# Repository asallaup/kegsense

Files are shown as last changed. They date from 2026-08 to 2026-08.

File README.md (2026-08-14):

# Sallaup KegSense

Keg weight/level monitoring for a keezer, by **Sallaup Electronics**.

Each keg sits on a load cell. A per-keg board reads the weight and sends
it over a wired connection to a central unit, which streams each keg's
brew name + weight out to a small OLED mounted right at that keg's own
tap (its own tiny MCU drives the display, right where you're pouring
from) and mirrors the same view to a web dashboard you can check
remotely — so you know how much beer is left without opening the lid.

## System overview

```
 Keg 1  --RJ11-->  |                |
 Keg 2  --RJ11-->  |     KegHub     |  --RJ45-->  KegStation
 Keg 3  --RJ11-->  |   (passive     |             (Raspberry Pi,
 Keg 4  --RJ11-->  |    wiring      |              web dashboard)
 Keg 5  --RJ11-->  |    panel)      |                   |
                    |                |                   v
                                              KegDisplay chain (OLED +
                                              Trinket M0 per tap, daisy-
                                              chained tap to tap)
```

Each keg's board is a **KegSensor** module (HX711 + 4 half-bridge strain
gauge sensors + RJ11 out). No Wi-Fi or radio anywhere inside or on the
keezer itself — everything in there is wired; KegStation, which sits
outside the keezer, is the only part with Wi-Fi (for the dashboard).

## Status

- 🚧 **KegSensor** (per-keg module) — **draft design**, still likely to
  change. Schematic + PCB routed and DRC-clean, 3D-printable case
  designed and validated, fab-ready Gerbers generated — but none of it
  has been physically built, and it hasn't been ordered/printed yet.
  Treat as a working draft, not a locked design, until it's been through
  a real build.
- 🚧 **KegHub** (in-keezer passive wiring panel) — wiring design
  (RJ11/RJ45 pin conventions, parts list) documented; physical build not
  started.
- 🚧 **KegStation** (central unit) — architecture decisions documented
  (platform, Wi-Fi provisioning, update mechanism, KegSensor-interfacing
  daemon language); no hardware or software built yet.
- 🚧 **Keg platform** (load cell mounting) — one part done: a derived,
  validated OpenSCAD load cell holder. Top/bottom mounting plates around
  it not designed yet.

## Repo layout

- [`hardware/kegsensor/`](hardware/kegsensor/) — KegSensor: per-keg
  sensor wiring (RJ11 pin conventions, parts list), KiCad schematic/PCB
  project, 3D-printable case (OpenSCAD), fab-ready Gerbers, and the load
  cell platform holder. See its own README(s) for details, known
  assumptions to verify against real hardware, and how to regenerate
  everything.
- [`hardware/keghub/`](hardware/keghub/) — KegHub: the in-keezer passive
  wiring panel design (RJ45 pin conventions, parts list, bench-test
  checklist).
- [`hardware/kegstation/`](hardware/kegstation/) — KegStation (central
  unit) planning doc: decisions made so far and what's still open.
- [`hardware/kegdisplay/`](hardware/kegdisplay/) — KegDisplay (per-keg
  tap indicator) planning doc: a small OLED + its own Trinket M0 MCU per
  tap, daisy-chained back to KegStation, each tap showing its own keg's
  brew name + weight directly.

## Before ordering/building anything

Both `hardware/kegsensor/README.md` and `hardware/kegsensor/wiring.md`
flag specific assumptions (HX711 module pin order, sensor diagonal
wiring) that need confirming against the actual parts once they're in
hand — cheap to fix now, annoying after boards are fabricated.

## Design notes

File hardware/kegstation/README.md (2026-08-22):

# KegStation — Sallaup Electronics

Part of the **Sallaup KegSense** keg-monitoring system, made by
**Sallaup Electronics**.

**KegStation** is the central unit: reads all 5 KegSensor modules over
the wired in-keezer hub connection, drives each tap's WS2812 fill-bar
LEDs directly (see [`../kegdisplay/`](../kegdisplay/) — no per-tap
MCU, KegStation lights however many LEDs correspond to that keg's
remaining %), and hosts a web dashboard mirroring the same information
remotely. Brew-name display is a separate concern, handled (if built)
by the experimental [`../kegtag/`](../kegtag/) add-on and its own hub,
not by KegStation streaming text down the LED chain.

This is a planning doc — no hardware or software has been built yet.
Captures decisions made so far so they aren't lost before implementation
starts (see `hardware/kegsensor/wiring.md` and `hardware/keghub/README.md`
for the equivalent docs that preceded the KegSensor module).

## Decisions so far

- **Platform: Raspberry Pi Zero 2 W, settled — not Pi 4, Pi 5, or a
  larger board.** Originally Pi 4, picked over Zero 2 W solely because
  the (now-dropped, see Touchscreen/display below) Touch Display 2
  needed a DSI connector the Zero series doesn't have — once the display
  requirement changed to a button-driven I2C OLED, that blocker went
  away and Zero 2 W became the smallest/cheapest board that still meets
  every other requirement. Still ruled out vs. Pi 5 for the same reasons
  as before: power budget (Pi 5 draws roughly double idle power and
  wants a 27W supply, inflating the shared-PSU sizing above for headroom
  this project's workload doesn't need) and GPIO library maturity
  (`pigpio`, the battle-tested choice for the HX711's precise bit-banged
  timing, does not support Pi 5's RP1 GPIO chip at all). Zero 2 W's
  SoC (RP3A0) uses the same classic GPIO peripheral family as Pi 3/4,
  not Pi 5's RP1, so `pigpio` and the whole KegSensor-interfacing scheme
  below carry over unchanged. Has built-in Wi-Fi (2.4GHz only, unlike Pi
  4's dual-band — irrelevant here, Comitup's captive portal works fine
  over 2.4GHz) + Bluetooth 4.2/BLE (also unused by KegStation itself),
  so still no wireless add-on hardware needed. Fixed at 512MB RAM (no
  variants) — expected to be plenty given the now-lighter workload (no
  browser/desktop GUI, just the C daemon, the button/OLED interface, and
  a modest web dashboard), though with less margin than the Pi 4 RAM
  options would have had.
- **Connectivity**: reads the 5× KegSensor modules over the wired hub
  connection (shared SCK + 5× DT + power, see
  `hardware/kegsensor/wiring.md` and `hardware/keghub/README.md`) —
  direct to the Pi's GPIO header, 3.3V logic throughout, no level
  shifters needed. No Wi-Fi/radio inside the keezer itself (unchanged
  from the original hub design constraint) — KegStation sits outside the
  keezer, so its own Wi-Fi is unrelated to that constraint.
  - **Bench/debug connector, settled: a 6th, dedicated DT channel — not
    shared with any of the 5 production kegs.** A second RJ14 (6P4C)
    jack, same connector type as KegSensor's own J7, mounted directly on
    KegStation, for plugging in and testing a spare KegSensor without
    touching KegHub or any deployed keg. Shares the common SCK/3.3V/GND
    rails (safe — those are shared across all kegs anyway) but gets its
    **own dedicated DT GPIO pin**, deliberately not reusing one of the 5
    production DT lines: sharing a DT line would mean two HX711 modules
    could end up driving the same GPIO simultaneously if a real keg is
    plugged into KegHub at the same time as a test sensor here — a real
    electrical bus-contention risk, not just a software mixup. One extra
    GPIO pin is cheap on Zero 2 W's 40-pin header (no touchscreen, and
    discrete buttons instead of a component-heavy nav switch, both free
    up pins), so paying that cost to remove a real correctness risk is
    worth it. The daemon reads this 6th channel too, but keeps it out of
    the normal 5-keg dashboard/fill-bar logic — surfaced only through a
    separate bench-test view, not mixed into live readings.
- **Wi-Fi provisioning**: [Comitup](https://davesteele.github.io/comitup/)
  — Pi broadcasts a captive-portal setup network (SSID `KegStation-Setup`)
  on first boot / when no known network is available, works from any
  phone's browser via the OS-level captive-portal mechanism (no app
  needed, no Web Bluetooth iOS limitation). Chosen over BLE provisioning,
  which has no mature ready-made tool on Linux/Raspberry Pi.
  - **Branding**: Comitup's setup pages (`comitup_web/templates/` —
    `index.html`/`connect.html`/`confirm.html` + `css`/`js`/`images`) are
    plain by default (no existing logo to fight against), but the
    template path is hardcoded in `comitupweb.py`
    (`/usr/share/comitup/templates`, confirmed by reading the source —
    no config/env override exists). Branding means overwriting those
    installed files with our own after installing the `comitup` package,
    as part of KegStation's own setup script — and re-applying that after
    any future `comitup` package upgrade, since there's no supported way
    to point it at a separate custom template directory.
- **Software updates**: git-based. KegStation's code lives in a git repo
  on the Pi; updating is `git pull` + restart the service, rollback is
  checking out a previous tag. Deliberately not a fleet OTA framework
  (Mender, balena) — this is one device, not a fleet.
  - **Trigger**: manual button in the web dashboard (an admin
    action that runs the pull + restart on demand) — not automatic on a
    schedule, so an update never lands unannounced (e.g. mid-party), and
    not SSH-only, so it doesn't require terminal access for routine use.
- **KegSensor-interfacing layer: C.** The HX711 protocol needs precise
  clock-pulse timing to bit-bang correctly (shared SCK + 5× DT, per
  `hardware/kegsensor/wiring.md`) — C gives predictable low-level GPIO control
  that's harder to guarantee in a higher-level language. This is scoped
  specifically to the hardware-interfacing piece, not necessarily the
  rest of KegStation's software (dashboard, etc. — still open, below).
  - **Interface to the rest of the system**: a small daemon, written in
    C, that reads all 5 kegs on a fixed interval and writes current
    readings to a local JSON/text file. Whatever ends up driving the
    KegDisplay LED chain and web dashboard just reads that file —
    simplest possible hand-off, easy to debug by hand (`cat` the file),
    no IPC to build or maintain. Chosen over a Unix socket/local IPC
    (more real-time, more moving parts) and over having the C program
    also drive the LED chain/dashboard directly (would remove the
    option to pick a different, easier language for that higher-level
    part later).
  - **GPIO library: `pigpio`.** The traditional, most battle-tested
    choice for the HX711's precise bit-banged clock timing — viable now
    that Pi 4 is settled (below), unlike on Pi 5 where it doesn't
    support the RP1 GPIO chip at all.
  - **Disconnected-cable detection: a per-keg DT timeout watchdog,
    settled.** The RJ14 wiring has no spare conductor for a dedicated
    presence-detect signal (all 4 — GND/VCC/SCK/DT — are already used),
    so detection is inferred from HX711 protocol behavior instead: each
    keg's DT line should pulse low on every new conversion (~100ms or
    ~12.5ms depending on the HX711's rate setting). If a keg's DT line
    produces no valid ready-pulse within 2-3× that interval, the daemon
    marks that keg as **not responding** rather than reporting a stale
    or garbage weight. The DT input needs an internal or external
    pull-up so "disconnected" reads as a consistent, predictable HIGH
    instead of noisy floating, making the timeout check reliable
    instead of racy. Surfaced as a distinct per-keg status in the
    readings file (not folded into the weight/percentage fields) — see
    Display + input below for how it's shown on-unit, and note
    KegDisplay's per-tap fill bar shouldn't just show 0% for this case
    either, since that reads as "keg is empty" rather than "sensor
    isn't talking" (still open, see KegDisplay's own README).
- **Tare/weight calibration: must work fully standalone at the unit
  itself — no web browser and no external device (phone/laptop/SSH)
  required.** This is a hard requirement, not a convenience preference,
  so the on-unit button + OLED interface (below) is the primary
  calibration interface. A `kegcal` CLI program still exists underneath
  as the actual implementation (and an SSH-accessible fallback for
  development/debugging) — the button/OLED UI shells out to the same
  commands rather than duplicating calibration logic, same relationship
  originally planned between `kegcal` and a future dashboard, just with
  the button/OLED interface as the primary caller instead of the web
  dashboard.
  - `kegcal tare <keg>` — reads that keg's *current* raw ADC value (from
    the daemon's readings file) and stores it as the tare reference.
  - `kegcal setfull <keg> <grams>` — same, but stores it as the "full"
    reference point at a known weight in grams. That known weight can be
    either the actual full keg's spec weight (so the reference doubles as
    the "how much is left" baseline) or a separate known calibration
    mass — the tool works the same either way, this only affects what
    number you type in.
  - **On-unit UI note**: the button/nav-switch interface offers Set Full
    as a **preset selection** (e.g. 5/10/15/20kg), not free numeric
    entry — implementing the "actual full keg's spec weight" option
    above via list-selection rather than typing a number, consistent
    with every other step in the flow being a scroll-and-select action
    (see Display + input above). The presets must be the *real* spec
    weight (liquid + keg tare) of whatever keg sizes are actually in
    use, not round numbers — an inaccurate preset introduces a
    systematic error across every future reading for that keg, since
    it directly anchors the calibration math. `kegcal setfull` itself
    is unaffected — it still just takes a gram value; only the on-unit
    UI constrains which values are offered.
  - **On-unit calibration wizard, designed**: tare and setfull are one
    continuous guided flow, not two separate manual actions, with a
    confirmation prompt gating each raw-ADC read so a mistimed press
    can't bake in a bad calibration point:
    1. Select **Tare** from the keg's menu (nav switch)
    2. Prompt: "Place empty keg on scale, then confirm" — user places
       it, presses select
    3. System reads the current raw ADC → internally calls
       `kegcal tare <keg>`, stores it as the 0% reference
    4. Prompt: select a known full weight (the preset list above)
    5. Prompt: "Place [selected weight] on scale, then confirm" — user
       places the full keg (or a calibration mass matching that
       weight), presses select
    6. System reads the current raw ADC → internally calls
       `kegcal setfull <keg> <grams>` with the chosen preset value
    7. Both calibration points now stored — the daemon can compute
       that keg's tare↔full linear scale from here on
    - **A Back/cancel option at every confirmation prompt** — lets the
      user back out if the keg isn't actually placed right or the
      wrong preset got selected, rather than being forced through to a
      bad read.
  - Calibration values live in a separate config file (e.g.
    `calibration.json`), which the daemon just re-reads on its normal
    cycle — no signaling/IPC needed for `kegcal` to take effect.
  - The daemon's readings file includes both the raw ADC count and the
    calibrated weight (once calibration exists) per keg, since `kegcal`
    needs to read the live raw value to know what to record.
  - **Not yet built** — see below.
- **Per-tap indicator is just an LED fill level now, no per-tap
  detail/MCU at all.** Each tap's WS2812 bar (see
  [`../kegdisplay/README.md`](../kegdisplay/README.md)) is lit directly
  by KegStation over the shared chain — no brew name, no numeric
  weight, no OLED, no per-tap microcontroller. This superseded both the
  earlier button + resistor-ladder + KegStation-touchscreen scheme and
  the later ATtiny1614+OLED-per-tap scheme (see git history and
  KegDisplay's own revision note) — no button/detail hardware to read
  at any tap.
  - **Wiring run this still creates**: KegStation sits outside the
    keezer (see System overview in the root README), but taps are
    mounted at the keezer itself, so a physical run out to each tap is
    still needed regardless of what's at the far end — a wired
    connection either way (consistent with the no-WiFi-in-the-keezer
    rule, which is about radios, not wired signals).
  - **KegStation's job for this chain**: light however many LEDs
    correspond to each keg's remaining % as a bottom-up fill bar, in
    tap order down the KegDisplay daisy chain (see the chain-position
    addressing scheme in KegDisplay's own README) — not yet
    implemented, see Still Open.
- **Power: one shared 5V supply, star-wired — not drawn through the
  Pi's own GPIO pin/trace.** A single 5V PSU, sized for worst-case total
  draw (Pi + KegSensor bus + KegDisplay LEDs), feeds two separate direct
  wire runs: one straight to the Pi (its own 5V input), one straight to
  the KegDisplay chain's power input — neither run passes through the
  other. The actual hard requirement was never "two physical supplies,"
  it was "LED current must never pass through the Pi's own GPIO 5V
  pin/trace" (see Why below) — one adequately-sized PSU with star wiring
  satisfies that just as well as two separate PSUs would, with less
  hardware.
  - **Why the Pi can't just pass LED current through**: WS2812 LEDs draw
    up to ~60mA each at full white (20mA × 3 channels). ~18-26 LEDs/tap
    × 5 taps ≈ 130 LEDs total → up to ~7.8A (~39W) worst case,
    realistically a few amps even at moderate brightness — more than the
    Pi's GPIO 5V pin/trace is rated to pass through, regardless of what
    supplies it. Standard WS2812 practice regardless of platform: the
    LED chain's power connects directly to its supply, not routed
    through the controller board.
  - **Tradeoff accepted by sharing one PSU**: an LED-side short/
    overcurrent event could brown out the whole shared supply, taking
    the Pi (touchscreen/calibration/reset) down with it — two
    independent PSUs would isolate that risk, one shared PSU does not.
    Accepted here in favor of one fewer component.
  - **PSU model: Mean Well GST60A05-P1J (5V, 6A, 30W), settled — paired
    with a mandatory software brightness/current cap.** Theoretical
    worst case (130 LEDs × 60mA full-white + Pi's ~1.5A) is ~9.3A, well
    past this unit's 6A rating — Mean Well's built-in overload
    protection fails safe (hiccup-mode shutdown) rather than
    dangerously, but a trip still browns out the Pi along with the
    LEDs (see Tradeoff above), so the LED-driving code (see Still Open)
    **must** cap total simultaneous current with margin under 6A —
    e.g. single-channel color instead of white, and/or an explicit
    brightness ceiling — not just assume typical usage stays low.
    Picked over the 10A Mean Well LRS-50-5 alternative (which needs no
    software cap) for its smaller size (125×50×31.5mm captive-cable
    wall-wart vs. 128×97×38mm screw-terminal box) and simpler
    plug-and-play wiring (captive DC cable + standard IEC C14 cord,
    vs. terminating both AC and DC leads by hand).
  - **Physical implementation: a plain fixed 5V DC power brick
    (the GST60A05 above), not a USB-C PD charger.** A generic
    USB-C PD wall charger's default/fallback output (before any
    negotiation) is typically just 5V at a modest current (often 3A) —
    getting more current specifically *at* 5V, rather than the charger
    bumping voltage up instead, needs either a PD-trigger chip
    negotiating for it or a charger that happens to default that way,
    neither guaranteed. A plain fixed-5V brick sidesteps that entirely:
    no negotiation, current rating is just whatever the brick is rated
    for. Its 5V/GND wires go into a small **non-negotiating USB-C
    breakout board** (just exposes VBUS/GND pads with basic CC
    pull-down resistors, no PD chip) mounted as the single external
    power-entry connector on the KegStation enclosure — the Pi's own
    onboard USB-C port stays unused/hidden inside the case. From the
    breakout's pads, two star-wired runs go out: one to the **Pi's GPIO
    5V pin** (bypassing its onboard USB-C port), one straight to **J1's
    5V/GND** for the LED chain — same star topology as before, just with
    a concrete connector at the wall-facing end instead of bare PSU
    leads.
  - **Considered and rejected: an internal 220V AC→5V DC module** (e.g.
    Mean Well RS-25-5), with just a mains cord entering the enclosure
    instead of an external DC brick. Rejected because it brings mains
    voltage inside a custom DIY enclosure — a different safety class
    than a certified external wall-wart, needing its own fusing,
    creepage/clearance, and an isolated compartment to get right, none
    of which is worth taking on for a one-off hobby build vs. buying an
    already UL/CE-certified external supply.
  - **Also considered and declined: a panel-mount IEC C14 inlet on the
    enclosure with the PSU module mounted inside it** (safer than the
    fully-DIY version above, since both the inlet — typically bundled
    with its own fuse holder/switch — and the PSU module itself would
    still be pre-certified parts). Declined anyway to keep it simple:
    the external brick stays external, KegStation's only power connector
    is the low-voltage USB-C breakout.
  - See `power_wiring_diagram.png` (`generate_power_wiring_diagram.py`)
    for the star-topology layout: the Pi and the KegDisplay chain each
    run their own wire straight back to the shared PSU. The PSU's 5V/GND
    and the Pi's DATA line stay separate conductors electrically but
    physically converge at J1 (KegDisplay's existing 3-pin JST-PH
    chain-in connector) into one cable for the run out to tap 1 —
    bundling into one physical cable is fine, it's only the electrical
    source of each conductor that has to stay separate.
- **One external-to-the-Pi component needed: a logic-level shifter IC
  on the KegDisplay DATA line.** KegHub/KegSensor need none (3.3V logic
  throughout, see Connectivity above) — but KegDisplay's WS2812 strip is
  a 5V logic part, expecting a DATA-high signal above roughly 0.7×VDD ≈
  3.5V, and the Pi's GPIO only outputs 3.3V. That's marginal enough
  (a well-known flaky case for Pi+WS2812 projects, especially at the
  *first* LED — every LED after that regenerates the signal at its own
  full 5V output) that a small one-chip level shifter (e.g. 74AHCT125 or
  74HCT14) belongs between the Pi's DATA GPIO pin and J1's DIN. One
  small IC, only needed at that single connection point, powered off the
  same shared 5V rail. **Not yet added to the BOM/wiring** — see the
  updated `power_wiring_diagram.png`.
- **PIR motion sensor for occupancy-based LED power saving: HC-SR501,
  settled.** The KegDisplay chain doesn't need to stay lit when nobody's
  in the room — running all 5 taps' LEDs continuously is the dominant
  chunk of the power budget the GST60A05 (above) is already sized close
  to the edge of. The HC-SR501 (~$1-2, 3-pin VCC/GND/OUT) wired to one
  Pi GPIO pin detects room entry; its digital output is already
  3.3V-logic level, so — unlike the WS2812 DATA line — **no level
  shifter needed** for this one. Another small external-to-the-Pi
  component, but a simple, well-supported one.
  - **Behavior**: motion resets an inactivity timer in the LED-driving
    code; while the timer's running, the chain shows the normal
    fill-bar; on timeout with no further motion, the chain **dims to a
    low brightness** (settled — not a full blank), cutting most but not
    all of the LED power draw while keeping a faint always-visible
    fill-level readable at a glance, then returns to normal brightness
    on the next motion event.
  - **Mounting location: on the KegStation enclosure itself, settled.**
    No remote sensor needed — KegStation already sits in the same room
    as the keezer (see System overview in the root README), so a PIR
    mounted on its own case covers room-entry detection without a
    separate wired/wireless sensor unit.
  - **Inactivity timeout: user-configurable, settled** — not a
    hardcoded constant. Lives in the same config file the daemon
    already re-reads on its normal cycle (alongside `calibration.json`,
    see Tare/weight calibration above), so it's adjustable without a
    code change or restart-losing edit — a sensible default ships, but
    the actual duration is a setting, not a fixed value baked into the
    LED-driving code.
  - **Dimmed brightness level: 15% of normal, settled** — low end of
    the tradeoff (favors power savings over glance-readability from
    across the room), still configurable like the timeout above rather
    than hardcoded, 15% is just the shipped default.
  - **Not yet decided**: the default timeout duration.
- **Two distinct reset mechanisms: soft reset via power cycling (no
  dedicated button), factory reset via a dedicated physical button.**
  - **Soft reset = power off/on.** Just reboots the Pi/services, no data
    touched (WiFi creds, calibration all survive) — no dedicated button
    needed, a power switch (or just unplugging) already does this.
  - **Factory reset = a recessed pinhole button** (needs a pin/paperclip
    to press, like a router's reset — not something bumped by accident),
    wired to a GPIO the daemon watches. Held ~5-10s: clears WiFi
    credentials (falls back to Comitup's setup portal) and wipes
    `calibration.json`. Deliberately a physical button, not a
    software menu item — has to work even if the display UI or
    software is hung/misconfigured, which is exactly the case a factory
    reset needs to recover from.
- **Display + input: a 4.0" color IPS TFT (ILI9488, 480×320, "No Touch"
  variant) plus physical navigation buttons, not a touchscreen.**
  Superseded an intermediate plan (2.42" monochrome I2C OLED, see git
  history) — chosen over that OLED specifically for future headroom:
  a 480×320 color panel leaves real room to grow the on-unit UI later
  (WiFi signal bars, brew name, per-keg level graphs, multiple fields
  at once) without another hardware swap, which the OLED's 128×64
  monochrome canvas couldn't accommodate gracefully. Both options were
  chosen over the official Raspberry Pi Touch Display 2 (5", SC1975,
  ~$40/€53) to cut cost — that touchscreen was the single largest line
  item in KegStation's BOM, and dropping it also unblocked the Platform
  change to Zero 2 W above (the Touch Display 2's DSI requirement was
  the only thing ruling Zero 2 W out). Buttons still satisfy the
  standalone-calibration hard requirement below just as well as a
  touchscreen — the touchscreen was originally picked for being the
  *simplest* single-component option ("no separate buttons/encoder to
  wire up"), not because buttons don't work.
  - **"No Touch" variant, deliberately** — a touch variant exists on the
    same listing, but adding touch back would partly undo the reason
    the Touch Display 2 was dropped, and the design already commits to
    buttons for input.
  - **Interface: SPI** (~8 pins without touch: VCC, GND, CS, RESET, DC,
    SDI/MOSI, SCK, LED backlight) — more GPIO than the OLED option's 2
    pins (SDA/SCL) would have used, but Zero 2 W's 40-pin header still
    has plenty of room alongside the navigation buttons, PIR sensor, and
    factory-reset button.
  - **UI approach: a lightweight embedded graphics library** (e.g.
    LVGL-style), not a browser/desktop stack — keeps the richer color UI
    well within Zero 2 W's 512MB RAM, same conclusion as the OLED plan
    reached, just confirmed explicitly for the bigger screen too.
  - **Driver note**: at least one buyer of this exact listing received
    an ILI9484-branded chip instead of the advertised ILI9488 ("tho
    functionally perfect") — worth being ready to try adjacent
    ILI948x drivers in software if the advertised one doesn't
    immediately work, same generic-module caveat as the OLED's
    SSD1306-vs-SSD1309 mismatch.
  - **Input: a 5-way tactile navigation switch (up/down/left/right +
    center select), settled — not discrete buttons, not a rotary
    encoder.** 5 GPIO pins, each a simple digital read (no quadrature
    decoding). Chosen over a rotary encoder specifically because the
    on-unit UI is planned to grow into a genuinely 2D layout later
    (multiple screens/tabs navigated left/right, e.g. WiFi signal,
    brew info — see Display note above) — a rotary encoder only gives
    one rotational axis, which fits a purely linear list-menu well but
    not a 2D one. Traded away the encoder's main advantage (fast,
    precise numeric entry) deliberately, since the one place that
    mattered — Set Full's weight value — moved to preset selection
    instead (see Tare/weight calibration below), removing the need for
    free numeric entry entirely. Not yet wired — GPIO pin assignment
    not yet decided (see Still Open).
  - Still satisfies "no per-tap detail/MCU" below — this is KegStation's
    own on-unit display, unrelated to the per-tap LED fill bars.
  - **Sensor-connection status: red/green per-keg indicator, settled.**
    Reflects the DT timeout watchdog above directly — green means that
    keg's HX711 is responding normally, red means it's not (cable
    unplugged, unpowered module, or a dead sensor — the daemon can't
    distinguish which, just that the keg isn't reporting). Shown
    per-keg on the main screen alongside each keg's fill level, so a
    disconnected sensor is obvious at a glance rather than silently
    reading as an empty keg.

## Still open

- **All of the above C daemon / `kegcal` work is design-only, not yet
  implemented.** Deliberately holding off writing the code until a
  physical Raspberry Pi + HX711 setup exists to test against, rather than
  writing GPIO-bit-banging code that can only be verified once real
  hardware shows up — the risk of subtle timing/wiring bugs surviving
  unnoticed in untestable code isn't worth it here (same reasoning as
  everything else in this project: validate against something real
  before calling it done, not just "it compiles").

- Software language/stack for everything *other* than the KegSensor
  interfacing daemon (Python is the natural fit for the Pi's web
  library support, but not yet committed to) — the daemon just needs to
  read a file, so it can be written in anything.
- Whether to build a small interface PCB (breaking out the hub's RJ45
  connection and the KegDisplay chain's UART-ish GPIO pins to the Pi's
  header) or wire it directly on a protoboard/HAT — these are native Pi
  GPIO peripherals, no special adapter needed, unlike the original
  RS-485 design's USB-RS485 requirement.
- **KegStation's own KegDisplay-chain code**: the piece that reads the
  daemon's readings file and lights each tap's LED fill bar to match
  its keg's remaining % — not yet written (see
  [`../kegdisplay/README.md`](../kegdisplay/README.md) for the chain
  protocol's own still-open details). **Must include a current/
  brightness cap** (color choice + max brightness ceiling) keeping
  total worst-case draw safely under the GST60A05's 6A — see Power
  above for why this is a hard requirement, not a nice-to-have. **Must
  also include the PIR-driven occupancy timer** (see PIR motion sensor
  above) that dims the chain when the room's been empty past the
  timeout.
- **Calibration UI's own screen flow — now designed**, see the on-unit
  calibration wizard under Tare/weight calibration above. Not yet
  implemented in code, and GPIO pin assignment for the 5-way nav
  switch isn't decided either.
- Web dashboard framework, exact GPIO pin mapping for the shared-SCK +
  5×DT KegSensor scheme (now 6×DT including the dedicated bench/debug
  channel above), and the on-disk format/path for the readings file the
  C daemon writes.
- Physical enclosure for KegStation itself (separate from the KegSensor
  case already built) — depends on the display/button decision above,
  and now also needs a pinhole cutout reaching the factory-reset button.
- **Factory-reset daemon logic and GPIO pin choice** — not yet written;
  needs to debounce/time the ~5-10s hold, then clear WiFi creds +
  `calibration.json` and restart the relevant services.
- **LED supply sizing and injection point** — exact PSU wattage (depends
  on final LED count once a strip is picked, and whatever brightness/
  color policy the fill-bar code ends up using), and where in the
  KegHub/KegDisplay wiring the injected 5V actually connects.

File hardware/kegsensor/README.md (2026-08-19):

# KegSensor — Sallaup Electronics

Part of the **Sallaup KegSense** keg-monitoring system, made by
**Sallaup Electronics**.

**KegSensor** is the per-keg carrier board: hosts the HX711 breakout
module, terminates the 4 half-bridge sensor leads (bussed/paired per
`wiring.md`), and exits to the in-keezer hub over RJ11. One board
per keg.

KiCad 9 project. Both schematic and PCB (footprints placed, fully routed,
2-layer) are done and validated (see Validation below).

## Fabrication

**Send `KegSensor_RevA_gerbers.zip` to the PCB manufacturer.** That's the
complete, standard deliverable — a fab house doesn't need the `.kicad_pcb`
file itself (though most modern ones, e.g. JLCPCB/PCBWay, also accept it
directly if you'd rather skip the export step). It contains, generated via
`kicad-cli pcb export gerbers`/`export drill`:

| File | Contents |
|---|---|
| `*-F_Cu.gtl` / `*-B_Cu.gbl` | Copper layers (top/bottom) |
| `*-F_Mask.gts` / `*-B_Mask.gbs` | Soldermask |
| `*-F_Silkscreen.gto` / `*-B_Silkscreen.gbo` | Silkscreen (incl. the KegSensor/Rev A branding) |
| `*-F_Paste.gtp` / `*-B_Paste.gbp` | Solder paste stencil (only matters if you're getting a stencil cut too) |
| `*-Edge_Cuts.gm1` | Board outline |
| `*-job.gbrjob` | Gerber job file (metadata some fabs use to auto-detect stackup) |
| `*-PTH.drl` / `*-NPTH.drl` | Drill files — plated (component holes) and non-plated (J7's 2 mounting bosses) separately |

The individual files are also in `fab/` (not zipped) if a fab's upload
tool wants them one at a time rather than as an archive, along with
`*-drl_map.pdf` drill maps (human-readable cross-reference of hole
sizes/positions — not needed by the fab, just useful if you want to
sanity-check the drill file yourself).

**Order quantity**: 5 (one per keg) — check the fab's pricing breaks
first, since many charge nearly the same for 5 as for 10.

**Before ordering**: resolve the two items under Known assumptions below
(J6 pin order, SIG_POS/SIG_NEG diagonal pairing) if you haven't already —
both require rerouting, which is easy to do before fabrication and
annoying after.

Regenerate the fab package after any board changes:
```
kicad-cli pcb export gerbers --layers "F.Cu,B.Cu,F.Paste,B.Paste,F.SilkS,B.SilkS,F.Mask,B.Mask,Edge.Cuts" -o fab/ keg_sensor_module.kicad_pcb
kicad-cli pcb export drill --format excellon --excellon-separate-th --excellon-units mm --generate-map --map-format pdf -o fab/ keg_sensor_module.kicad_pcb
```

## Files

- `keg_sensor_module.kicad_pro` — project file, open this in KiCad
- `keg_sensor_module.kicad_sch` — schematic (see `keg_sensor_module.pdf` for
  a quick look without opening KiCad)
- `keg_sensor_module.kicad_pcb` — routed board, 155×90mm outline, 4× M3
  clearance mounting holes at the corners (6,6)/(150,6)/(6,84)/(150,84)
  board-local (see `keg_sensor_module_top.png` / `_bottom.png` for a quick
  look, or `keg_sensor_module_3d.png` for an isometric render with real
  component shapes)
- `case.scad`, `case_base.stl`, `case_lid.stl` — 3D-printable enclosure,
  see Case below
- `generate_schematic.py` / `generate_pcb.py` — the scripts that generated
  the two files above. If a pin-order assumption turns out wrong once you
  have the real hardware in hand (see Known assumptions below), fix it in
  the script and rerun rather than hand-editing the `.kicad_sch`/`.kicad_pcb`
  text. Requires `pip install sexpdata` and a local KiCad 9 install (the
  scripts read symbol/footprint definitions straight out of
  `/Applications/KiCad/KiCad.app/Contents/SharedSupport/`).
  **If you have this project open in KiCad while regenerating, close and
  reopen the PCB editor afterward** — the scripts overwrite the file on
  disk directly, which KiCad won't pick up in an already-open editor.

## Connectors

| Ref | Part | Pins |
|-----|---|---|
| J1 | Screw terminal, sensor "FL" corner | 1=E+ (Red) 2=E- (Black) 3=Signal (White) |
| J2 | Screw terminal, sensor "FR" corner | 1=E+ (Red) 2=E- (Black) 3=Signal (White) |
| J3 | Screw terminal, sensor "BR" corner | 1=E+ (Red) 2=E- (Black) 3=Signal (White) |
| J4 | Screw terminal, sensor "BL" corner | 1=E+ (Red) 2=E- (Black) 3=Signal (White) |
| J5 | Female header, HX711 load-cell side | 1=E+ 2=E- 3=A+ 4=A- |
| J6 | Female header, HX711 digital/power side | 1=GND 2=DT 3=SCK 4=VCC |
| J7 | RJ11 jack to hub (RJ14 6P4C) | 1=GND 2=VCC 3=SCK 4=DT |

Nets: `EXC_POS`/`EXC_NEG` bus J1–J4 pin1/pin2 into J5; `SIG_POS` ties
J1+J3's signal leads (diagonal) into J5.A+, `SIG_NEG` ties J2+J4's into
J5.A-; J6↔J7 pass GND/DT/SCK/VCC straight through to the hub cable.

## Known assumptions to confirm against real hardware

- **J6 pin order (GND,DT,SCK,VCC)** is a common layout for these HX711
  breakouts but varies by manufacturer — check your module's silkscreen
  before soldering the header, fix in `generate_schematic.py` if different.
- **Diagonal pairing (J1+J3→SIG_POS, J2+J4→SIG_NEG)** depends on which
  corner each sensor physically sits at and its mounting orientation —
  follow the kit's included wiring diagram; if the reading comes out
  inverted or dead-flat, swap the SIG_POS/SIG_NEG pairing.
- **J7 uses KiCad's stock RJ14 (Connfly DS1133-S4) footprint** — a genuine
  6P4C connector (6-position body, 4 contacts), which is mechanically what
  "RJ11" means in practice for a 4-wire line cord (RJ9, used in an earlier
  draft of this board, is a different 4P4C body meant for phone handset
  cords, not line cords — swapped out after review). Still worth checking
  the exact part you buy against this footprint's dimensions before
  ordering the board, since real-world RJ11 jacks vary in body/pin
  spacing between manufacturers.

## Pending design change (decided, not yet applied to the KiCad files)

- **J1-J4 switching from `TerminalBlock_bornier-3_P5.08mm` to
  `TerminalBlock_Phoenix_PT-1,5-3-3.5-H_1x03_P3.50mm_Horizontal`** —
  3.5mm pitch instead of 5.08mm, to shrink the board. Checked two 3.5mm
  candidates before picking, since pitch alone doesn't guarantee a
  smaller footprint: WAGO 2601-1103 (3.5mm pitch, but 13×15.5mm
  courtyard — *taller* than the current part, would make the board
  worse in the already-tight Y direction) vs. **Phoenix
  PT-1,5-3-3.5-H** (3.5mm pitch, 11.5×8.6mm courtyard — narrower than
  the current 15.6×8mm, same horizontal thin-profile mounting style).
  Phoenix is the one to use.
  - **Not yet applied** — `generate_schematic.py` (footprint string +
    `PIN_DX` pin spacing, currently tuned for 5.08mm) and
    `generate_pcb.py` (J1-J4 placement/routing, extensively DRC-iterated
    around the current footprint's exact pad positions — see Routing
    below) both need rework, not just a footprint-string swap.
  - **Deliberately deferred to Phase 6** of `IMPLEMENTATION_PLAN.md` —
    the first prototype is being hand-wired on perfboard, not the
    custom PCB, so this change isn't blocking anything yet. Apply it
    once Phase 5 passes and the real PCB actually gets ordered.

## Physical layout

Sensor terminals (J1–J4) sit in a horizontal row close to the board's top
edge (y≈10, 30mm pitch), ordered FL/BR/FR/BL left-to-right (not source
order) so the diagonal pairs (SIG_POS = J1+J3, SIG_NEG = J2+J4) sit next to
each other. Unrotated (angle=0, the library's default orientation) — an
earlier version rotated each part -90° to make the bus routing trivial
(every part's pins landing on their own single x instead of sharing a y
with every other part's pins), but that was a routing convenience, not a
requirement; unrotated works too, it just needs more deliberate lane/layer
routing (see below). J5 (HX711 load-cell side) sits below the row, on the
same side — these are the noise-sensitive analog connections, kept short
and away from the digital/power section. J6 (HX711 digital side) sits with
J5; J7 (RJ11 to hub) is rotated 180° and placed flush with the board's
*bottom* edge (y=90) — moved here from the right edge. Any edge-mounted
connector belongs at the board edge as a matter of course, independent of
the case (this board had a real bug once from *not* following that rule —
J7 originally sat mid-board with no edge access at all; see git history).

Each of J1-J4 has "R B W" silkscreened directly above its 3 pins, one
letter per pin, matching the sensor lead colors in the table above (Red
E+, Black E-, White Signal) — so wiring a sensor by color doesn't need
the README open next to the board. Fixed pin order (1=R, 2=B, 3=W) on
every connector regardless of which physical corner it's wired to.
Positioned in the gap between the board's top edge and each connector's
own body, clear of both the edge and each connector's reference
designator (checked via DRC's silk_overlap rule after placing it, not
just eyeballed).

J5 and J6 (the HX711 header pins) are labeled too — E+/E-/A+/A- and
GND/DT/SCK/VCC respectively, one per pin, matching the Connectors table
above. Both are `PinSocket_1x04_P2.54mm_Vertical`: a single column with
all 4 pins stacked in Y at one X (2.54mm pitch), unlike J1-J4's
horizontal row, so these labels go beside each pin rather than
above/below — there's no room between adjacent pins at that pitch for a
label. J5's sit on the left, J6's on the right (per explicit request —
opposite sides). J6's labels needed extra clearance from the footprint's
own outline (GND/SCK/VCC are 3 characters, wide enough at their first
position to clip it — DRC caught it, not eyeballing).

Routing uses both copper layers, extensively. With J1-J4 unrotated, every
one of their 12 pins (pin1/2/3 × 4 parts) sits at the exact same y=10 —
unlike the rotated layout, where each pin *number* got a fixed y shared by
all 4 parts (turning "pin N, every part" into one trivial straight bus),
here every net needs its own dedicated lane below the row plus vertical
drops from each of its own pins down to that lane, and since the 4 nets'
pin x-positions are interleaved across the same 20-110 span, a drop for a
"deeper" net's lane inevitably passes through a "shallower" net's lane at
some point along that span. EXC_POS and EXC_NEG (each needing the full row
width) are kept on separate copper layers entirely so crossing each other
in plan view isn't a short; SIG_POS/SIG_NEG only span half the row each,
but still have to get past *both* of those, so their drops explicitly hop
layers (via) at each crossing rather than relying on a single layer
choice. J7's move to the bottom edge similarly turned its own approach
into a small routing puzzle: GND and SCK's target pads are only 1.02mm
apart, so straight verticals into either one grazed the *other's*
neighbor pad (VCC) for their whole length — fixed with an offset
approach-and-jog into each pad's own y, and DT/SCK/GND's lanes had to be
depth-ordered (matching the order of their target x's) so a deeper lane's
horizontal run doesn't cross a shallower one's drop. Each net's initial
jog off of J6 goes east (toward J7), not west first — per explicit
request — which flips *which* net needs the shallowest lane: since every
lane then extends the rest of the way east to J7 regardless of where its
own stub sits, the depth/stub-position pairing that avoids crossings
turned out to be the mirror image of the west-jog version (shallowest
lane ↔ stub furthest from J6, not closest).

GND and SCK are each a single unbroken line on one layer (B.Cu and F.Cu
respectively), no vias — J6's pads are through-hole, so a track can just
start on whichever layer it needs directly at the pad; both had a
vestigial F.Cu stub in an earlier version that wasn't actually needed.
VCC_3V3 and DT can't drop theirs, though, and this isn't a missed
simplification — checked exhaustively, not just patched around the first
conflict DRC caught: VCC's own source row at J6 sits inside DT's drop's
depth range, and DT's row sits inside VCC's, so whichever one is "in the
way" at that crossing needs to be on the other layer right there. Two
vias is the minimum for this connector, not four.

See the comments in `generate_pcb.py` for the exact reasoning behind each
routing decision — several were only found by DRC catching a real short
or clearance violation, not worked out by eye in advance.

**Note on KiCad footprint rotation**: got this wrong once already — KiCad's
`(at x y angle)` rotation is the opposite sign of the standard math
convention (confirmed empirically by checking DRC's reported pad
coordinates against a hand-rotated prediction, the same way the schematic's
Y-axis quirk was caught earlier). J7 uses `angle=180` to point its cable
face toward +Y (the bottom edge); don't assume a given angle achieves a
given direction without checking actual reported pad/courtyard positions
first — that's what caught this, not reasoning from the formula alone.

## Next steps

1. Confirm the two assumptions above against your actual HX711 modules and
   kit wiring diagram; adjust and rerun `generate_schematic.py` (and
   `generate_pcb.py`, since its net assignments mirror the schematic's) if
   either turns out different.
2. Once you've bought the actual RJ11 jack, double-check its footprint
   against RJ14 (Connfly DS1133-S4) — if the pad spacing/count differs,
   swap it in `generate_pcb.py` and re-route just that connector's traces.
3. Add a ground pour on the analog section if you want extra noise
   margin (not done here — the board routes clean without one, but it's a
   cheap improvement for a load-cell signal).
4. Order 5 (one per keg).

## Case

`case.scad` is a parametric OpenSCAD design: an open-top base plus a
separate flat lid, screwed together at 4 corner posts (M3 self-tapping,
2.5mm pilot holes) — see `case_base_preview.png` / `case_base_preview_2.png`
/ `case_lid_preview.png` for renders.

- Sized around the board's actual footprint (155×90×1.6mm) with a 3mm gap
  to the inner walls and 2mm walls, so it should print fine on a standard
  FDM printer with no supports needed (lid is flat, base has no overhangs
  beyond straight vertical walls).
- The board sits on 4 short standoff posts (5mm, at the PCB's own mounting
  holes) held down by M3 screws from above; the lid attaches separately at
  the box's 4 corners, also M3.
- Component clearance above the board is a flat 15mm assumption (covers
  the tallest part here, the RJ14 jack, with margin) — I don't have exact
  height dimensions for any of these parts from datasheets, so treat this
  as a reasonable guess, not a verified fit. If a first print is too
  cramped, bump `component_clear` in `case.scad` and reprint just the base.
- **Front wall (y=0) has an open cutout** spanning the J1–J4 sensor
  terminal row, for the 4 sensor cables to exit (board-local y=0 is the
  board's own top edge, which sits against the case's front wall).
- **Back wall (y=outer_h) has a cutout matching J7's position** — moved
  here from a right-wall cutout when J7 moved from the board's right edge
  to its bottom edge (board-local y=90, which sits against the case's
  back wall — see Physical layout above). Earlier drafts had J7 positioned
  mid-board with a cutout nowhere near it — caught by directly computing
  J7's courtyard position against the case's wall coordinates rather than
  assuming the cutout was in the right place; fixed by moving J7 to the
  board edge (any case built around a mid-board position would need an
  internal tunnel to reach the connector, which isn't good practice
  regardless of the case).
- **Base is branded, engraved (not raised)**, both lines on the right
  wall (x=outer_w — the one wall without a connector cutout, now that
  J1-J4's cutout (front) and J7's (back) both claim one): "KegSensor"
  (bold, size 5) above "Sallaup Electronics" (italic, size 2.6, smaller as
  a subtitle). Recessed 0.6mm into the 2mm wall (1.4mm remains, plenty
  strong), centered horizontally and stacked vertically in the safe
  z-band shared with the connector cutouts. See
  `case_engrave_right_preview.png` — rendered as a true 2D orthographic
  projection from the wall's own outside-viewer perspective, not a 3D
  angle shot, because that's what actually caught a real bug the first
  time this branding was added (below). Text is generated with OpenSCAD's
  `text()` primitive directly from the strings in `case.scad`, not
  hand-drawn, so there's no typo risk — but getting an engraved letter
  *oriented* correctly on a vertical wall needs real verification, not
  assuming: the original front-wall attempt read upside-down at first; a
  fix reasoned from a 3D perspective render (a 180° rotation) corrected
  the vertical flip but introduced a horizontal mirror instead, only
  caught by switching to a true top-down 2D projection. `wall_text_right()`
  — a new module, following the same front/back pattern but re-derived
  from scratch for a wall on the other axis, not assumed by analogy —
  is what's in use now that branding moved to the right wall (freed up
  once J7's cutout claimed the back wall). Derived by tracking exactly
  what each OpenSCAD transform does to a known point rather than guessing,
  then verified the same way as before (a true 2D cross-section at the
  engrave depth, from the actual outside-viewer's perspective) — correct
  on the first attempt this time, though it was checked regardless rather
  than assumed correct from the derivation alone. `wall_text_front()` and
  `wall_text_back()` are both unused now but kept in case a wall needs
  text again later.

Regenerate with `./generate_case.sh` after editing `case.scad` (needs
OpenSCAD: `brew install --cask openscad`; this cask fails macOS Gatekeeper,
so also run `xattr -dr com.apple.quarantine "/Applications/OpenSCAD-2021.01.app"`
once after installing). Print at 0.2mm layers, 3+ perimeters, 20%+ infill;
PETG or ABS recommended over PLA since this lives inside a keezer at
fridge/freezer temperature and PLA gets brittle cold.

## Validation performed

- `kicad-cli sch erc` → 0 errors, 0 warnings
- `kicad-cli sch export netlist` → all 8 nets manually checked against the
  intended design (see table above)
- `kicad-cli sch export pdf` → visually reviewed, no overlapping labels or
  stray connections
- `kicad-cli pcb drc` on the fully routed board → 0 errors, 0 unconnected
  pads (only one pre-existing accepted warning remains: the
  local-footprint-override notice for J7's custom RJ14 footprint — see
  its own comment). Iterated repeatedly: the first full layout pass found
  17 real clearance/short issues from too-tight spacing; switching J7 from
  the RJ9 to the RJ14 footprint reset the J6↔J7 routing and took several
  more DRC-guided rounds to clear, since RJ14's pads are much more tightly
  packed. Moving J1-J4 to a horizontal row (see Physical layout) went
  through the same cycle: a straight diagonal tap point cut through an
  unrelated pad's copper twice before landing on the current routing, each
  time caught by DRC, not by eye. That pass also surfaced a separate
  latent bug: `generate_pcb.py`'s footprint copies kept the *library's*
  pad/graphic UUIDs verbatim, so multiple instances of the same footprint
  (J1/J3/J2/J4, all `TerminalBlock_bornier-3`) shared identical pad UUIDs
  - DRC started mislabeling which physical pad a violation was actually
  against once there were 4 copies on the board. Fixed by re-rolling every
  nested UUID per instance, not just the footprint's own top-level one.
- Un-rotating J1-J4 back to angle=0 and moving J7 to the bottom edge (a
  later request) meant redesigning essentially all of this board's
  routing again, and went through several more DRC-caught rounds: a
  diagonal from J1-J4's row to J5 cut through the SIG_POS lane;
  SIG_NEG's approach crossed straight through the J6↔J7 corridor's own
  drops; and J7's GND/SCK approaches (straight verticals into their own
  target x) each grazed the *other's* neighboring pad, since GND/SCK and
  VCC/DT sit only ~1mm apart in the tight RJ14 pad cluster. Each was a
  real `tracks_crossing`/`shorting_items`/`clearance` error, not a style
  preference — fixed with offset approach paths, layer hops, and
  depth-ordered lanes; see `generate_pcb.py`'s comments for the specifics.
- `kicad-cli pcb render` → top and bottom copper renders visually reviewed
  for sane, non-overlapping routing
- Case: OpenSCAD's CGAL export reports both `case_base.stl` and
  `case_lid.stl` as `Simple: yes` (valid, manifold, watertight solids —
  the check that predicts whether a slicer will handle a model cleanly).
  OpenSCAD's own GUI preview render didn't work headlessly in this
  environment (Gatekeeper/OpenGL context issue), so I rendered the actual
  exported STLs with a separate tool (matplotlib) from multiple angles
  and reviewed them for the checks that matter here: box walls intact
  where expected, both cutouts present at plausible positions, and the
  two post types (corner lid-posts vs. PCB standoffs) landing at distinct,
  non-colliding locations.
- J7-reachability fix: computed J7's courtyard bounding box in case-outer
  coordinates directly (not eyeballed) and checked it against the right
  wall cutout's coordinates before re-rendering, then re-rendered the
  updated STL and visually confirmed an actual opening lines up with the
  connector from two angles.
- Wall engraving: `case_base.stl` still reports `Simple: yes` after the
  text cutouts. Orientation specifically verified with true 2D orthographic
  projections of each wall (not 3D perspective renders, which is what
  produced a wrong first read) from that wall's actual outside-viewer
  angle — caught and fixed a vertical-flip bug and a horizontal-mirror
  bug this way before calling it done (see Case section above for the
  detail).

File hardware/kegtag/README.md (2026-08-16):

# KegTag — Sallaup Electronics (experimental)

Part of the **Sallaup KegSense** keg-monitoring system, made by
**Sallaup Electronics**.

**KegTag** is an experimental per-tap add-on: a wireless,
battery-powered e-ink tag showing that keg's brew name plus an
on-demand level snapshot. Sits alongside
[`../kegdisplay/`](../kegdisplay/)'s WS2812 bar, not a replacement for
it — the bar keeps the live, continuously-updating fill level (wired,
no battery budget to protect); KegTag only needs to refresh on
infrequent, hands-on events (keg swap, a manual level check).

**Experimental status**: not a committed part of the system. Depends on
an off-the-shelf ESL (electronic shelf label) tag actually meeting the
>1 year battery target in real-world testing — unverified so far, see
Still Open. May end up unbuilt if that doesn't pan out.

This is a planning doc — no hardware or software has been built yet.

## Decisions so far

- **Off-the-shelf ESL tag, not a custom board.** Wireless,
  battery-powered. **Target: >1 year battery life** — this is the
  actual requirement. An earlier idea (button-triggered wake, tag in
  deep sleep otherwise) was one way to hit that target by controlling
  the tag's own firmware, not a goal in itself — if a tag's stock
  firmware already keeps power draw low enough on its own, no custom
  firmware is needed.
- **Primary pick: Gicisky tags** — real direct BLE, talked to over a
  reverse-engineered open protocol
  ([`hass-gicisky`](https://github.com/eigger/hass-gicisky)), stock
  firmware (not reflashed). Bought new, direct
  ([GICIsky Official Store on AliExpress](https://www.aliexpress.com/item/1005002399342939.html),
  2.9" variant, ~162 kr at time of writing) — solves OpenEPaperLink's
  sourcing problem. Tradeoff: no control over the tag's own
  wake/refresh behavior since firmware isn't touched, so the >1 year
  battery claim (per AliExpress/reseller listings) is unverified
  marketing copy — needs real-world testing on one tag before
  committing (see Still Open).
- **Fallback: OpenEPaperLink**, if Gicisky's real battery life doesn't
  hold up. Reflashed tag firmware, full control over sleep/wake
  behavior (deep sleep, wake only on a button press or scheduled
  check-in) at the cost of a harder-to-source tag and more firmware
  work. Sourcing is currently rough: the one easy new-tag source found
  (Tindie seller "Electronics by Nic") has all listings retired, seller
  on a break until Dec 31 2027 — down to secondhand Solum/Hanshow tags
  (eBay, hit-or-miss on compatibility) or the OpenEPaperLink Discord's
  trading channel.
- **Wildcard, not decided: reverse-engineer a closed BT+app tag
  instead** — e.g. the TOP-TECH "2.1"/2.9" NFC+BT" AliExpress listing
  (glass front, IP65, proprietary Android app). One reviewer mentioned
  an unofficial "web app for chrome" alternative to the vendor app,
  suggesting someone's already partially reverse-engineered it, but
  that's unconfirmed — no linked project found. Doing this properly
  means capturing the vendor app's BLE traffic via Android's Bluetooth
  HCI snoop log + Wireshark while pushing an update, then decoding the
  GATT write format from a few varied captures. Real, buildable work
  (this is literally how `hass-gicisky` and most of the OpenEPaperLink
  reverse-engineering got done) but uncertain time investment, and only
  worth it over Gicisky if this tag's IP65/glass build or pricing ends
  up mattering — otherwise it's redoing work Gicisky's community
  already did.
- **Hub**: whichever tag path is chosen, a hub device sits on
  KegStation's network — for Gicisky, a lightweight ESP32 running a
  Home Assistant Bluetooth proxy; for OpenEPaperLink, a full AP (ESP32 +
  matching radio, e.g. ESP32-C6's onboard 802.15.4 or ESP32 + CC1101 for
  sub-GHz tags). Not part of KegDisplay's WS2812 chain either way.

## Still open

- **Gicisky real-world battery test — blocks choosing a path.** Order
  one tag (smallest/cheapest genuine e-paper variant — not the "TFT"
  color option, which is LCD, not e-ink), run it under normal update
  cadence (a few pushes/day), measure actual battery drain over 1-2
  weeks. Gicisky stays the pick if that holds up toward >1 year; falls
  back to OpenEPaperLink (or the reverse-engineering wildcard) if not.
- **ESL tag model/size** — not chosen. Gicisky sizes: 2.1", 2.9", 3.7",
  4.2", 7.5", 10.2" (per `hass-gicisky`). No published case dimensions
  in mm from any Gicisky reseller found so far — estimated ~75-85mm ×
  35-45mm × 8-12mm for the 2.9" variant based on standard 2.9" e-paper
  panel size, not confirmed. OpenEPaperLink's smallest well-documented
  option is the 1.3" Peghook (97.75mm × 28.6mm × 5.9mm, per SoluM's own
  datasheet) but it's a physical peg-hook clip, not a flat mountable
  tag — mismatched to a collar-mount use case without rework.
- **Tag mounting location** — likely needs its own mount point separate
  from KegDisplay's WS2812 bar enclosure (~50mm width budget), given
  ESL tags generally run wider than that. Not decided.
- **Hub hardware** — not built. For Gicisky: an ESP32 running a Home
  Assistant Bluetooth proxy. For OpenEPaperLink: DIY ESP32 + CC1101 vs.
  a bought ready-made AP (e.g. Mini-AP). Not decided.
- **KegStation's own side**: running the chosen hub and pushing
  brew-name/level data to it (see
  [`../kegstation/README.md`](../kegstation/README.md)) — not written.

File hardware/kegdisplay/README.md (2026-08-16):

# KegDisplay — Sallaup Electronics

Part of the **Sallaup KegSense** keg-monitoring system, made by
**Sallaup Electronics**.

**KegDisplay** is the per-keg status indicator: a vertical WS2812 LED
bar in its own enclosure, mounted on the collar's side at each tap,
showing that keg's remaining % as a fill-level bar (more LEDs lit from
the bottom = more left — same read as a fuel gauge). No per-tap MCU —
**KegStation** (the central Raspberry Pi — see
[`../kegstation/`](../kegstation/)) drives the whole chain directly.
An off-the-shelf WS2812 strip is glued or screwed to the front of a
small custom PCB inside the enclosure, which gives it a rigid mount and
carries both chain connectors (see the revision note below for how this
settled). Brew-name display is a separate, experimental add-on — see
[`../kegtag/`](../kegtag/).

This is a planning doc — no hardware or software has been built yet.
Captures decisions made so far so they aren't lost before implementation
starts (see [`../kegsensor/wiring.md`](../kegsensor/wiring.md) and
[`../keghub/README.md`](../keghub/README.md) for the equivalent docs
that preceded the KegSensor module).

**Revision note**: this design has gone through several full rewrites,
kept in git history rather than deleted outright:
1. Originally an Arduino Nano + MAX485 board per tap, daisy-chained over
   RS-485 with a custom chain-position auto-addressing scheme.
2. Then a bare OLED module per tap wired star-topology through a
   TCA9548A I2C multiplexer at KegStation, dropping the Nano entirely.
3. Then, realizing an OLED at every tap was itself more display than the
   job needed, the per-tap hardware shrank further to just a status LED
   + a pushbutton, with the actual detailed information (brew name,
   weight) moved to a screen at KegStation instead.
4. **This version**: brings the OLED back, but on a much smaller MCU
   with its own onboard I2C - each tap's OLED shows its own brew name +
   weight directly, all the time, no button/KegStation-touchscreen
   detail view needed. The Nano-sized objection that killed revision 1
   doesn't apply this time; the shared-I2C-address conflict that killed
   the mux approach in revision 2 doesn't apply either (each tap's OLED
   is on its *own* MCU's I2C bus, not a bus shared across taps). The MCU
   choice within this revision itself went through several rounds:
   Adafruit Trinket M0 (real hardware I2C, easy USB/Arduino flashing,
   but ~$5-6/unit) -> Seeeduino XIAO SAMD21 (same capability, smaller
   board, similar cost) -> ATtiny10 (tiny and ~$0.30, but no hardware
   I2C/UART and needs a TPI programmer) -> CH32V003 (cheapest of all,
   ~$0.10-0.15, real hardware I2C, but RISC-V + WCH-LinkE is a bigger
   toolchain departure than anything else in this project) ->
   **ATtiny1614 in SOIC-14**, the settled choice: real hardware I2C,
   16KB flash/2KB RAM (enough for real OLED text, unlike ATtiny10's
   1KB), ~$0.60-1.20/unit (far cheaper than Trinket M0/XIAO, only a
   modest premium over CH32V003), programmed over UPDI (simpler than
   ATtiny10's TPI - a USB-serial adapter + one resistor is enough), and
   SOIC-14 is still hand-solderable (unlike QFN packages, which need
   reflow/hot air).
5. **This version**: dropped the OLED+MCU entirely. The real physical
   constraints at the mounting location (~100mm between taps, ~30mm max
   height) kept defeating every attempt to fit the ATtiny1614+OLED+
   connector assembly — landscape reorientation, connector swaps
   (KK-254 vs RJ14 vs audio jack), aggressive layout compaction all hit
   walls, most fundamentally that any locking/panel-mount connector's
   physical plug needs ~12-20mm of depth, which doesn't fit in the
   ~12mm gap left between taps once a board of any reasonable size is
   in place. Back to a WS2812 LED chain (first explored in revision 3),
   but as a 10-LED bar graph per tap instead of a single status LED,
   and with KegStation driving the chain directly — no per-tap
   MCU/logic at all, sidestepping the space problem instead of
   continuing to fight it.
6. **This version**: switched from a horizontal custom-PCB LED bar to a
   **vertical off-the-shelf WS2812B LED strip** mounted on the collar's
   side (~50mm width x ~130mm height available there - a much bigger
   budget than the ~100x30mm the horizontal layout was fighting for).
   Two wins at once: (1) a commercial strip at 140-200 LEDs/m gives
   18-26 LEDs over that length, cut to whatever length is wanted, so
   there's no custom PCB to design/fab at all - just a cut strip with a
   few wires soldered on at each end; (2) a vertical fill-level bar
   reads more intuitively than a horizontal one (same mental model as a
   fuel gauge or thermometer).
7. **This version**: brought a custom PCB back after all — not because
   the vertical layout was wrong, but to solve two things a bare
   commercial strip couldn't: a rigid mounting surface inside the box,
   and a way to get *both* chain connectors onto the box's bottom edge
   (see "connectors on left/right" below — both need to end up at the
   bottom, and a floppy 3-wire strip has no natural way to route a
   return path back down). Individual WS2812B LEDs are placed directly
   on a 2-layer PCB instead: front layer carries the LED chain bottom to
   top; after the top LED, a via drops the single DATA_OUT signal to the
   back layer, which routes it back down to the bottom-right connector.
   VCC/GND don't need this detour — they're shared rails running the
   full board height on the front layer, tapped directly by both
   connectors.
8. **This version**: swapped the 23 individually-placed LED footprints
   for an off-the-shelf WS2812 strip, glued or screwed to the front of
   the custom PCB. The PCB still solves the same two problems revision 7
   introduced it for (rigid mounting surface, both connectors on the
   bottom edge) — that didn't change. What changed: hand-laying out 23
   LED footprints/nets was more work than buying an assembled strip and
   mounting it. The PCB's job shrinks to rigid backer + both connectors
   + a soldered-wire path (the strip's own DIN/DOUT leads soldered to
   pads) instead of continuous copper running through 23 LED footprints.
   Nothing below reflects revision 7's individual-LED approach.

## Decisions so far

- **Per tap: an off-the-shelf WS2812 LED strip, glued or screwed to the
  front of a custom 2-layer PCB**, mounted vertically inside an
  enclosure on the collar's side. No per-tap MCU — KegStation lights
  however many LEDs correspond to the keg's remaining % as a bottom-up
  fill bar. Same chain-position addressing as every earlier revision —
  purely protocol-level, no firmware/logic at the tap.
- **Topology: daisy chain, 3 conductors (+5V, GND, WS2812 data)**,
  same as every earlier revision.
- **Power: 5V**, matching the Pi's logic level, same as every earlier
  revision — but sourced from its own dedicated supply injected into
  the chain, not drawn through the Pi itself (see
  [`../kegstation/README.md`](../kegstation/README.md) for why: LED
  current draw exceeds what the Pi's own PSU/GPIO can safely provide).
- **Mounting location: collar's right side, vertical**, not the tap
  face — ~50mm width x ~130mm height available there. Confirmed against
  the real keezer, not guessed: tap spacing ~10cm apart horizontally
  (real photo, 5 taps through a single wood plank, plus a direct
  measurement), collar board height 13cm (matches the ~130mm figure
  almost exactly), and the board is confirmed finished wood (despite
  looking unfinished in the photo) — the earlier reasoning against
  drilling a blind bore for cable routing (a visible mistake in
  installed, finished wood, with no way to redo it) holds as originally
  reasoned. Board thickness is the only dimension still unmeasured (see
  Still Open).
- **Housed in a rectangular enclosure** — protects the PCB and gives the
  LEDs a diffuser window instead of exposed dots. Box footprint sized to
  the ~50x130mm mounting budget above.
- **Both connectors live on the box's bottom edge, one on the left, one
  on the right, each with a short wire pigtail to the next tap's box** —
  not top/bottom of the box, even though the PCB inside runs vertically.
  Taps sit ~10cm apart *horizontally* along the collar, so the
  daisy-chain cable between one tap's box and the next needs to run
  sideways; bottom-left/bottom-right connector placement matches that
  real cable path instead of forcing an awkward top-to-bottom-then-across
  route.
- **PCB signal routing**: left connector (chain in) feeds pads at the
  strip's bottom (DIN) end via soldered wire leads. The strip itself
  carries data up its own length front-side; its DOUT lead at the top
  end solders to a pad, where a via drops DATA_OUT to the back layer,
  routing it straight back down to the right connector (chain out) —
  same detour concept as revision 7, now via a soldered wire+pad instead
  of continuous LED-to-LED copper. VCC/GND: the strip's own power leads
  solder to pads tied to shared rails on the front layer spanning the
  full board height, tapped directly by both connectors.
- **Mounting method (glue vs. screw) depends on which strip is
  sourced** — a flexible, adhesive-backed strip (the common type) only
  supports gluing; a rigid-PCB or aluminum-channel strip variant would
  support screws if one is sourced instead. Not decided (see Still
  Open).
- **PCB laid out and DRC-clean, board size settled: 34x132mm**, offset
  from the origin (x: 9.5-43.5mm, y: -2-130mm) — resized/shifted in the
  KiCad GUI from the original 50x130mm placeholder and confirmed as the
  right size. `generate_bar_schematic.py` / `generate_bar_pcb.py` in
  this directory build this board, kept in sync with that GUI edit.
  Which specific off-the-shelf strip to buy is still open (see Still
  Open) but must now fit this board size, not the other way around.
  J1/J2 still near the bottom, outward-
  facing (cable exits sideways), nudged off strict edge-flush/shared-Y
  placement in the GUI to clear each other's and MH2's courtyards after
  the resize. R1/C1 between them (unchanged). TP1-3 (strip's bottom
  GND/VCC/DIN leads) and TP4-6 (strip's top GND/VCC/DOUT leads) remain a
  tight 4mm-pitch cluster of hand-solder test points, replacing the 23
  LED footprints. Mounting holes MH1/MH2 both moved to the board's
  horizontal center in the GUI. ERC/DRC clean aside from known-benign
  warnings (`lib_footprint_mismatch` from UUID regeneration;
  `silk_over_copper` from the connectors' own default pin-1 silkscreen;
  `unconnected_items` since, like every earlier revision's generator
  script, this places components and assigns nets but does **not** emit
  copper traces/vias — it validates physical fit and clearance, not
  routing completeness; the DATA_OUT via + back-layer return trace is a
  routing detail for real layout, not modeled here).

## Superseded (revision 7, individual LEDs on PCB) — kept for reference

- **Per tap: 23x WS2812B-2020 (2.0x2.0mm) LEDs at 5mm pitch (200 LEDs/m)
  soldered directly onto the custom 2-layer PCB** — the smaller 2020
  package (vs. revision 5's 3.5x3.5mm Mini) gave comfortable clearance
  at this tight pitch. Superseded by revision 8's off-the-shelf strip
  glued/screwed to the same PCB — hand-laying out 23 individual LED
  footprints/nets was more generator-script work than buying an
  assembled strip; the PCB's role (rigid mount, both connectors on the
  bottom edge) carries forward unchanged.
- **PCB signal routing (individual-LED version)**: left connector fed
  the bottom LED's DIN directly; data climbed LED to LED on the front
  layer to the top LED's DOUT, where a via dropped DATA_OUT to the back
  layer, routed back down to the right connector. Same detour concept
  revision 8 keeps, just via continuous LED-to-LED copper instead of a
  strip's own leads soldered to pads.
- **PCB laid out and DRC-clean for this construction**:
  `generate_bar_schematic.py` / `generate_bar_pcb.py` in this directory
  build *this* (now superseded) board — 23 LEDs at 5mm pitch, board
  50x130mm, J1 bottom-left / J2 bottom-right both facing outward
  (JST-PH 3-pin horizontal, same footprint/angles as revision 5), R1/C1
  between them. ERC/DRC clean aside from known-benign warnings
  (`power_pin_not_driven` on VCC/GND — same accepted quirk as every
  earlier revision's schematic; `lib_footprint_mismatch` from UUID
  regeneration; `silk_over_copper` from the connectors' own default
  pin-1 silkscreen crossing their own pads). **Not yet regenerated for
  revision 8** — these scripts still model the individual-LED
  construction, not the strip-on-backer-PCB one (see Still Open).

## Superseded (revision 6, off-the-shelf strip) — kept for reference

- **Per tap: a commercial WS2812B LED strip (140-200 LEDs/m), cut to
  length.** No custom PCB. Superseded by revision 7's custom PCB, needed
  to give the strip a rigid mounting surface and to route a return path
  to both bottom connectors (see revision note above) — otherwise the
  core idea (vertical fill bar, ~50x130mm collar-side mounting, no
  per-tap MCU) carries forward unchanged.
- **Topology detail specific to a cut strip**: 3 pads at each end, a
  short pigtail soldered on at each end carrying them to a chain
  connector. Moot once LEDs are placed directly on a PCB instead.

## Superseded (revision 5, custom PCB LED bar) — kept for reference

The horizontal custom-PCB version (generate_schematic.py/generate_pcb.py
in this directory) went through extensive layout work — 10 LEDs down to
5, connector swaps, edge-flush J1/J2 for case-wall cutout access — all
now moot since revision 6 uses a cut length of commercial strip instead
of a custom board. Kept as-is in this directory rather than deleted;
treat as historical, not a current target to keep building against.

## Superseded (revision 4, ATtiny1614+OLED) — kept for reference

- **Per tap: one ATtiny1614 (SOIC-14) + one 0.91" SSD1306 I2C OLED.** The
  ATtiny1614 is its own I2C master for its own OLED — no shared bus, no
  address conflict, no mux (that was revision 2's problem, and it simply
  doesn't arise here since each tap's I2C bus is private to that tap).
  No button, no resistor ladder, no KegStation-side ADC — the OLED just
  always shows its own keg's brew name + weight. See the revision note
  above for the full MCU comparison (Trinket M0/XIAO/ATtiny10/CH32V003)
  that led here.
- **Development workflow: Arduino IDE + megaTinyCore, prototype on a
  SOIC-to-DIP adapter, flash over UPDI, keep a UPDI header on the final
  board.** Concretely:
  1. Write firmware as a normal Arduino sketch (megaTinyCore adds
     ATtiny1614 as a board option, `Wire.h` works for I2C).
  2. Prototype on a breadboard by soldering the chip onto a cheap
     SOIC-14-to-DIP adapter board first, rather than committing straight
     to a custom PCB.
  3. Flash via **SerialUPDI** — a plain USB-to-serial adapter plus one
     resistor between its TX/RX lines, wired to the chip's UPDI pin.
     megaTinyCore supports this directly as an Arduino IDE upload
     method, so it's still just "hit Upload."
  4. Once firmware is solid, solder a chip onto the real per-tap PCB,
     which includes its own **3-pin UPDI header (UPDI/VCC/GND)** so it
     can be reflashed in place later (fixing a bug or tweaking the OLED
     layout after it's already mounted at the tap) without desoldering.
  5. **Field reflashing: temporary cable from KegStation's own UART pins
     to J4, one tap at a time** — a Pi's UART (TX/RX) can run SerialUPDI
     directly, so KegStation itself is the programmer, no separate
     laptop/USB adapter needed. Not a permanent connection (UPDI is
     point-to-point; it can't ride the shared chain bus without hitting
     every tap's chip at once) — walk up to the tap, plug in, flash,
     unplug. J4 stays inside the case (no dedicated access port needed
     in the lid/body — see Still Open) since this is infrequent enough
     that opening the case is an acceptable cost.
  6. **Possible future upgrade, not implemented now**: a bootloader that
     receives firmware over the chain itself (via J1, reusing the same
     "consume my chunk, relay the rest" addressing idea as the brew-data
     relay), removing the need to physically visit a tap at all for
     routine updates. J4/UPDI would still be needed for a blank chip's
     very first flash either way. Deliberately deferred — not worth the
     bootloader complexity until the rest of the system is proven out.
- **Chain addressing: still positional, like the WS2812 version, but now
  relayed by firmware instead of being protocol-free.** KegStation
  streams all 5 kegs' data down the chain in tap order; each ATtiny1614
  reads its own chunk off its "chain in" pin (a bit-banged serial RX),
  keeps that chunk for its own OLED, and relays everything after it out
  its "chain out" pin (bit-banged serial TX) to the next tap. No
  per-tap address to configure, same principle as the LED chain, just
  carrying real data (text) instead of raw color bits.
  - **Pin budget**: ATtiny1614 (SOIC-14) has 14 pins total: VDD, GND,
    UPDI (shared with reset, freed up by the UPDI header above), and 11
    GPIO. 2 go to hardware I2C (SDA/SCL, to the OLED), 2 to chain
    in/chain out, leaving several spare — a much more comfortable
    budget than Trinket M0's 5 broken-out GPIO.
- **Topology: daisy chain**, one cable hopping tap to tap, same as the
  WS2812 version and for the same reason — the chain-position addressing
  scheme requires it.
  - **3 conductors used: +5V, GND, chain data** (one direction only —
    KegStation "down" through the chain; no need for a return path,
    since each tap only needs to receive, not report back). 2 jacks per
    tap (IN from upstream, OUT to downstream), **Molex KK-254 (4-pin,
    2.54mm pitch)** — not RJ14 like KegSensor's jack, switched for board
    size (KK-254's courtyard is ~1/3 RJ14's) while keeping a real
    locking latch, unlike JST-PH (used only for the short internal OLED
    cable, where no latch is needed). 4th contact left unused/spare.
  - **Same known IN/OUT-swap fragility as the WS2812 version, re-accepted
    for the same reason**: chain-in and chain-out are different pins on
    the Trinket, not symmetric, so a swapped cable breaks that tap and
    everything downstream of it. Worth keying/labeling the jacks clearly
    at install time.
  - **Chain fragility**: a disconnected or dead tap breaks every tap
    downstream of it, same as any physical daisy chain — already
    discussed and accepted in the WS2812 revision, still true here.
- **Power: 5V** on the shared rail, matching the Pi's own 5V — the OLED
  module runs fine off 5V directly (most SSD1306 breakouts have their
  own onboard 3.3V regulator). ATtiny1614's own VDD range/regulation
  need still needs confirming (see Still Open) - it may need a small
  local 3.3V regulator on the per-tap board, unlike Trinket M0 which
  handled that internally.
- **OLED-to-board cable: 4-pin JST-PH (2mm pitch).** The lid-to-body run
  is under 2cm, short enough that a compact connector fits better than
  a pin header — hand-solderable, unlike the finer 1mm-pitch JST-SH
  alternative.
- **Mounting location: outside the keezer** — the OLED/ATtiny1614
  assembly sits on the tap's own exterior face, same reasoning as every
  earlier revision: no part of the wiring needs to enter the cold zone.
- **Mechanical split: main board inside the case body, OLED mounted on
  the case lid, connected between them by a short wire harness** (not a
  single rigid board carrying both) - decided when starting the case/lid
  design, still in progress (see Still Open). The OLED's 4-pin header
  (VCC/GND/SCL/SDA) on the main board is exactly this cable's connection
  point, not a directly-soldered display.
- **Physical cable routing: hidden along the collar's exterior, under a
  paintable plastic cord cover** — not routed through the collar's
  interior cavity (both ends are already outside, so dipping into the
  cold zone would be pure downside), and not bored through the solid
  wood either (the collar here is already built and finished — a long
  blind bore through installed wood risks a visible drilling mistake
  with no way to redo it, unlike drilling before assembly). Cable runs
  along an inconspicuous exterior seam (e.g. where the collar meets the
  freezer body) and is covered by an off-the-shelf paintable plastic
  cord cover, painted to match — reads as a deliberate trim detail
  instead of an exposed wire.
- **Not yet built or prototyped** — this whole design came out of
  conversation, not a physical test yet. Same "verify against real
  hardware before calling it done" standard as everything else in this
  project.

## Still open

- **Which off-the-shelf strip to source** — not chosen. Board size
  (34x132mm) is now settled, so this is a fit-to-board search, not an
  open-ended one: needs a strip whose usable length fits the ~132mm
  board height, with end-lead spacing compatible with the TP1-3/TP4-6
  hand-solder clusters (revisit their exact positions in
  `generate_bar_pcb.py` once a strip is picked, if its real lead spacing
  differs from the current placeholder). Also determines whether glue or
  screws are possible (see "Mounting method" above — needs a rigid-PCB
  or aluminum-channel strip for screw-mounting; a standard flexible
  adhesive-backed strip only glues).
- **Enclosure: first-draft 3D-printable case modeled, NOT verified
  against real hardware yet.** `case_bar.scad` /
  `generate_case_bar.sh` (this directory) build two parts: `base`
  (solid wall — no window, side walls with left/right cutouts for
  J1/J2's cable exit, two PCB standoff posts at MH1/MH2, four corner
  posts for the lid, two mounting flanges on its top/bottom edges with
  wood-screw clearance holes) and `lid` (a frame with the diffuser
  window cut through it over the strip's span, four screw holes to
  close onto the base's corner posts). **The base, not the lid, is the
  face that mounts to the collar** — the lid carries the window and
  must face outward into the room for the LEDs to actually be visible;
  mounting the lid flush against the collar would hide them against the
  wood. Outer footprint ~43x141mm
  (board 34x132mm + margin + wall), depth ~15mm (component/strip
  clearance + board + standoff). Renders cleanly (`openscad`, both
  parts report `Simple: yes`) — see `case_bar_base_preview.png` /
  `case_bar_lid_preview.png`. Component clearance depths (JST-PH body
  height, strip thickness) are typical values, not measured off real
  parts — same "verify before calling it done" standard as the rest of
  this project; don't print for real without checking against actual
  hardware first. Diffuser window material/fit itself is still
  unaddressed (just an open cutout right now, no diffuser panel
  modeled). Two-point standoff mounting (not four-corner) may need a
  card-edge rail added later if the board flexes over its 132mm length
  in practice.
- **Collar board's thickness** — not measured (height 13cm and finished
  status are now confirmed, see above).
- **Wire gauge for the pigtails** at J1/J2 — not decided.
- **Reverse-polarity protection** — not reconsidered for this revision.
- **KegStation's own side**: the code that computes each keg's % and
  drives the WS2812 chain — not written yet. Brew-name/level display
  (ESL hub, tag protocol) is tracked separately, see
  [`../kegtag/`](../kegtag/).
- `case.scad`, the lid board (`keg_display_lid_module`), the ATtiny1614
  main board's KiCad files, and the revision-5 LED-bar KiCad files
  (`generate_schematic.py`/`generate_pcb.py` in this directory) are all
  obsolete — kept in git history, not deleted.

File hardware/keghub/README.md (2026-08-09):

# KegHub

**Sallaup Electronics** — part of the **Sallaup KegSense** keg-monitoring
system.

**KegHub** is the passive in-keezer wiring panel: it collects the RJ11
runs from each keg's **KegSensor** module (see
[`../kegsensor/wiring.md`](../kegsensor/wiring.md)) and buses them onto a
single RJ45 run out to **KegStation** (the external Raspberry Pi central
unit — see [`../kegstation/`](../kegstation/)). KegStation's own
hardware/software is a separate, later phase.

## System overview

```
 Keg 1  --RJ11-->  |               |
 Keg 2  --RJ11-->  |    KegHub     |
 Keg 3  --RJ11-->  |   (passive    |  --RJ45-->  KegStation
 Keg 4  --RJ11-->  |    panel)     |             (Raspberry Pi)
 Keg 5  --RJ11-->  |               |
```

- No WiFi/radio inside or on the keezer.
- KegHub is fully passive: no MCU, just bussed wiring.
- 3.3V logic system-wide (Raspberry Pi GPIO is not 5V-tolerant).
- RJ45's 8 wires = VCC + GND + SCK(shared) + 5×DT → hard cap of 5 kegs per KegHub/cable.

## Panel

Perfboard/protoboard in a small project box, cold-rated (silicone-insulated)
hookup wire throughout since it lives inside the keezer:

- 5× RJ11 female jacks, labeled KEG1–KEG5
- 1× RJ45 female jack, facing out to KegStation

Internal bussing:

- All 5 jacks' **Green (SCK)** pins tied together → RJ45 pin 1
- All 5 jacks' **Red (VCC)** pins tied together → fed from RJ45 pin 4
- All 5 jacks' **Black (GND)** pins tied together → fed from RJ45 pin 5
- Each jack's **Yellow (DT)** stays independent → its own RJ45 pin

### RJ45 pin mapping (T568B colors shown for reference when terminating)

| RJ45 pin | T568B color | Signal |
|---|---|---|
| 1 | Orange/White  | SCK (shared) |
| 2 | Orange | DT — Keg 1 |
| 3 | Green/White | DT — Keg 2 |
| 4 | Blue | VCC (3.3V) |
| 5 | Blue/White | GND |
| 6 | Green | DT — Keg 3 |
| 7 | Brown/White | DT — Keg 4 |
| 8 | Brown | DT — Keg 5 |

VCC/GND share the Blue twisted pair (keeps power together, reduces noise
coupling into data lines). SCK is paired with DT‑Keg1 on the Orange pair.

Fine for short indoor runs without shielding. If the KegHub-to-KegStation
run ends up long, switch to shielded Cat5e/6 (STP) and/or slow the SCK
bit-bang rate in the eventual KegStation firmware.

## Parts list (KegHub side)

- 5× RJ11 female panel-mount jacks
- 1× RJ45 female panel-mount jack
- 1× Cat5e/6 patch cable, KegHub to KegStation
- Perfboard/protoboard + small project box
- Silicone-insulated (cold-rated) hookup wire

See [`../kegsensor/wiring.md`](../kegsensor/wiring.md) for the per-keg
(KegSensor-side) parts list.

## Bench-test checklist (before final assembly)

Do this before KegHub is sealed into its enclosure or the load cells are
mounted under kegs — much easier to fix a miswired jack now.

1. With KegHub fully wired but nothing plugged into the RJ11 jacks yet,
   multimeter-check RJ45 pin 1 (SCK) for continuity to **all 5** jacks'
   Green pin. All 5 must read continuous; if one doesn't, that jack's SCK
   bus connection is broken.
2. Repeat for VCC: RJ45 pin 4 → all 5 jacks' Red pin.
3. Repeat for GND: RJ45 pin 5 → all 5 jacks' Black pin.
4. For each jack N (1–5), check its Yellow (DT) pin is continuous to *only*
   its assigned RJ45 pin (2/3/6/7/8 per the table above) and to no other
   RJ45 pin, and not to any other jack's Yellow pin. This catches a DT line
   accidentally bussed instead of kept independent.
5. Check for unwanted shorts: no continuity between SCK, VCC, GND, or any
   DT pin pairs other than the intended bus connections above.
6. Plug in one keg module (load cell + HX711 + RJ11 cable) at a time and
   confirm VCC/GND/SCK reach the HX711 and its DT reaches the correct RJ45
   pin, before wiring the rest.

Full end-to-end electrical verification (reading actual weight values)
happens once KegStation (the Raspberry Pi central unit) is built — that's
the next phase.

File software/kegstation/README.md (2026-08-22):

# KegStation software — UI simulator skeleton

Part of **Sallaup KegSense**. This is a PC-simulator build of KegStation's
on-unit UI — the same [LVGL](https://lvgl.io) application code that will
eventually run on the real Raspberry Pi Zero 2 W + 4.0" ILI9488 TFT (see
[`../../hardware/kegstation/README.md`](../../hardware/kegstation/README.md))
runs here in an SDL2 desktop window instead, so the UI can be built and
demoed well before the real hardware arrives. Only the display/input
*driver* differs between simulator and hardware — `src/ui.c` is the actual
production UI code, identical either way.

**Status**: navigation skeleton only. Opens a keg-select screen — a
background photo of the actual Sallaup rig (`assets/sallauprampen.jpg`,
pre-cropped to 480×320 with Python/Pillow so the "Sallaup" sign on the
shed lands near the top rather than getting cut off by LVGL's own
auto-crop, which didn't handle a portrait source well) under a dark
scrim for legibility — that sign **is** the branding now, no separate
text wordmark. Below it, 5 keg icons in a row — each the actual product
photo of a Cornelius keg (`assets/keg_photo.jpg`, cropped from a stock
photo with its white studio background flood-filled to the app's dark
theme color, then pre-resized to its exact on-screen icon size — all
with Python/Pillow, same reasoning as the background photo, since
LVGL's `LV_IMAGE_ALIGN_STRETCH` silently truncated the tall source
instead of scaling the whole thing down) with a translucent vertical `lv_bar`
overlaid directly on the metallic body for fill level (measured off the
photo so it lands on the steel, not the black cap/base — see
`BODY_TOP`/`BODY_BOTTOM` in `ui.c`), plus the settled red/green
sensor-connection dot — that drill into a
per-keg "Tare / Set Full / Back" screen (same background). The fill bar
is colored by
level — green ≥50%, yellow ≥20%, red ≥5%, and **blinking red** below
5% (an infinite-repeat opacity animation on the bar's indicator part).
Fill levels and sensor status are both faked (`keg_fill_level()` /
`keg_sensor_connected()` in `ui.c`, deliberately varied to demo all four
color states at once) — real data comes from the C daemon's readings
file once that exists. In the simulator, levels also drift randomly
every second (`level_update_timer_cb`, simulator-only — real hardware
has no equivalent, levels there only change because someone's actually
pouring beer) so the row visibly updates instead of sitting static;
colors and the critical blink animation start/stop correctly as each
keg's level crosses a threshold. The Tare/Set Full buttons just update a status
label for now — the real guided calibration wizard (place empty keg →
confirm → select preset weight → confirm, see the hardware README's
"On-unit calibration wizard") isn't wired up yet, this only demonstrates
the screen-navigation structure it will sit on top of.

## Build (macOS)

```sh
brew install cmake sdl2 pkg-config
cmake -S . -B build
cmake --build build --target kegstation_sim -j4
```

## Run

```sh
./build/kegstation_sim
```

Opens a 480×320 window (matching the real panel's resolution). Controls:

- **Arrow keys**: move focus between menu items (same up/down/left/right
  scheme the real 5 discrete GPIO buttons will drive — see the hardware
  README's "Display + input" note on why buttons were picked over a
  rotary encoder)
- **Enter**: select the focused item
- **Mouse**: also works (click directly), since the SDL mouse indev is
  registered alongside the keyboard one — convenient for testing but not
  representative of the real hardware's input

## Layout

- `lv_conf.h` — LVGL config, copied from `extern/lvgl/lv_conf_template.h`
  with targeted changes: top `#if 0` flipped to `#if 1` to enable the
  file; `LV_USE_SDL` on for the simulator; `LV_FONT_MONTSERRAT_24` on
  for the per-keg detail screen's "Keg N" title (only size 14 was on by
  default); `LV_USE_TJPGD` on (LVGL's own built-in JPEG decoder, no external
  library needed — matters for the real Zero 2 W target) and
  `LV_USE_FS_STDIO` on (drive letter `A:`) so the background photo can
  be loaded from a file. Left everything else at LVGL's own defaults
  (`LV_COLOR_DEPTH 16` matches the RGB565 pixel format already planned
  for the real SPI driver).
- `assets/sallauprampen.jpg` — the background photo (the actual Sallaup
  rig). Loaded via `LV_USE_FS_STDIO`, path relative to wherever
  `kegstation_sim` is run from (see "Run" above — from
  `software/kegstation/`).
- `extern/lvgl/` — LVGL itself, as a git submodule (run
  `git submodule update --init` if it's empty after cloning this repo).
  Currently pinned to a `master` snapshot (v9.6.0-dev), not a tagged
  release — worth moving to a stable tag later if this grows past a
  skeleton.
- `src/main.c` — the only genuinely simulator-specific file: opens the
  SDL2 window/input devices and hands off to `ui.c`. The real-hardware
  build will have its own `main.c` that sets up the actual SPI/GPIO
  driver instead, calling the same `kegstation_ui_build()`.
- `src/ui.c` / `src/ui.h` — the actual UI: keg-select screen, per-keg
  detail screen, navigation group. This is the file that matters — it's
  meant to run unmodified on real hardware.
- `src/main_hw.c` — the real-hardware counterpart to `main.c`: drives an
  ILI9488 SPI TFT + 5 GPIO buttons via `pigpio` instead of SDL2, calling
  the same `kegstation_ui_build()`. **Not built or tested** — no CMake
  target links it, and it can't be verified until real hardware exists
  (same standard as the rest of this project). Every LVGL call in it was
  checked against the real v9.6 headers here, but the GPIO pin numbers
  and ILI9488 init register values are still placeholders.

## Known rough edges

- Uses `lv_list_*` widgets (detail screen only) and `lv_obj_add_flag`,
  both of which this LVGL snapshot marks deprecated (`lv_list` in favor
  of building lists from flex columns; `lv_obj_add_flag` in favor of
  per-flag setters like `lv_obj_set_clickable`) — still compiles and
  works, just noisy `-Wdeprecated-declarations` warnings. Worth migrating
  if this grows into the real implementation.
- LVGL is pinned to whatever `master` commit was current when the
  submodule was added, not a tagged release.
- The background image path (`A:assets/sallauprampen.jpg`) is relative
  to the process's working directory, not the binary's location — run
  `kegstation_sim` from `software/kegstation/` (as documented above) or
  the image silently fails to load and just the flat dark fallback
  color shows. The real-hardware build (`main_hw.c`) doesn't use this
  at all yet — no equivalent background-image code there.

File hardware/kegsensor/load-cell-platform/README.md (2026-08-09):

# Load cell holder — derived design

`load_cell_holder.scad` is a same-dimension recreation of a third-party
snap-fit load cell holder from Printables:
https://www.printables.com/model/157473-load-cell-holder

It holds one of the KegSensor half-bridge load cells at one end (snap-fit
into the central pocket) while the other two holes bolt the holder down
to a base plate. Four of these, one per corner, is the mounting scheme
for a keg platform — see `../wiring.md` for the sensor wiring side of
that (not built yet; this holder is the first piece of the mechanical
platform, done in isolation per current scope).

## Why OpenSCAD instead of just using the original STL

Consistent with how the rest of this project's parts are built
(`case.scad`, `generate_pcb.py`) — editable source, not an opaque
downloaded file, so dimensions can be adjusted later (e.g. once the
actual platform plates get designed and need to match up with these
holders) without needing to reverse-engineer it again.

## How it was derived

The original's dimensions were **measured directly from the downloaded
STL**, not eyeballed or guessed:
- 2D cross-section slices through the mesh at specific heights (exact
  polygon boundaries, not approximated from a rendered image)
- Point-cloud analysis for hole positions/diameters and material
  thickness at various heights

Key measured values (see comments in `load_cell_holder.scad` for the
full set): overall envelope 76.08 × 46.05 × 8.01mm, two M4-clearance
bolt holes (r=2.05mm) 59.05mm apart, a 26.03×26.03mm central pocket
opening, ~6mm base thickness with a ~2mm raised lip around the pocket,
and a ~5.8mm-wide split-seam slit at the pocket's top edge (the flex
feature that lets the load cell snap in).

This is a **faithful functional recreation** (same envelope, hole
positions/sizes, pocket opening, general thickness) — not a
byte-identical mesh clone. Fine fillet/rounding details are approximated
with simpler geometry.

### Added: cable exit notch (not in the original)

Checked directly, not assumed: the original design has **no cable exit**
— the pocket is fully enclosed on all 4 sides, and the flex-seam slit
does not reach the pocket opening (confirmed via the same 2D
cross-section / top-down projection methods, at multiple heights).
Without it, a cable coming off the load cell would have to share the
same ~26×26mm pocket opening as the load cell body itself.

Added a 6mm-wide notch through the pocket wall on the **-Y side**
(opposite the seam slit, so the two features stay separated). Originally
full part height, then changed to **half height, at the bottom**
(z=0-4mm of the 8mm total) so solid material remains as a roof over the
cable rather than opening the whole side. Controlled by
`cable_notch_half_w` / `cable_notch_y0` / `cable_notch_y1` /
`cable_notch_height` in `load_cell_holder.scad`. See
`load_cell_holder_cable_notch.png` for the top-down verification render
and `load_cell_holder_notch_sideview.png` for a Y-Z cross-section
directly confirming the notch spans z=0-4mm on the -Y side while the
+Y (seam) side stays full height (still `Simple: yes` after each
change).

## Validation performed

- `openscad` reports the generated STL as `Simple: yes` (valid, manifold,
  watertight — same check used throughout this project).
- Bounding box compared directly against the original: 76.08×46.04×8.00mm
  derived vs. 76.076×46.046×8.008mm original — matches to within
  measurement/rounding error.
- Volume compared: 12646mm³ derived vs. 12974mm³ original (~2.5% smaller,
  expected from the approximated fillets, not a structural difference).
- **A first attempt had a real bug**: the ear tabs appeared visually
  disconnected from the central collar in a 3D perspective render. Rather
  than trusting that render, it was checked against the actual 2D
  polygon outline (`openscad ... -o outline.svg`, confirmed a single
  closed contour — i.e. actually one connected shape) and a true
  top-down orthographic projection colored by height (see
  `load_cell_holder_validation.png`) — both confirmed the geometry was
  fine and the "gap" was a rendering artifact in the perspective-view
  script (matplotlib doesn't depth-sort concave 3D shapes well), not a
  real defect. The ear/collar overlap was still widened afterward as a
  robustness margin regardless. `load_cell_holder_validation.png` is the
  final side-by-side (original vs. derived) top-down comparison used to
  confirm the match — same figure, both parts now line up on bolt hole
  positions, pocket opening, raised lip, and seam slit.

## Known limitation

The original file (`load_cell_holder_reference.stl`, used locally for
comparison during derivation) is **not included in this repo** — it's a
third-party download with unspecified license terms, not ours to
redistribute. Get it from the Printables link above if you want to
re-run the comparison yourself; `.gitignore` excludes it by that
filename.

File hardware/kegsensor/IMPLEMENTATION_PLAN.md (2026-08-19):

# KegSensor — Implementation Plan

Part of **Sallaup KegSense**. Weight measurement is the foundational
feature of the whole system — without it, KegDisplay/KegStation/KegTag
have nothing to show. KegSensor is the furthest-along module (PCB
routed, DRC-clean, fab-ready gerbers already exported, see
[`README.md`](README.md)) but **nothing has been built or tested
against real hardware yet**. This plan gets from "designed" to
"validated, measuring a real keg" — one unit first, not all 5 at once,
so the two known hardware assumptions get confirmed before committing
to 5x the cost.

## Phase 1 — Procure for one unit first, on perfboard, not the custom PCB yet

**Prototype on generic perfboard/stripboard first, not the custom
KegSensor PCB.** No fab turnaround, no fab cost, and no risk of paying
to fab a board around an assumption (J6 pin order, SIG_POS/SIG_NEG
pairing — see Phase 2) that turns out wrong. The custom PCB gets
ordered later, in Phase 6, once both the wiring assumptions *and* the
3.5mm-terminal-block layout change are validated.

- 1× generic perfboard/stripboard + hookup wire
- 1× HX711 breakout module
- 4× half-bridge load cells (one keg's worth — FL/FR/BR/BL)
- Screw terminals / headers / RJ14 jack per the Connectors table in
  `README.md` (same parts either way — perfboard or the eventual custom
  PCB, just hand-wired for now instead of routed copper)
- 1× RJ14 cable
- 4× prints of `load-cell-platform/load_cell_holder.scad` (already
  designed) — a base plate to bolt them to is **not** designed yet, see
  Phase 5

## Phase 2 — Resolve the two known assumptions before trusting the board

See "Known assumptions to confirm against real hardware" in
`README.md`:
- Check the actual HX711 module's silkscreen against
  `generate_schematic.py`'s assumed J6 pin order (GND/DT/SCK/VCC) — fix
  and regenerate if different
- Wire per the load-cell kit's own included diagram, note which
  physical corner is which — SIG_POS/SIG_NEG pairing (J1+J3 vs J2+J4)
  depends on this; fix the pairing in `generate_schematic.py` if the
  reading comes out inverted or dead-flat

## Phase 3 — Bench-test the perfboard wiring before mounting anything

- Continuity checks on the hand-wired perfboard (bus connections
  correct, no unwanted shorts) — same spirit as KegHub's own
  bench-test checklist, adapted for a single hand-wired KegSensor
  prototype
- Solder one load cell on, confirm the HX711 output changes sensibly
  under hand pressure — no real weight math yet, just "is this alive"

## Phase 4 — Minimal read-out software (throwaway, not the real daemon)

- A quick script (existing Python HX711 library, or a small bit-bang
  test) on a spare Pi/dev board — just enough to print raw ADC values
  changing under load
- **Not** KegStation's real `pigpio` C daemon (see
  [`../kegstation/README.md`](../kegstation/README.md)) — that's a
  later, separate effort. This is the earliest point "can we measure
  weight at all" gets a real yes/no answer.

## Phase 5 — Full 4-load-cell keg platform + calibration

- Design the base plate the 4 printed holders bolt to (not designed
  yet — only the individual holder is)
- Mount all 4 load cells, wire the complete diagonal pairing, get a
  real combined weight reading
- Validate tare + a known calibration weight → sane, repeatable grams
  reading. This proves the *math* `kegcal` will later formalize (see
  KegStation's README) — the calibration tool itself isn't needed yet,
  just confirmation the sensor+HX711 combination produces trustworthy
  numbers.

## Phase 6 — Only after Phase 5 passes: fab the real PCB, all 5 at once

The perfboard prototype (Phase 1-5) replaces the old "fab 1, validate,
fab 4 more" split — by the time Phase 5 passes, both the wiring
assumptions (Phase 2) and the board layout (3.5mm terminal blocks,
smaller footprint than the original 5.08mm design) are already
validated on perfboard, so there's no more reason to hold back on
ordering all 5 real boards at once.

- Fix `generate_schematic.py` / `generate_pcb.py` for whatever Phase 2
  found, and for the 3.5mm terminal block footprint (see design-change
  note in `README.md`), regenerate gerbers
- DRC/ERC clean check, order all 5 boards
- Assemble, repeat Phase 3's bench checks per board
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

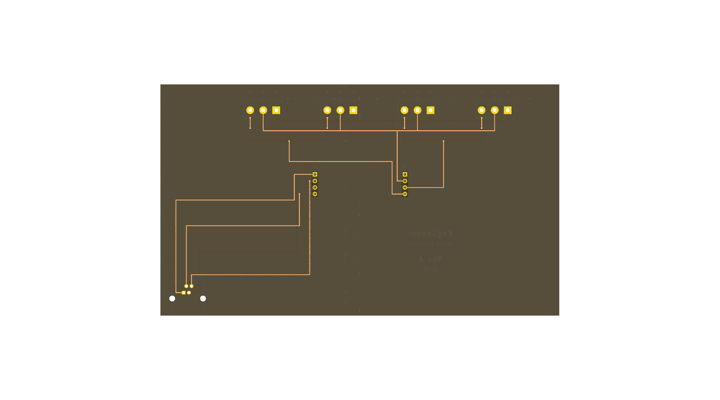
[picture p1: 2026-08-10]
hardware/kegsensor/keg_sensor_module_bottom.png

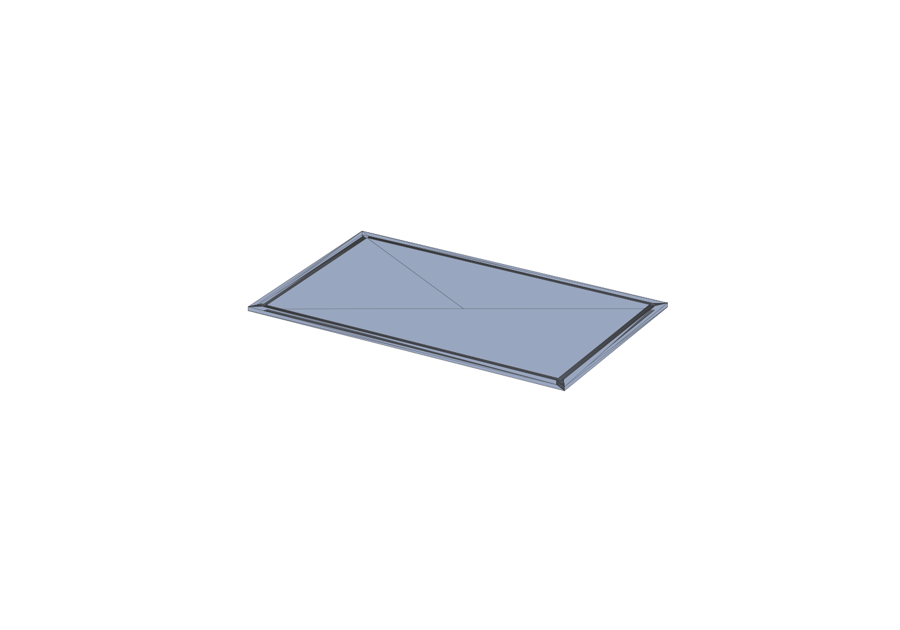
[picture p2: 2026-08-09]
hardware/kegsensor/case_lid_preview.png

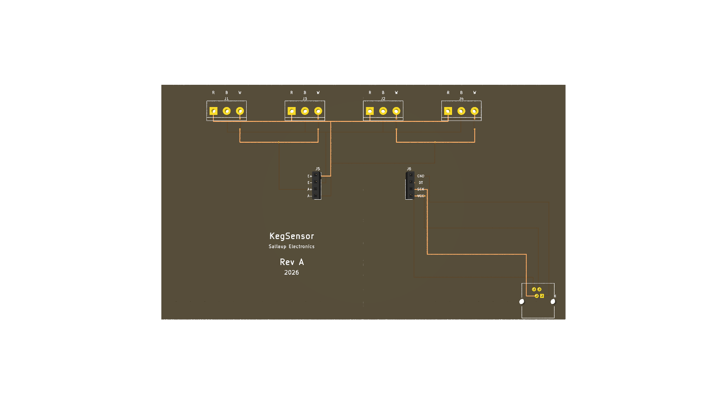
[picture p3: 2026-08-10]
hardware/kegsensor/keg_sensor_module_3d.png

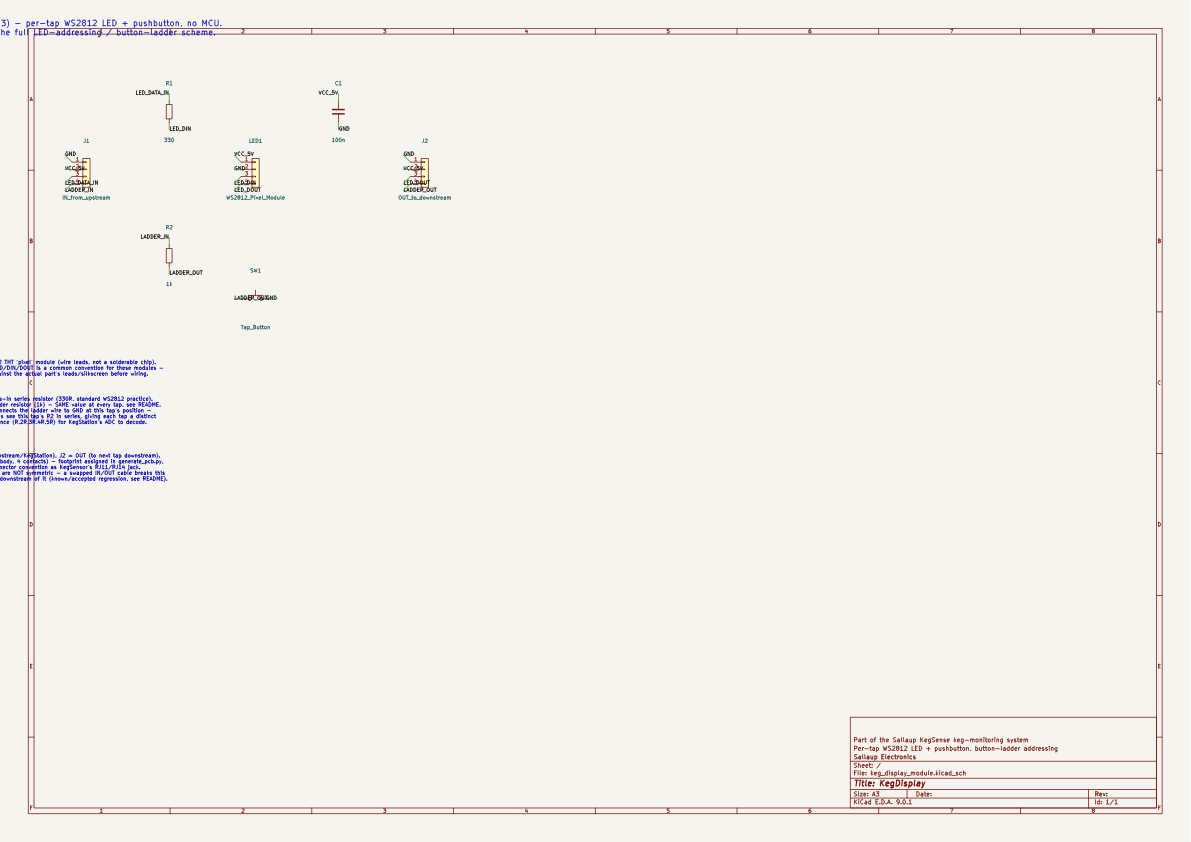
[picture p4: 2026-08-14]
hardware/kegdisplay/keg_display_module_sch.png

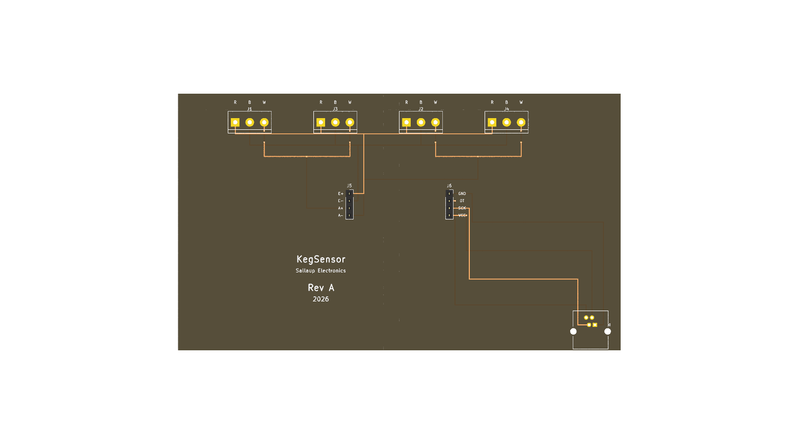
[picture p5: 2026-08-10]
hardware/kegsensor/keg_sensor_module_top.png

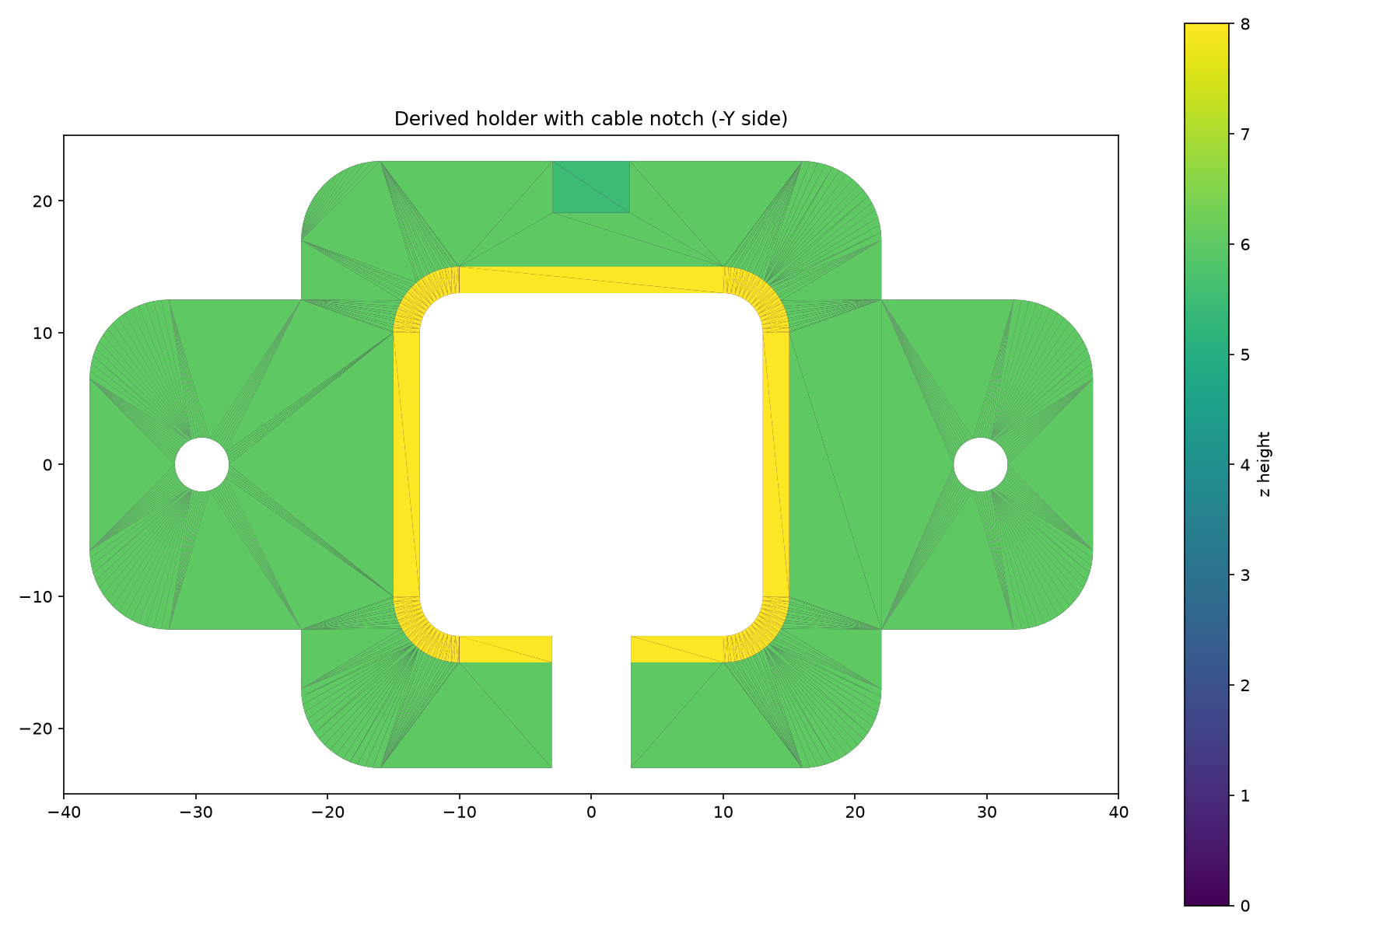
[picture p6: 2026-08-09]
hardware/kegsensor/load-cell-platform/load_cell_holder_cable_notch.png

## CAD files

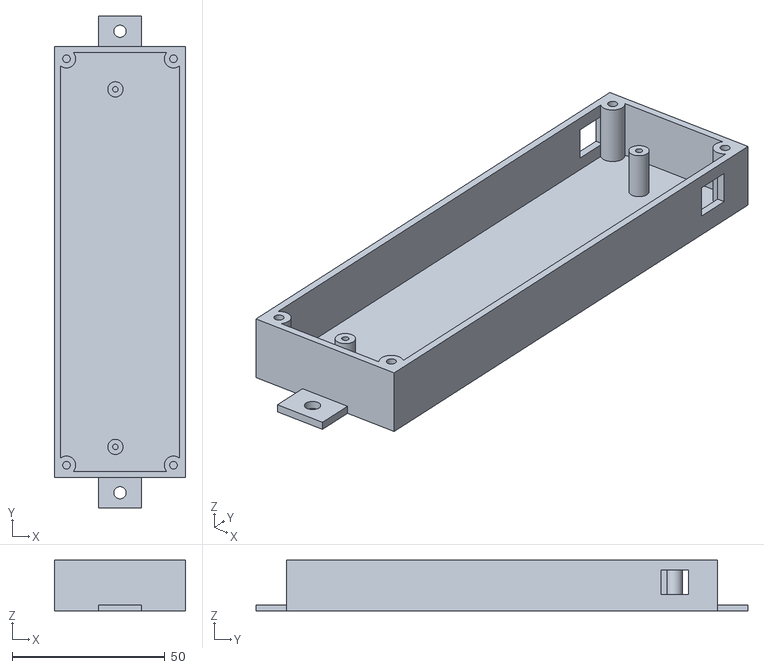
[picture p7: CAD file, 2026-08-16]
hardware/kegdisplay/case_bar_base.stl
43.0 x 161.0 x 16.6

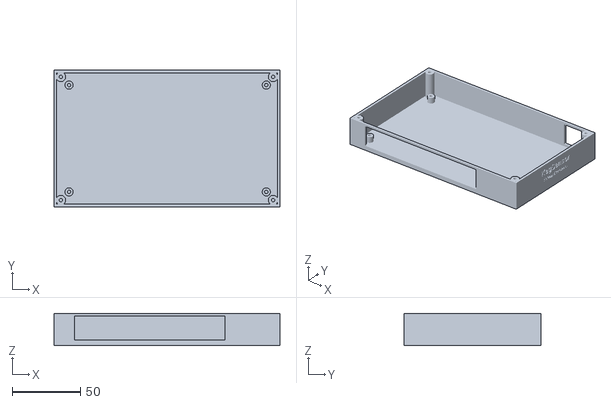
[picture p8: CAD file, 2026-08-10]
hardware/kegsensor/case_base.stl
165.0 x 100.0 x 23.6

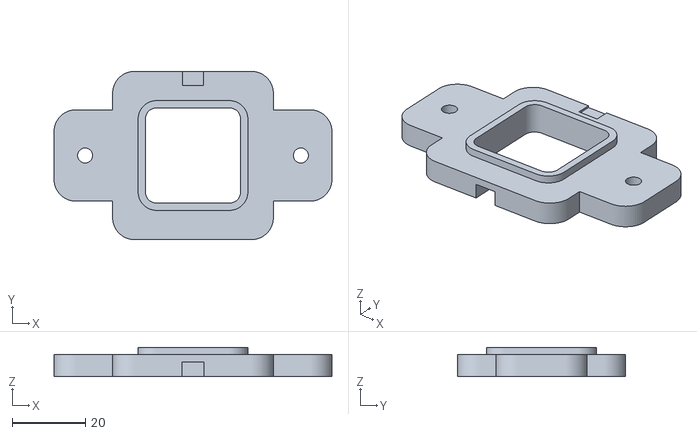
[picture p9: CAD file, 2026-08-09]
hardware/kegsensor/load-cell-platform/load_cell_holder.stl
76.1 x 46.0 x 8.00

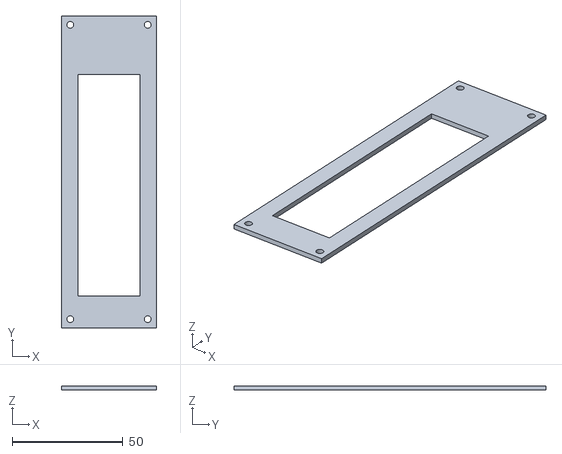
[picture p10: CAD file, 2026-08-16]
hardware/kegdisplay/case_bar_lid.stl
43.0 x 141.0 x 2.00

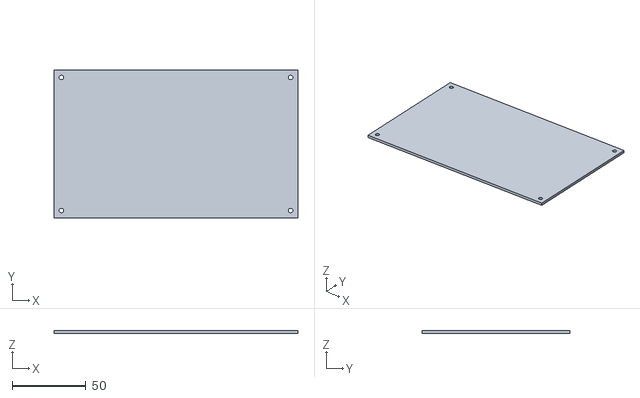
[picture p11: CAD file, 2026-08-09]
hardware/kegsensor/case_lid.stl
165.0 x 100.0 x 2.00

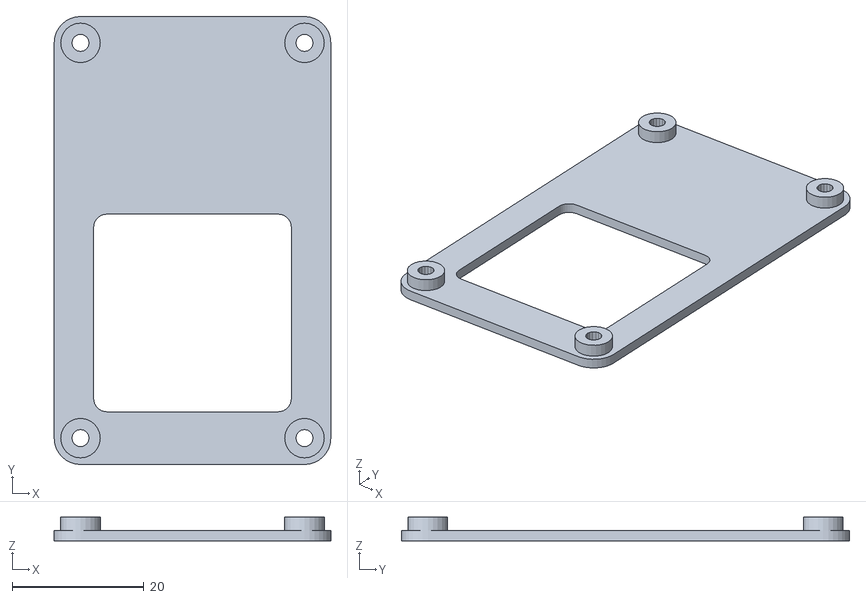
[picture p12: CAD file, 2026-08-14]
hardware/kegdisplay/case_lid.stl
42.0 x 68.0 x 3.60

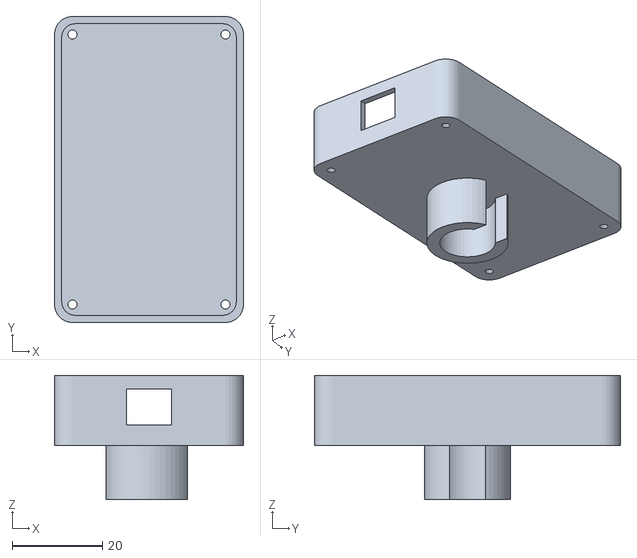
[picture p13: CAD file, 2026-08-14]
hardware/kegdisplay/case_base.stl
42.0 x 68.0 x 27.6

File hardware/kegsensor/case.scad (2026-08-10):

// KegSensor (Sallaup Electronics / Sallaup KegSense) - 3D printable case
// Board: 155 x 90 x 1.6mm, mounting holes (M3 clearance) at (6,6) (150,6)
// (6,84) (150,84) in board-local coords. See keg_sensor_module.kicad_pcb.
//
// Two parts, printed separately: base (this file's default) and lid.
// Render one or the other via the PART variable below, or use
// generate_case.sh which renders both plus an assembled preview.

PART = "base"; // "base" | "lid" | "preview" (assembled, lid made transparent)

// ---- board + layout ---------------------------------------------------
board_w = 155;
board_h = 90;
board_t = 1.6;

mtg_hole_d = 3.4;         // M3 clearance, +0.2mm over the board's 3.2mm hole
mtg_x1 = 6;  mtg_y1 = 6;  // board-local mounting hole centers
mtg_x2 = 150; mtg_y2 = 6;
mtg_x3 = 6;  mtg_y3 = 84;
mtg_x4 = 150; mtg_y4 = 84;

// ---- case shell ---------------------------------------------------------
wall = 2.0;
margin = 3.0;             // gap between board edge and inner wall
floor_t = 2.0;
lid_t = 2.0;

standoff_h = 5.0;         // case floor top -> board bottom
component_clear = 15.0;   // board top -> inside of lid (tallest part: J7 RJ jack)

inner_w = board_w + 2*margin;
inner_h = board_h + 2*margin;
outer_w = inner_w + 2*wall;
outer_h = inner_h + 2*wall;
wall_ht = standoff_h + board_t + component_clear;   // floor top -> rim top

board_x0 = wall + margin;  // board origin, in case-outer coordinates
board_y0 = wall + margin;

// ---- corner lid-mounting posts (at the box's actual corners) ------------
corner_post_d = 7;
corner_post_hole_d = 2.5;  // pilot hole, self-tapping M3
corner_inset = 5;
corner_posts = [
    [corner_inset, corner_inset],
    [outer_w - corner_inset, corner_inset],
    [corner_inset, outer_h - corner_inset],
    [outer_w - corner_inset, outer_h - corner_inset],
];

// ---- PCB standoff posts (at the board's own mounting holes) -------------
standoff_post_d = 6;
standoff_pilot_d = 2.5;
pcb_posts = [
    [board_x0 + mtg_x1, board_y0 + mtg_y1],
    [board_x0 + mtg_x2, board_y0 + mtg_y2],
    [board_x0 + mtg_x3, board_y0 + mtg_y3],
    [board_x0 + mtg_x4, board_y0 + mtg_y4],
];

// ---- connector cutouts ----------------------------------------------------
// J1-J4 sensor wires exit near the board's top edge (board-local x
// 17.28-122.88 - the row's unrotated courtyard span: each part's
// courtyard is 15.6mm wide, 30mm pitch, first at x=20 last at x=110, see
// generate_pcb.py) - cut the case's front wall (y=0, the wall the
// board's own y=0 edge sits against) over that span with margin.
front_cut_x0 = board_x0 + 10;
front_cut_x1 = board_x0 + 120;
front_cut_z0 = floor_t + 2;
front_cut_z1 = floor_t + wall_ht - 2;

// J7 (RJ11 jack, RJ14 footprint) sits flush with the board's bottom edge
// (y=90), rotated so its cable/plug face points +Y - its shell spans
// board-local x=138.27-150.67 (see generate_pcb.py's J7 placement
// comment - read back from actual DRC-reported pad/courtyard
// coordinates, not assumed). Cut the BACK wall (y=outer_h, the wall the
// board's own y=90 edge sits against) over that span with margin.
// Previously flush with the right edge instead, with a right-wall
// cutout - moved when J7 moved to the bottom edge per explicit request.
back_cut_x0 = board_x0 + 131;
back_cut_x1 = board_x0 + 148;
back_cut_z0 = floor_t + 2;
back_cut_z1 = floor_t + wall_ht - 2;

$fn = 48;

module pcb_post(h) {
    difference() {
        cylinder(d = standoff_post_d, h = h);
        translate([0, 0, h - standoff_h + 0.1])
            cylinder(d = standoff_pilot_d, h = standoff_h + 1);
    }
}

module corner_post(h) {
    difference() {
        cylinder(d = corner_post_d, h = h);
        translate([0, 0, h - 8])
            cylinder(d = corner_post_hole_d, h = 8 + 1);
    }
}

module base() {
    difference() {
        union() {
            // floor + walls
            difference() {
                cube([outer_w, outer_h, floor_t + wall_ht]);
                translate([wall, wall, floor_t])
                    cube([inner_w, inner_h, wall_ht + 1]);
            }
            // corner lid posts
            for (p = corner_posts)
                translate([p[0], p[1], 0])
                    corner_post(floor_t + wall_ht);
            // PCB standoff posts (top of post = board bottom = floor_t+standoff_h)
            for (p = pcb_posts)
                translate([p[0], p[1], 0])
                    pcb_post(floor_t + standoff_h);
        }
        // front-wall wire cutout for J1-J4
        translate([front_cut_x0, -1, front_cut_z0])
            cube([front_cut_x1 - front_cut_x0, wall + 2, front_cut_z1 - front_cut_z0]);
        // back-wall cutout for J7 / RJ11 cable
        translate([back_cut_x0, outer_h - wall - 1, back_cut_z0])
            cube([back_cut_x1 - back_cut_x0, wall + 2, back_cut_z1 - back_cut_z0]);
        // engraved branding, both lines on the right wall - the one wall
        // without a connector cutout now that J1-J4 (front) and J7 (back)
        // both claim one. Previously on the back wall, before J7 moved
        // there.
        wall_text_right("KegSensor", 5, text_z + 3.3, false);
        wall_text_right("Sallaup Electronics", 2.6, text_z - 3, true);
    }
}

// Engraved (recessed) branding on the back wall (y=outer_h) - the one
// wall without a connector cutout, now that J1-J4 (front) and J7 (back)
// both claim one. 0.6mm deep into the 2mm wall (1.4mm remains - plenty
// strong), centered vertically in the same safe z-band as the connector
// cutouts (floor_t+2 .. floor_t+wall_ht-2) and horizontally clear of the
// corner posts.
engrave_d = 0.6;
text_z = floor_t + wall_ht / 2;

// Getting front/back right took two iterations of actually rendering and
// checking (a true 2D orthographic projection of just the wall in
// question, not eyeballing a 3D perspective view - that first misled me
// into "fixing" this with a 180deg rotation, which turned out to swap the
// wrong axis). Two different corrections were needed, for two different
// reasons:
//  - front wall: rotate([-90,0,0]) alone renders text upside down (letters
//    vertically flipped) - mirror([0,1,0]) on the text before extrusion
//    fixes it.
//  - back wall: rotate([90,0,0]) alone renders letters right-side up and
//    in the same left-to-right order as world +X - but a viewer actually
//    standing behind the box looking at that face has their own "right"
//    pointing in world -X (they're facing the opposite direction), so
//    text in unflipped +X order reads backwards *to them* even though the
//    raw geometry isn't mirrored. mirror([1,0,0]) corrects for that.
// wall_text_front/back are both unused now (branding moved to the right
// wall below) but kept in case a wall needs text again later - each
// still needs its own from-scratch verification if reused, not just
// reasoning by analogy from another wall (that's exactly what went wrong
// here the first time).
module wall_text_front(msg, size, z = text_z, italic = false) {
    // front wall, exterior face at y=0 - cutter pokes out to y=-0.1 for a
    // clean boolean and goes engrave_d into the wall (+Y).
    style = italic ? "Italic" : "Bold";
    translate([outer_w / 2, -0.1, z])
        rotate([-90, 0, 0])
            linear_extrude(height = engrave_d + 0.1)
                mirror([0, 1, 0])
                    text(msg, size = size, halign = "center", valign = "center",
                         font = str("Liberation Sans:style=", style));
}

module wall_text_back(msg, size, z = text_z, italic = false) {
    // back wall, exterior face at y=outer_h - cutter pokes out to
    // y=outer_h+0.1 and goes engrave_d into the wall (-Y).
    style = italic ? "Italic" : "Bold";
    translate([outer_w / 2, outer_h + 0.1, z])
        rotate([90, 0, 0])
            linear_extrude(height = engrave_d + 0.1)
                mirror([1, 0, 0])
                    text(msg, size = size, halign = "center", valign = "center",
                         font = str("Liberation Sans:style=", style));
}
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

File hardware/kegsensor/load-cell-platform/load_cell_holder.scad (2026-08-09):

// Load cell holder - derived from a third-party Printables design
// (https://www.printables.com/model/157473-load-cell-holder), reverse
// measured from the downloaded STL rather than guessed - see the
// measurement commands in project history / commit message for how each
// number below was extracted (2D cross-section slices + point-cloud
// analysis of the actual mesh, not eyeballed).
//
// This is a FAITHFUL FUNCTIONAL recreation (same envelope, hole
// positions/sizes, pocket opening, general thickness) expressed as
// editable OpenSCAD instead of an opaque STL, matching how the rest of
// this project's parts are built (case.scad, generate_pcb.py). It is
// NOT a byte-identical mesh clone - fine fillet/lip details are
// approximated. Validate print fit against the original STL
// (load-cell-platform/load_cell_holder_reference.stl) before relying on this
// for a real build.
//
// Snap-fit bracket: two outer ears bolt down to a base plate: the load
// cell itself snaps into the central pocket, gripped by the raised lip
// around it and able to flex slightly thanks to the seam slit at the
// pocket's top edge.

// ---- measured dimensions -------------------------------------------
ear_thickness = 6.0;       // ear tab thickness (measured: ~5.9-6.0mm)
lip_height = 2.0;          // raised pocket lip, on top of ear_thickness
                            // (total part height measured as 8.01mm)

collar_half_w = 22.0;      // central collar half-width (x)
collar_half_h = 23.02;     // central collar half-height (y) - measured
collar_corner_r = 6.0;     // approximate corner rounding

ear_half_h = 12.51;        // ear tab half-height (y) - measured
ear_outer_x = 38.04;       // ear tip x-extent (half of 76.08mm total)
ear_corner_r = 6.0;        // approximate ear end rounding

bolt_hole_x = 29.53;       // bolt hole x position - measured
bolt_hole_r = 2.05;        // bolt hole radius - measured (~M4 clearance)

pocket_half = 13.01;       // pocket opening half-width/height (26.03mm
                            // square) - measured
pocket_corner_r = 3.0;     // approximate pocket corner rounding

seam_half_w = 2.92;        // split-seam slit half-width - measured
seam_y0 = 19.1;            // seam starts at this y (measured) ...
seam_y1 = collar_half_h + 1;  // ... through the outer edge

// ---- added feature: cable exit notch (not present in the original) --
// The original design has NO cable exit - confirmed directly (2D
// cross-section + top-down height projection), not assumed: the pocket
// is fully enclosed on all 4 sides, and the flex-seam slit above does
// not reach the pocket opening (there's solid material between them).
// Without this, a cable coming off the load cell would have to share
// the same ~26x26mm pocket opening as the load cell body itself.
// Placed on the -Y side (opposite the seam slit at +Y) so the two
// features stay clearly separated. Half the part's total height, at the
// bottom (z=0 up), not full height - leaves solid material above it as
// a roof over the cable exit.
cable_notch_half_w = 3.0;  // 6mm wide - fits a small multi-conductor cable
cable_notch_y0 = -pocket_half + 1;   // starts just inside the pocket edge
cable_notch_y1 = -collar_half_h - 1; // ... through the outer collar edge
cable_notch_height = (ear_thickness + lip_height) / 2;  // half of 8mm = 4mm

$fn = 64;

module rounded_rect(w, h, r) {
    offset(r = r)
        offset(delta = -r)
            square([w, h], center = true);
}

module outline_2d() {
    // Ear tabs overlap deep into the collar (starting well inside its
    // half-width, not right at the edge) so their rounded corners land
    // entirely within the collar's solid area instead of both shapes'
    // roundings landing at the same seam and leaving a gap there - first
    // version of this had exactly that bug, caught by rendering and
    // comparing against the original rather than trusting it blind.
    ear_inner_x = collar_half_w * 0.4;
    union() {
        rounded_rect(collar_half_w * 2, collar_half_h * 2, collar_corner_r);
        translate([(ear_inner_x + ear_outer_x) / 2, 0])
            rounded_rect(ear_outer_x - ear_inner_x, ear_half_h * 2, ear_corner_r);
        translate([-(ear_inner_x + ear_outer_x) / 2, 0])
            rounded_rect(ear_outer_x - ear_inner_x, ear_half_h * 2, ear_corner_r);
    }
}

module pocket_2d() {
    rounded_rect(pocket_half * 2, pocket_half * 2, pocket_corner_r);
}

module holder() {
    difference() {
        union() {
            // base body (ears + collar), to ear_thickness
            linear_extrude(height = ear_thickness)
                difference() {
                    outline_2d();
                    pocket_2d();
                }
            // raised lip around the pocket, on top of the base body
            translate([0, 0, ear_thickness])
                linear_extrude(height = lip_height)
                    difference() {
                        offset(r = 2) pocket_2d();  // lip wall ~2mm thick
                        pocket_2d();
                    }
        }
        // bolt holes, through everything
        translate([bolt_hole_x, 0, -1])
            cylinder(r = bolt_hole_r, h = ear_thickness + 2);
        translate([-bolt_hole_x, 0, -1])
            cylinder(r = bolt_hole_r, h = ear_thickness + 2);
        // split-seam flex slit, through the lip at the pocket's top edge
        translate([-seam_half_w, seam_y0, ear_thickness - 0.5])
            cube([seam_half_w * 2, seam_y1 - seam_y0, lip_height + 1]);
        // cable exit notch (added - see comment above), half height, at
        // the bottom (z=-1 for a clean cut through the bottom face, up
        // to cable_notch_height above z=0)
        translate([-cable_notch_half_w, cable_notch_y1, -1])
            cube([cable_notch_half_w * 2, cable_notch_y0 - cable_notch_y1,
                  cable_notch_height + 1]);
    }
}

holder();

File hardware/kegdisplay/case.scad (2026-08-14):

// KegDisplay (Sallaup Electronics / Sallaup KegSense) - 3D printable case
// CONCEPT SKETCH, not a board-fitted enclosure yet. keg_display_module.kicad_pcb
// is currently 160x120mm - a generous first-pass ROUTING board, explicitly not
// size-optimized (see hardware/kegdisplay/README.md). This sketches the
// TARGET size/shape a size-optimized respin should aim for instead.
//
// Two explicit constraints driving this version (both from user feedback on
// the first sketch, which was tap-mounted with a small OLED window in a much
// bigger box):
//   1. NOT tap-mounted - no clip/bracket modeled here. Physical mounting is
//      still genuinely undecided (see README "Still open"); this version
//      just leaves the back plain rather than guessing again.
//   2. The OLED should cover most of the front face, not sit as a small
//      window in a big box.
//
// That second constraint is a real trade-off, not just a cosmetic tweak: the
// front footprint is sized to the OLED module (~28x28mm) rather than to the
// Arduino Nano (18x45mm on its headers), which is physically the bigger
// part. To still fit the Nano, it has to stand on edge BEHIND the display
// (its 45mm length running front-to-back, along the case's depth) instead of
// lying flat in the same plane as the OLED - which makes this case a deep,
// squarish "puck" (~34x34mm face, ~55mm deep) rather than a thin slab. A
// thinner case is possible, but only by letting the OLED go back to being a
// smaller fraction of a wider front face - flagging that trade explicitly
// rather than quietly picking one.

PART = "base"; // "base" | "lid" | "preview" (assembled, lid made transparent)

// ---- case shell (target size, not board-driven yet) --------------------
// Front footprint set by the OLED module, not the Nano - see header note.
outer_w = 34;
outer_h = 34;
wall = 1.6;
floor_t = 2.0;              // back plate
lid_t = 1.6;                // front plate (mostly cut away by the OLED window)
wall_ht = 50;                // cavity depth - Nano standing on edge (~45mm) + clearance

inner_w = outer_w - 2*wall;
inner_h = outer_h - 2*wall;

// ---- OLED window (front) ------------------------------------------------
// 0.96" SSD1306 active area is ~21.7x11.2mm, but the module's PCB (what the
// window needs to clear, not just the pixels) runs closer to 27.8x27.3mm on
// common breakouts - window sized just inside that, centered, so only a
// ~2mm bezel remains around it.
oled_w = 30;
oled_h = 30;
oled_x = (outer_w - oled_w) / 2;
oled_y = (outer_h - oled_h) / 2;

// ---- RJ12 daisy-chain cable cutouts ----------------------------------
// On the left/right side walls, near the BACK (away from the display face) -
// upstream in one side, downstream out the other.
rj12_cut_w = 10;   // along the wall's own face (Y)
rj12_cut_h = 8;    // height (Z)
rj12_cut_z = floor_t + wall_ht - 14;

// ---- corner lid-mounting posts ------------------------------------------
corner_post_d = 5;
corner_post_hole_d = 2;    // pilot hole, self-tapping M2
corner_inset = 4;
corner_posts = [
    [corner_inset, corner_inset],
    [outer_w - corner_inset, corner_inset],
    [corner_inset, outer_h - corner_inset],
    [outer_w - corner_inset, outer_h - corner_inset],
];

module rounded_rect(w, h, r) {
    hull() {
        for (dx = [r, w - r])
            for (dy = [r, h - r])
                translate([dx, dy]) circle(r = r, $fn = 32);
    }
}

module cavity() {
    translate([wall, wall, 0])
        linear_extrude(height = wall_ht + 1)
            rounded_rect(inner_w, inner_h, 3);
}

module base() {
    difference() {
        union() {
            linear_extrude(height = floor_t + wall_ht)
                rounded_rect(outer_w, outer_h, 4);
            // corner posts for lid screws
            for (p = corner_posts)
                translate([p[0], p[1], floor_t])
                    cylinder(d = corner_post_d, h = wall_ht, $fn = 24);
        }
        // hollow out the interior, leaving the floor
        translate([0, 0, floor_t]) cavity();
        // pilot holes down through the posts
        for (p = corner_posts)
            translate([p[0], p[1], -1])
                cylinder(d = corner_post_hole_d, h = floor_t + wall_ht + 2, $fn = 16);
        // RJ12 cable cutouts, left/right walls near the back
        translate([-0.5, (outer_h - rj12_cut_w) / 2, rj12_cut_z])
            cube([wall + 1, rj12_cut_w, rj12_cut_h]);
        translate([outer_w - wall - 0.5, (outer_h - rj12_cut_w) / 2, rj12_cut_z])
            cube([wall + 1, rj12_cut_w, rj12_cut_h]);
    }
}

module lid() {
    difference() {
        union() {
            linear_extrude(height = lid_t)
                rounded_rect(outer_w, outer_h, 4);
            // screw bosses matching the base's corner posts
            for (p = corner_posts)
                translate([p[0], p[1], lid_t])
                    cylinder(d = corner_post_d + 1, h = 2, $fn = 24);
        }
        // OLED viewing window
        translate([oled_x, oled_y, -1])
            linear_extrude(height = lid_t + 2)
                rounded_rect(oled_w, oled_h, 2);
        // screw clearance holes through the bosses
        for (p = corner_posts)
            translate([p[0], p[1], -1])
                cylinder(d = corner_post_hole_d + 0.6, h = lid_t + 4, $fn = 16);
    }
}

if (PART == "base") {
    base();
} else if (PART == "lid") {
    lid();
} else {
    // assembled preview - lid shown translucent, offset for visibility
    color("lightgray") base();
    translate([0, 0, floor_t + wall_ht + 0.2])
        color([0.2, 0.6, 0.9, 0.35]) lid();
}

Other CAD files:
hardware/kegdisplay/case_bar.scad

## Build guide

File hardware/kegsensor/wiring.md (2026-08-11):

# KegSensor Wiring

**Sallaup Electronics** — part of the **Sallaup KegSense** keg-monitoring
system.

Covers the sensor layer: per-keg load cell + HX711 (the **KegSensor**
module — carrier board in this same directory), and the RJ11 run out to
**KegHub** (the in-keezer passive wiring panel — see
[`../keghub/`](../keghub/)). KegHub's own wiring and its RJ45 run out to
**KegStation** (the external Raspberry Pi central unit — see
[`../kegstation/`](../kegstation/)) is documented there.

- No WiFi/radio inside or on the keezer.
- 3.3V logic system-wide (Raspberry Pi GPIO is not 5V-tolerant).
- Shared SCK across all 5 HX711 modules; each keg keeps its own DT line.

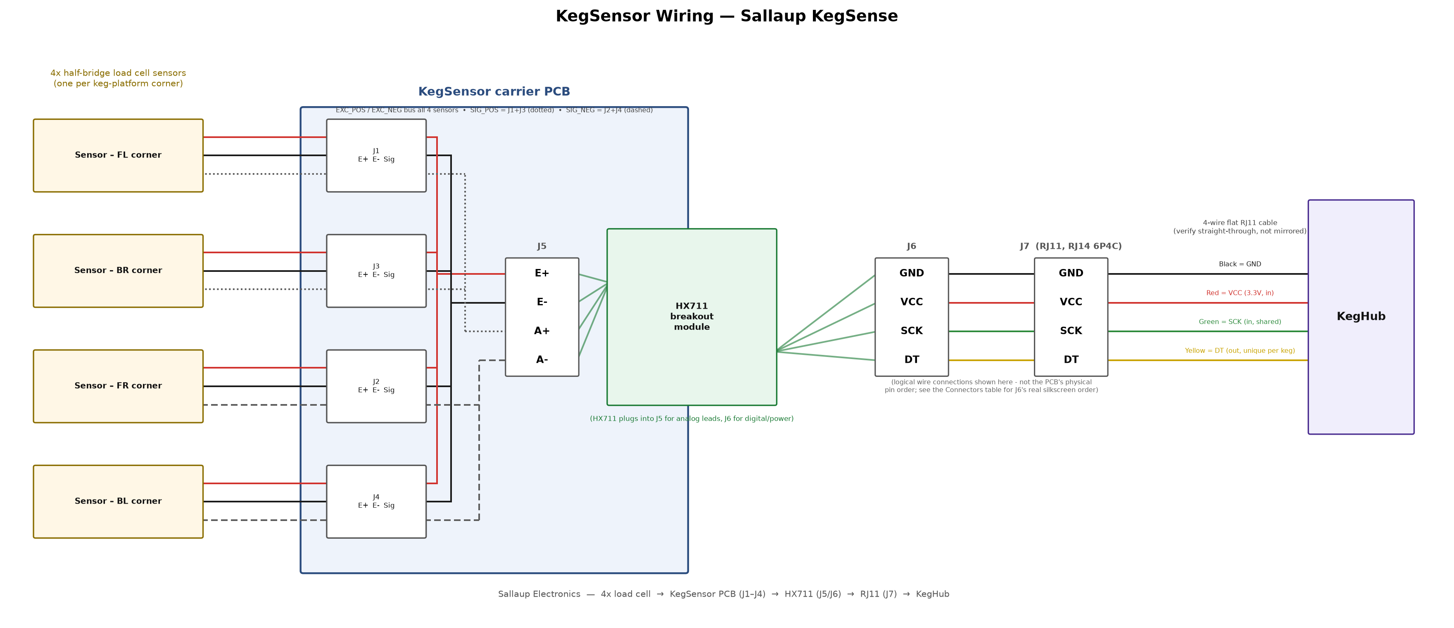
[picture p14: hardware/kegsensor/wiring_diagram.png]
KegSensor wiring: 4 load cell sensors through the KegSensor PCB (J1-J4), HX711 (J5/J6), RJ11 (J7), out to KegHub


Generated by `generate_wiring_diagram.py` (matplotlib) — regenerate after
editing that script with `python3 generate_wiring_diagram.py`. Every
signal path, pin label, and wire color in the diagram matches the tables
below directly, not hand-drawn separately from them — with one
deliberate exception: J6 is drawn as GND/VCC/SCK/DT (matching J7's order,
so the connecting lines run straight instead of crossing), not the PCB's
actual silkscreen order (GND/DT/SCK/VCC — see the Connectors table
below). The diagram shows logical wire connections, not a literal
pin-position map of the real header; check the Connectors table or the
physical board itself before wiring against J6, not this picture.

## Per-keg module

**Sensor: HX711 Module + 4 Pcs 50kg Half-Bridge Strain Gauge set (YEMAA or
equivalent).** Each half-bridge sensor is only half a Wheatstone bridge —
it takes all 4 from one set, mounted at the 4 corners of a small platform
(same construction as the inside of a DIY bathroom scale), to form one
complete bridge for one HX711 channel. One set = one keg's platform; for 5
kegs, buy 5 full sets (5× HX711 + 20× sensors total), not 5 individual
sensors.

Combiner wiring (sensor → HX711), typical for this style of kit:
- Each sensor has 3 leads: Red = E+, Black = E-, White = Signal.
- All 4 Red leads bus together → HX711 E+. All 4 Black leads bus together
  → HX711 E-. This shares excitation voltage across all 4 corners.
- The 4 White (signal) leads split into two pairs → HX711 A+ and A-,
  based on which diagonal corners the sensor is mounted at. This pairing
  is orientation-dependent — follow the wiring diagram included with the
  kit rather than guessing, since getting it backwards reads as a
  negative/inverted or dead-flat signal rather than a clean failure.
- Platform construction: a rigid top plate (keg sits here) and bottom
  plate (rests on the keezer floor), with the 4 sensors sandwiched at the
  corners between them — the same structural idea as a bathroom scale.
  See [`load-cell-platform/`](load-cell-platform/) for the load cell
  holder that mounts at each corner.

HX711 mounts on or right next to this platform (keep the sensor-to-HX711
leads short); only the HX711's own 4-wire digital output goes out over the
RJ11 cable — never the raw sensor leads.

Power the HX711 at **3.3V** (confirm the specific breakout supports it —
most do, per HX711 datasheet's 2.6–5.5V VCC range).

### Carrier PCB

This directory has a KiCad 9 project (schematic + routed 2-layer PCB)
implementing all of the above as a small per-keg carrier board: 4× screw
terminals for the sensors (bussing E+/E- across all 4, splitting the
diagonal-paired signal leads to A+/A-), a female header that the HX711
breakout module plugs into, and an RJ11 jack out to KegHub. See
[`README.md`](README.md) for fabrication details, known assumptions, and
validation performed.

**Cable orientation caution**: a flat 4-wire RJ11 cable only preserves the
color convention end-to-end if it's wired "straight through" — the same
common gotcha as old telephone extension cables, where crimping both plugs
facing the same way on a flat cable actually mirrors the pin order at one
end. Before trusting the color convention, verify with a continuity tester
that Black↔Black, Red↔Red, Green↔Green, Yellow↔Yellow end-to-end on every
keg cable, not just Black↔Yellow-reversed.

From the HX711, run a standard 4-wire flat silver-satin RJ11 cable to
KegHub, using this fixed color convention on every keg:

| Wire color | Signal |
|---|---|
| Black | GND |
| Red | VCC (3.3V, in from KegHub) |
| Green | SCK (shared clock, in from KegHub) |
| Yellow | DT (data out to KegHub — unique per keg) |

Wiring every keg identically to this color convention means a keg module
can be swapped to any KegHub jack without needing to relabel/recheck wiring.

## Parts list (per-keg / KegSensor side)

- 5× "HX711 Module + 4 Pcs 50kg Half-Bridge Strain Gauge" sets (YEMAA or
  equivalent) — 5× HX711 + 20× half-bridge sensors total, one set per keg
  platform (verify 50kg rating covers your heaviest full keg)
- 5× rigid top/bottom plate pairs to build each keg's sensor platform
- 5× RJ11 4-wire flat cables with molded plugs (keg side)
- Silicone-insulated (cold-rated) hookup wire for all in-keezer wiring

See [`../keghub/README.md`](../keghub/README.md) for the KegHub-side parts
list (jacks, panel, RJ45 patch cable) and the bench-test checklist that
covers the full sensor-to-KegHub-to-KegStation path.

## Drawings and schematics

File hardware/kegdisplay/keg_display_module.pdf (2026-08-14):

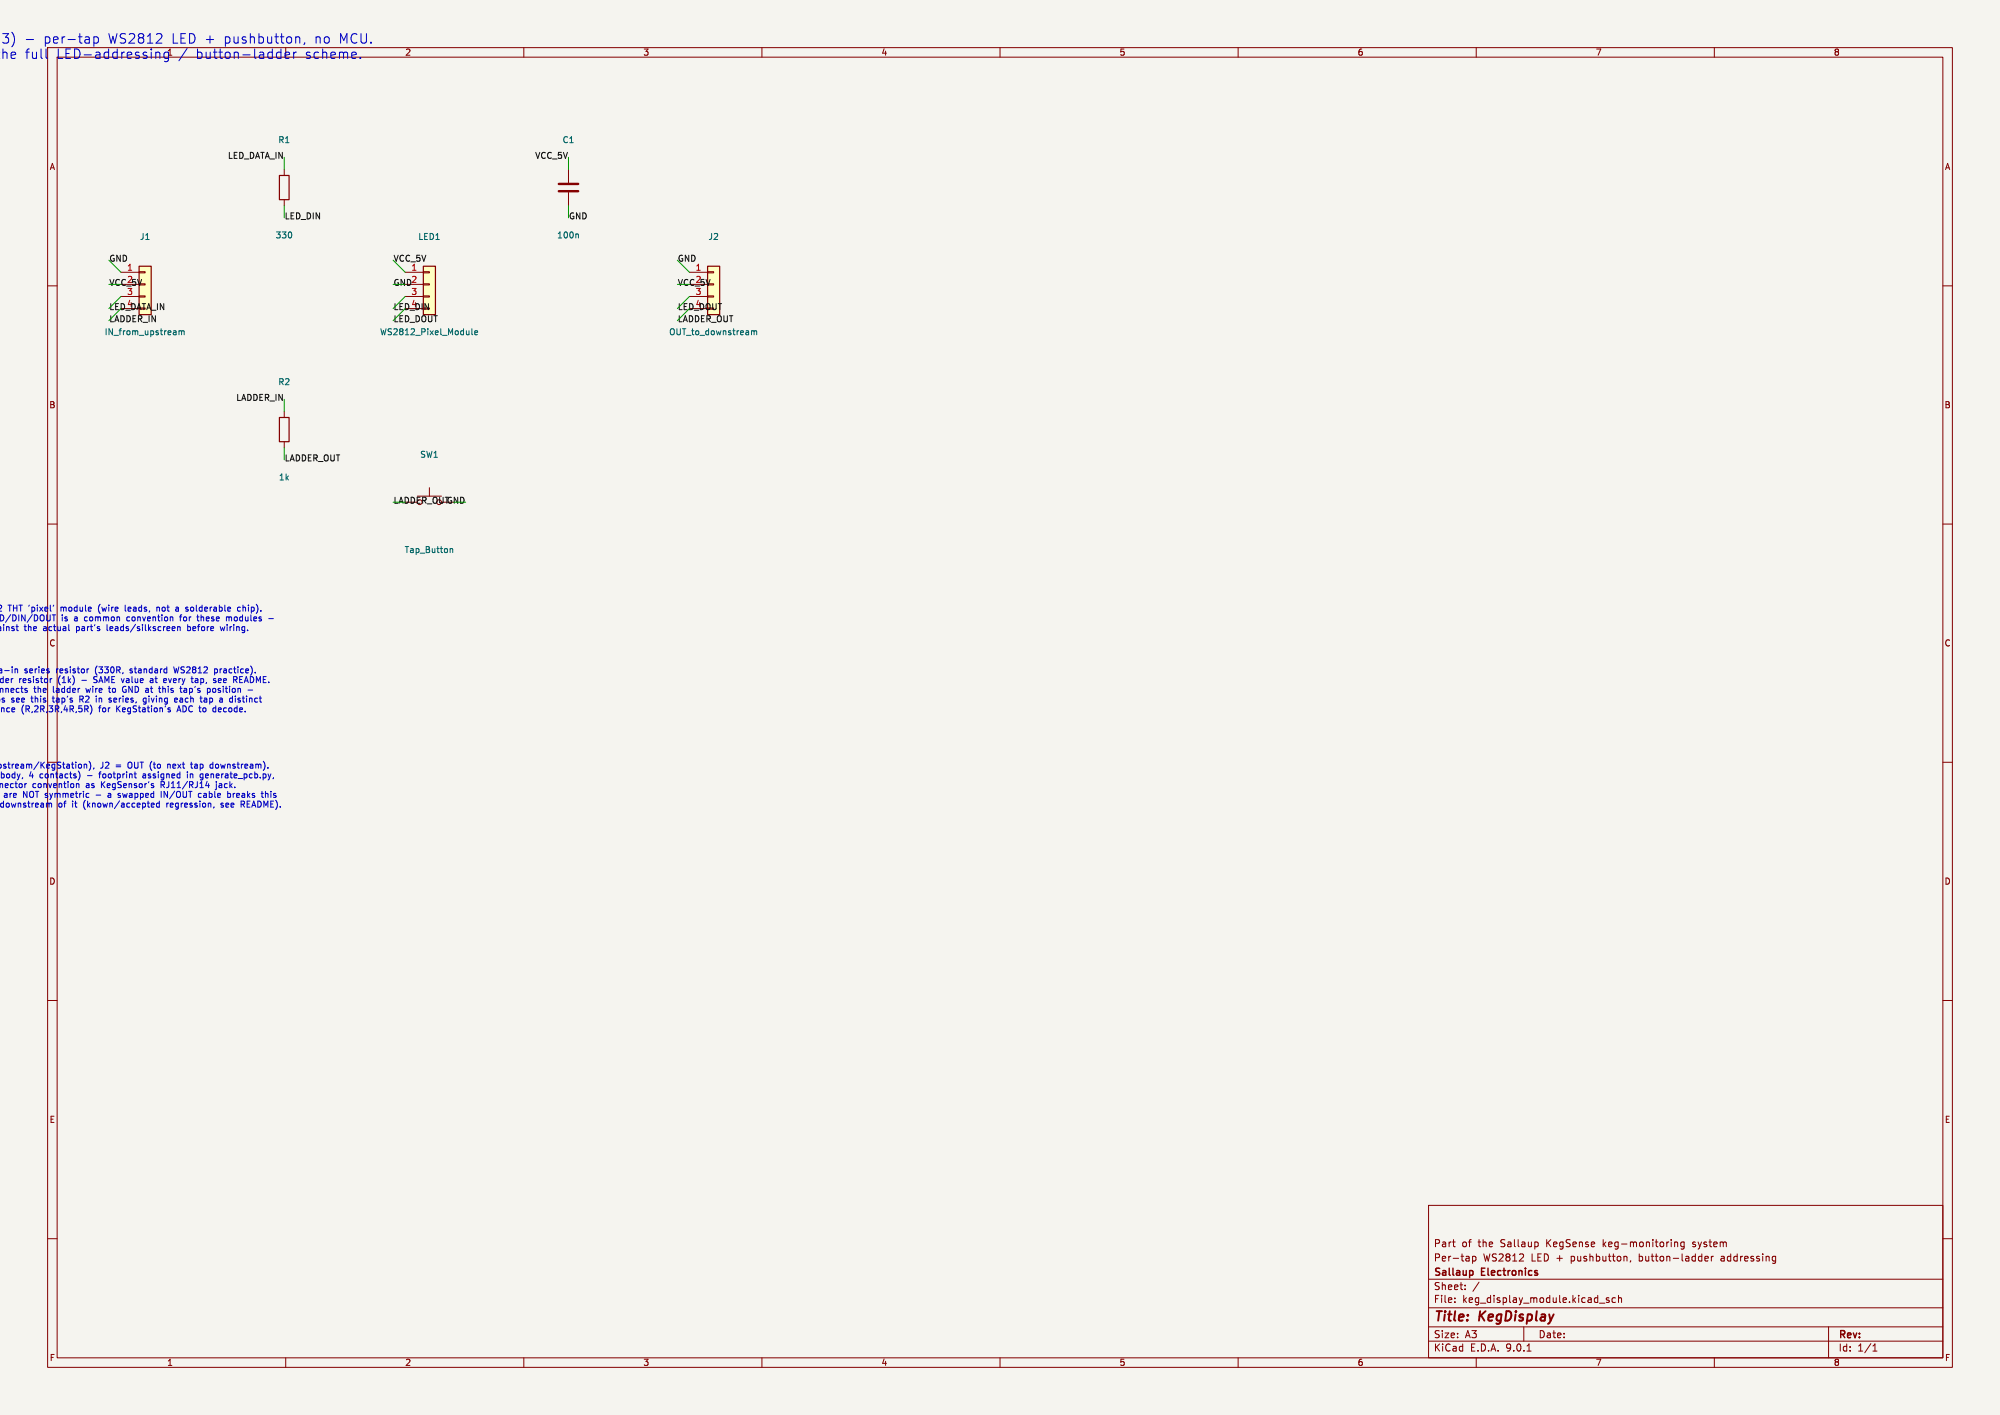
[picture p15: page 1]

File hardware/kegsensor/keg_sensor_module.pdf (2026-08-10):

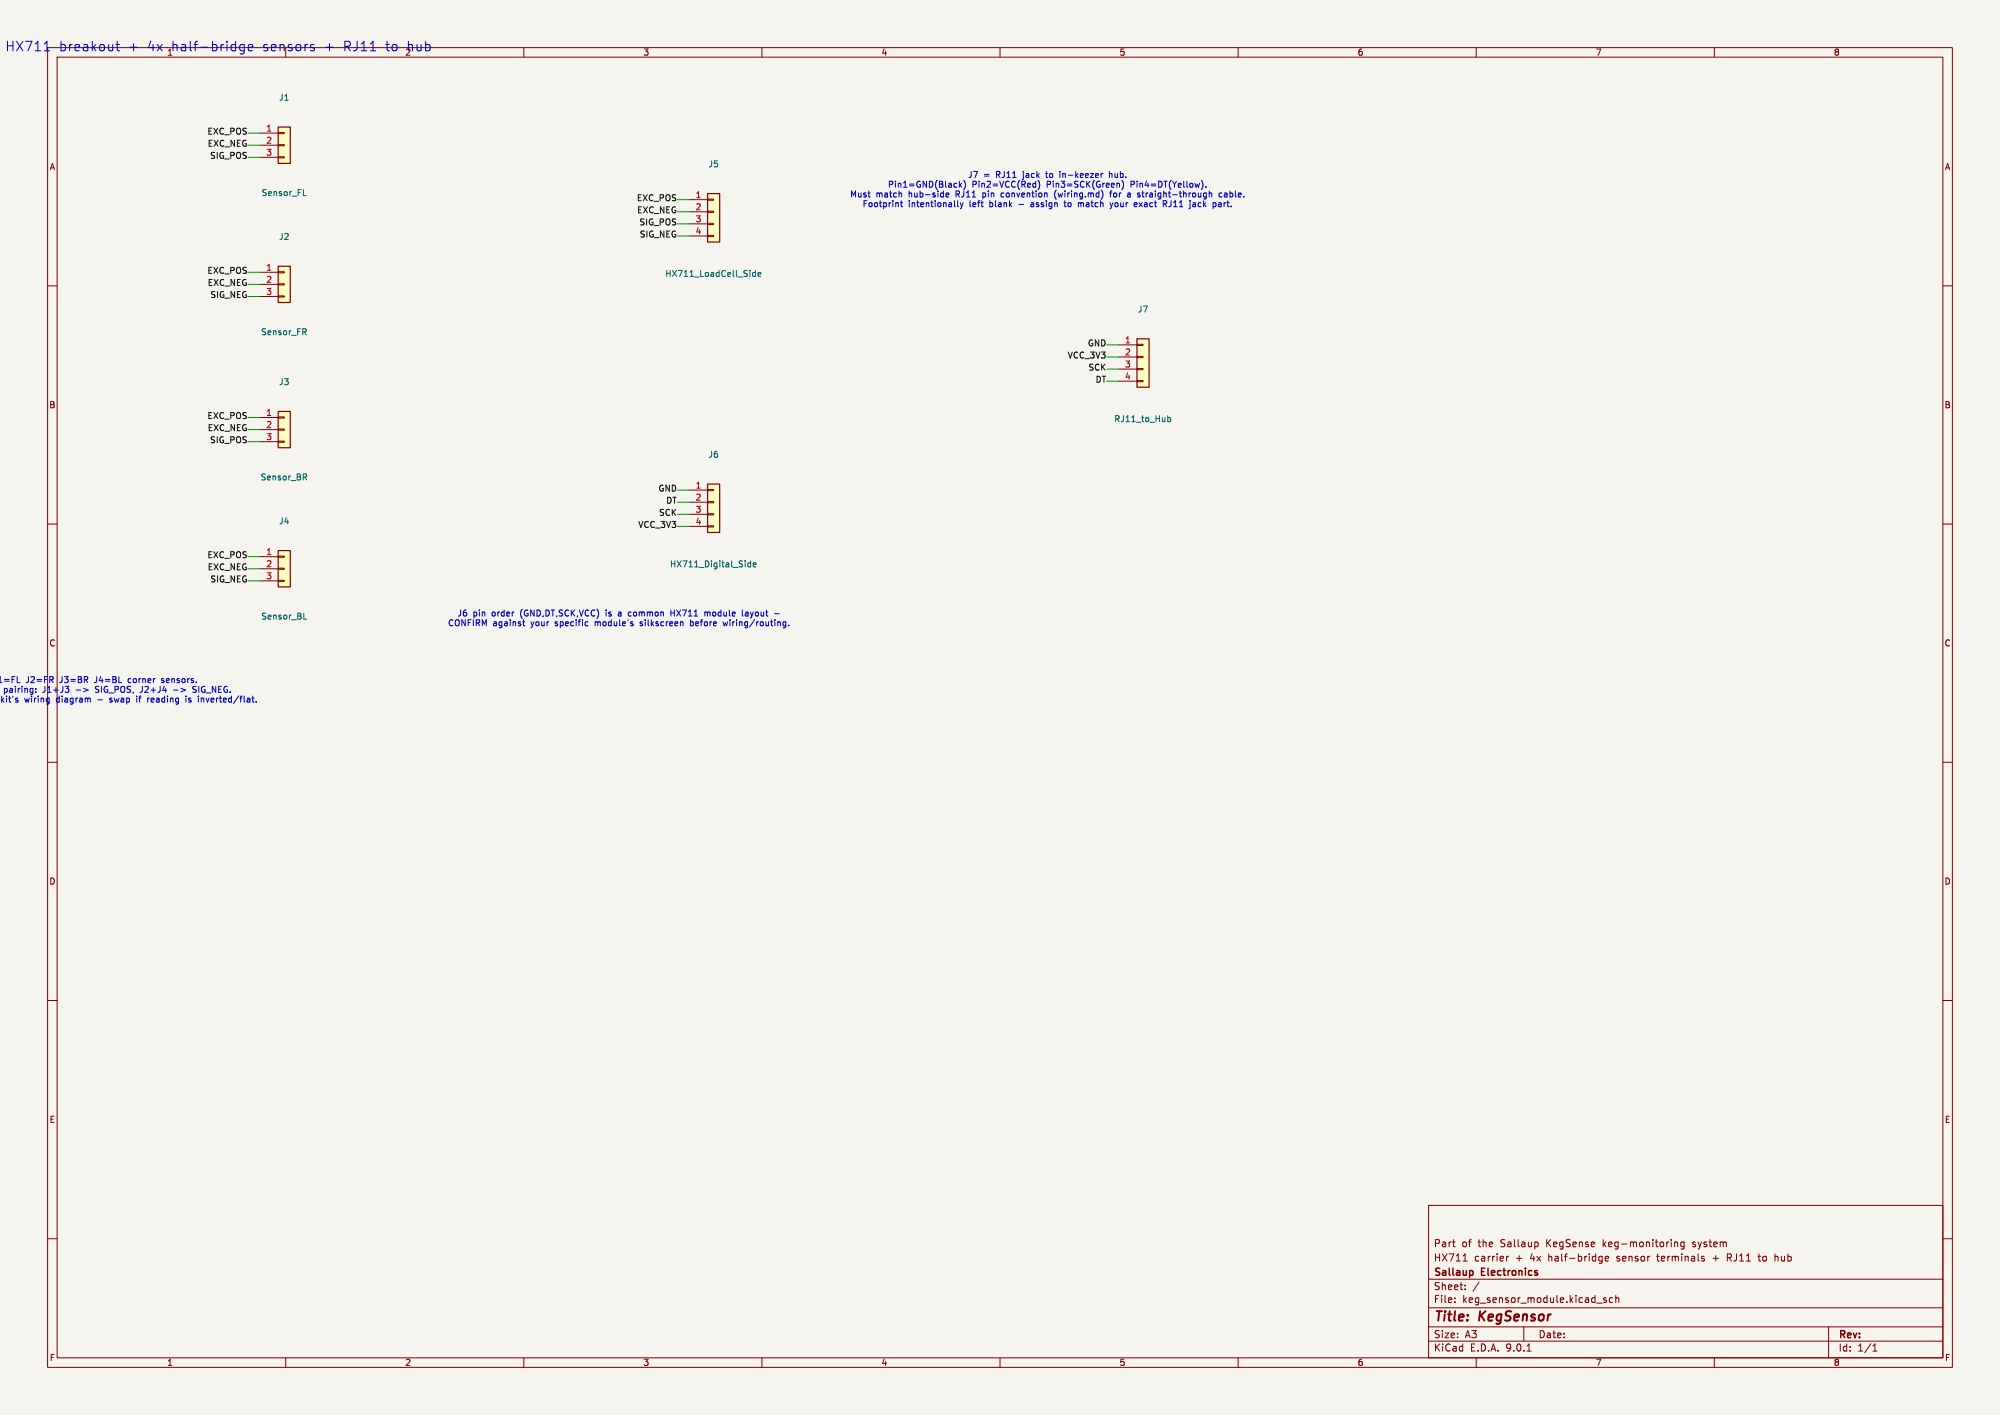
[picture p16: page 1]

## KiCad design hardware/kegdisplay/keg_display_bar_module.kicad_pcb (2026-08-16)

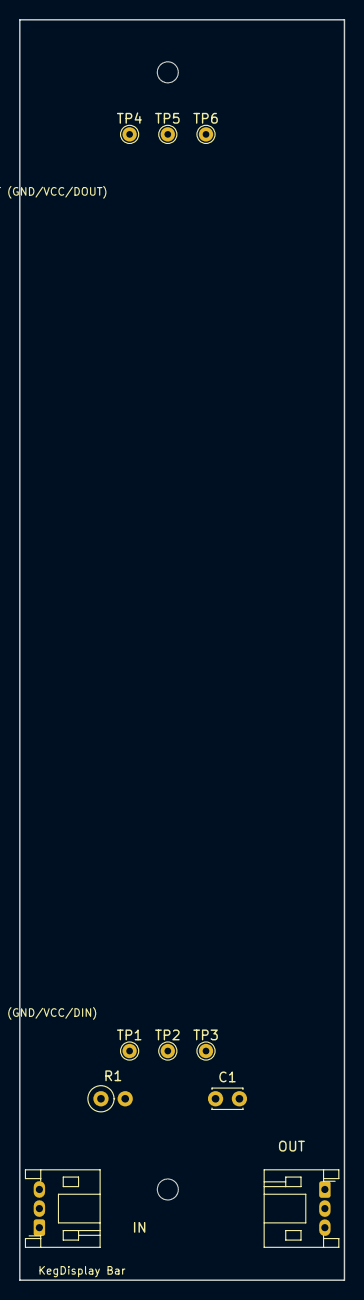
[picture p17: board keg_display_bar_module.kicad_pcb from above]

Board: 2 copper layers, 34.0 x 132.0 mm, 12 parts (0 on the bottom side), 5 nets, no tracks yet.

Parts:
C1: C_Disc_D3.0mm_W2.0mm_P2.50mm
J1, J2: JST_PH_S3B-PH-K_1x03_P2.00mm_Horizontal
MH1, MH2: MountingHole_2.2mm_M2
R1: R_Axial_DIN0207_L6.3mm_D2.5mm_P2.54mm_Vertical
TP1, TP2, TP3, TP4, TP5, TP6: TestPoint_THTPad_D1.5mm_Drill0.7mm

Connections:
DATA_0: J1.3, R1.1
DATA_1: R1.2, TP3.1
DATA_OUT: J2.3, TP6.1
GND: C1.2, J1.1, J2.1, TP1.1, TP4.1
VCC: C1.1, J1.2, J2.2, TP2.1, TP5.1

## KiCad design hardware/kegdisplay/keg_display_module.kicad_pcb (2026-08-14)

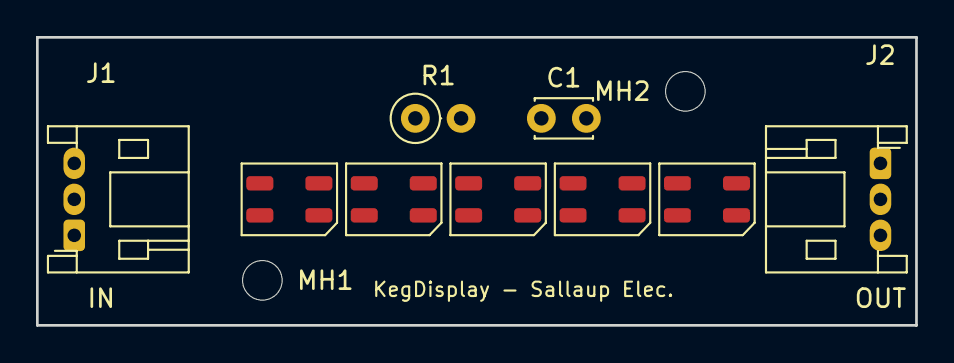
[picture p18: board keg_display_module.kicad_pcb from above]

Board: 2 copper layers, 48.8 x 16.0 mm, 11 parts (0 on the bottom side), 9 nets, no tracks yet.

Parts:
C1: C_Disc_D3.0mm_W2.0mm_P2.50mm
J1, J2: JST_PH_S3B-PH-K_1x03_P2.00mm_Horizontal
LED1, LED2, LED3, LED4, LED5: LED_WS2812B-Mini_PLCC4_3.5x3.5mm
MH1, MH2: MountingHole_2.2mm_M2
R1: R_Axial_DIN0207_L6.3mm_D2.5mm_P2.54mm_Vertical

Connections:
DATA_0: J1.3, R1.1
DATA_1: LED1.4, R1.2
DATA_2: LED1.2, LED2.4
DATA_3: LED2.2, LED3.4
DATA_4: LED3.2, LED4.4
DATA_5: LED4.2, LED5.4
DATA_6: J2.3, LED5.2
GND: C1.2, J1.1, J2.1, LED1.3, LED2.3, LED3.3, LED4.3, LED5.3
VCC: C1.1, J1.2, J2.2, LED1.1, LED2.1, LED3.1, LED4.1, LED5.1

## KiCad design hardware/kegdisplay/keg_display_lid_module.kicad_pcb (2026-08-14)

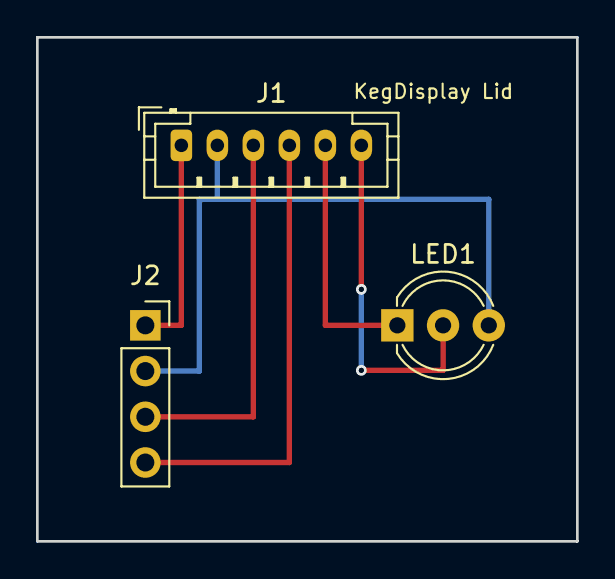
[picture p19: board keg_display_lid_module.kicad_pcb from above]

Board: 2 copper layers, 30.0 x 28.0 mm, 3 parts (0 on the bottom side), 6 nets.

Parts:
J1: JST_PH_B6B-PH-K_1x06_P2.00mm_Vertical
J2: PinSocket_1x04_P2.54mm_Vertical
LED1: LED_D5.0mm-3

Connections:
GND: J1.2, J2.2, LED1.3
GREEN_LED: J1.6, LED1.2
SCL: J1.3, J2.3
SDA: J1.4, J2.4
VCC: J1.1, J2.1
YELLOW_LED: J1.5, LED1.1

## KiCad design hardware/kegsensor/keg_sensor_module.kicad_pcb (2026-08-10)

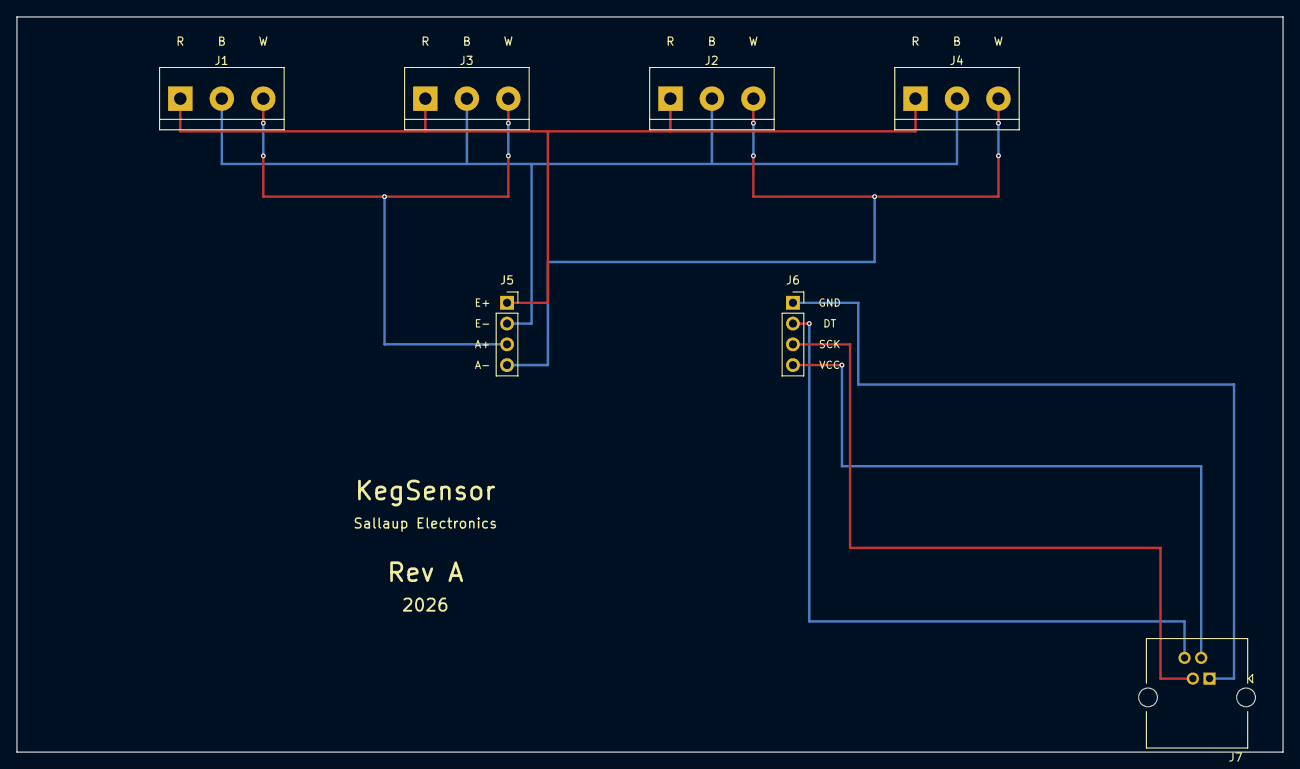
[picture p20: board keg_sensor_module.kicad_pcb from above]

Board: 2 copper layers, 155.0 x 90.0 mm, 7 parts (0 on the bottom side), 8 nets.

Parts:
J1, J2, J3, J4: TerminalBlock_bornier-3_P5.08mm
J5, J6: PinSocket_1x04_P2.54mm_Vertical
J7: RJ14_Connfly_DS1133-S4_Horizontal

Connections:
DT: J6.2, J7.4
EXC_NEG: J1.2, J2.2, J3.2, J4.2, J5.2
EXC_POS: J1.1, J2.1, J3.1, J4.1, J5.1
GND: J6.1, J7.1
SCK: J6.3, J7.3
SIG_NEG: J2.3, J4.3, J5.4
SIG_POS: J1.3, J3.3, J5.3
VCC_3V3: J6.4, J7.2

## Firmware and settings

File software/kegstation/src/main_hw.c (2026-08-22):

/* KegStation real-hardware entry point -- NOT the simulator (see main.c).
 * Runs the exact same UI code (ui.c / kegstation_ui_build()) but drives
 * a real ILI9488 SPI TFT + 5 discrete GPIO buttons via pigpio, instead
 * of an SDL2 window + keyboard.
 *
 * Not yet buildable or tested -- there's no CMake target for this file,
 * and it can't be, until real hardware exists to test against (same
 * "validate before calling it done" standard as the rest of this
 * project -- see hardware/kegstation/README.md). Treat this as a
 * verified-API skeleton, not working code: every LVGL call here was
 * checked against the actual v9.6 headers in extern/lvgl, but the GPIO
 * pin numbers and ILI9488 init register values are still placeholders
 * (see hardware/kegstation/README.md's "Still Open" -- GPIO pin
 * assignment for the nav buttons isn't decided yet either).
 *
 * Build (once on real hardware, not from this CMake project):
 *   gcc main_hw.c ui.c -o kegstation \
 *       -I extern/lvgl/include -I. \
 *       $(find extern/lvgl -name '*.c' ! -path '*/drivers/*' ...) \
 *       -lpigpio -lrt -lpthread -lm
 * (a real build would compile LVGL as a static lib with LV_USE_SDL=0,
 * same lv_conf.h otherwise -- not set up here since there's nothing to
 * link/test against yet)
 */

#include <pigpio.h>
#include <stdint.h>
#include <unistd.h>
#include "lvgl/lvgl.h"
#include "ui.h"

/* ---- Pin assignment: PLACEHOLDER, see kegstation/README.md's
 * "Still Open" -- GPIO pin mapping for the shared-SCK/6xDT KegSensor
 * scheme AND the 5 nav buttons are both still undecided. ---- */
#define PIN_DC     24
#define PIN_RESET  25
#define PIN_BTN_UP     5
#define PIN_BTN_DOWN   6
#define PIN_BTN_LEFT  13
#define PIN_BTN_RIGHT 19
#define PIN_BTN_SELECT 26

#define SPI_CHANNEL 0
#define SPI_BAUD 32000000

#define SCREEN_W 480
#define SCREEN_H 320

static int spi_handle;

/* ---- Same low-level SPI helpers as the earlier standalone TFT demo ---- */

static void write_cmd(uint8_t cmd) {
    gpioWrite(PIN_DC, 0);
    spiWrite(spi_handle, (char *)&cmd, 1);
}

static void write_data(const uint8_t *data, int len) {
    gpioWrite(PIN_DC, 1);
    spiWrite(spi_handle, (char *)data, len);
}

static void write_data8(uint8_t d) { write_data(&d, 1); }

/* Typical published ILI9488 init sequence -- verify against the real
 * module once it's on the bench, same caveat as before re: this module
 * sometimes shipping as ILI9484 instead. */
static void ili9488_init(void) {
    gpioWrite(PIN_RESET, 0);
    usleep(20000);
    gpioWrite(PIN_RESET, 1);
    usleep(150000);

    write_cmd(0x01); /* software reset */
    usleep(150000);

    write_cmd(0x11); /* sleep out */
    usleep(150000);

    write_cmd(0x3A); /* interface pixel format */
    write_data8(0x55); /* 16-bit/pixel, matches LV_COLOR_FORMAT_RGB565 below */

    write_cmd(0x36); /* memory access control (orientation) */
    write_data8(0x48); /* adjust if the image comes out mirrored/rotated */

    write_cmd(0xC2);
    write_data8(0x44);

    write_cmd(0xC5);
    { uint8_t d[4] = {0x00, 0x00, 0x00, 0x00}; write_data(d, 4); }

    write_cmd(0x21); /* display inversion on */
    write_cmd(0x29); /* display ON */
    usleep(50000);
}

static void set_window(int x0, int y0, int x1, int y1) {
    write_cmd(0x2A);
    uint8_t colbuf[4] = { x0 >> 8, x0 & 0xFF, x1 >> 8, x1 & 0xFF };
    write_data(colbuf, 4);

    write_cmd(0x2B);
    uint8_t rowbuf[4] = { y0 >> 8, y0 & 0xFF, y1 >> 8, y1 & 0xFF };
    write_data(rowbuf, 4);

    write_cmd(0x2C); /* memory write */
}

/* ---- LVGL display driver: flush callback pushes LVGL's rendered
 * buffer over SPI instead of into an SDL2 window. ---- */

static void disp_flush_cb(lv_display_t * disp, const lv_area_t * area, uint8_t * px_map) {
    int32_t w = area->x2 - area->x1 + 1;
    int32_t h = area->y2 - area->y1 + 1;

    set_window(area->x1, area->y1, area->x2, area->y2);
    gpioWrite(PIN_DC, 1);
    spiWrite(spi_handle, (char *)px_map, w * h * 2 /* RGB565 = 2 bytes/px */);

    lv_display_flush_ready(disp);
}

/* Draw buffer: a partial buffer (40 rows) rather than a full 480x320
 * frame, to keep RAM use modest on the Zero 2 W's 512MB. */
static uint8_t draw_buf[SCREEN_W * 40 * 2];

/* ---- LVGL input driver: reads the 5 discrete nav buttons instead of
 * SDL keyboard events. Simple digital reads, active-low assumed
 * (button to GND, internal pull-up) -- adjust once real wiring exists. ---- */

static void keypad_read_cb(lv_indev_t * indev, lv_indev_data_t * data) {
    (void)indev;

    if (gpioRead(PIN_BTN_UP) == 0)          { data->key = LV_KEY_UP;    data->state = LV_INDEV_STATE_PRESSED; }
    else if (gpioRead(PIN_BTN_DOWN) == 0)   { data->key = LV_KEY_DOWN;  data->state = LV_INDEV_STATE_PRESSED; }
    else if (gpioRead(PIN_BTN_LEFT) == 0)   { data->key = LV_KEY_LEFT;  data->state = LV_INDEV_STATE_PRESSED; }
    else if (gpioRead(PIN_BTN_RIGHT) == 0)  { data->key = LV_KEY_RIGHT; data->state = LV_INDEV_STATE_PRESSED; }
    else if (gpioRead(PIN_BTN_SELECT) == 0) { data->key = LV_KEY_ENTER; data->state = LV_INDEV_STATE_PRESSED; }
    else                                    { data->state = LV_INDEV_STATE_RELEASED; }
}

/* ---- Tick source: pigpio's own microsecond tick, matching the pattern
 * the SDL driver uses (lv_tick_set_cb(SDL_GetTicks)) -- no manual
 * lv_tick_inc() needed, LVGL calls this whenever it needs the time. ---- */

static uint32_t tick_get_cb(void) {
    return gpioTick() / 1000; /* microseconds -> milliseconds */
}

int main(void) {
    if (gpioInitialise() < 0) return 1;

    gpioSetMode(PIN_DC, PI_OUTPUT);
    gpioSetMode(PIN_RESET, PI_OUTPUT);
    gpioSetMode(PIN_BTN_UP, PI_INPUT);
    gpioSetMode(PIN_BTN_DOWN, PI_INPUT);
    gpioSetMode(PIN_BTN_LEFT, PI_INPUT);
    gpioSetMode(PIN_BTN_RIGHT, PI_INPUT);
    gpioSetMode(PIN_BTN_SELECT, PI_INPUT);
    gpioSetPullUpDown(PIN_BTN_UP, PI_PUD_UP);
    gpioSetPullUpDown(PIN_BTN_DOWN, PI_PUD_UP);
    gpioSetPullUpDown(PIN_BTN_LEFT, PI_PUD_UP);
    gpioSetPullUpDown(PIN_BTN_RIGHT, PI_PUD_UP);
    gpioSetPullUpDown(PIN_BTN_SELECT, PI_PUD_UP);

    spi_handle = spiOpen(SPI_CHANNEL, SPI_BAUD, 0);
    if (spi_handle < 0) return 1;

    ili9488_init();

    lv_init();
    lv_tick_set_cb(tick_get_cb);

    lv_display_t * disp = lv_display_create(SCREEN_W, SCREEN_H);
    lv_display_set_color_format(disp, LV_COLOR_FORMAT_RGB565);
    lv_display_set_buffers(disp, draw_buf, NULL, sizeof(draw_buf),
                            LV_DISPLAY_RENDER_MODE_PARTIAL);
    lv_display_set_flush_cb(disp, disp_flush_cb);

    lv_indev_t * keypad = lv_indev_create();
    lv_indev_set_type(keypad, LV_INDEV_TYPE_KEYPAD);
    lv_indev_set_read_cb(keypad, keypad_read_cb);

    kegstation_ui_build();
    lv_indev_set_group(keypad, kegstation_ui_get_group());

    while (1) {
        uint32_t time_till_next = lv_timer_handler();
        if (time_till_next == LV_NO_TIMER_READY) {
            time_till_next = 50;
        }
        usleep(time_till_next * 1000);
    }

    return 0;
}

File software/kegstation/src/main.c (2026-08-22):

/* KegStation UI simulator -- runs the real on-unit UI code (ui.c) in an
 * SDL2 desktop window instead of on the real Pi Zero 2 W + ILI9488 TFT.
 * Arrow keys navigate, Enter selects -- same up/down/left/right/select
 * scheme as the 5 discrete GPIO buttons on real hardware (see
 * hardware/kegstation/README.md). Only this file and the eventual real
 * SPI/GPIO driver differ between simulator and hardware builds -- ui.c
 * is identical either way. */

#include "lvgl/lvgl.h"
#include "ui.h"
#include <SDL2/SDL.h>

int main(void)
{
    lv_init();

    lv_sdl_window_create(480, 320);
    lv_sdl_mouse_create();
    lv_sdl_mousewheel_create();
    lv_indev_t * keyboard = lv_sdl_keyboard_create();

    kegstation_ui_build();
    lv_indev_set_group(keyboard, kegstation_ui_get_group());

    while (1) {
        uint32_t time_till_next = lv_timer_handler();
        if (time_till_next == LV_NO_TIMER_READY) {
            time_till_next = 50;
        }
        SDL_Delay(time_till_next);
    }

    return 0;
}

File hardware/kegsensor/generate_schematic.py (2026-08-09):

import re, uuid, pathlib

LIB_PATH = "/Applications/KiCad/KiCad.app/Contents/SharedSupport/symbols/Connector_Generic.kicad_sym"
OUT_DIR = pathlib.Path(__file__).resolve().parent
OUT_DIR.mkdir(parents=True, exist_ok=True)
PROJECT_NAME = "keg_sensor_module"
SCH_PATH = OUT_DIR / f"{PROJECT_NAME}.kicad_sch"

def extract_balanced(text, start_idx):
    depth = 0
    for i in range(start_idx, len(text)):
        c = text[i]
        if c == '(':
            depth += 1
        elif c == ')':
            depth -= 1
            if depth == 0:
                return text[start_idx:i+1]
    raise ValueError("unbalanced")

lib_text = open(LIB_PATH).read()

def get_symbol_block(name):
    idx = lib_text.index(f'(symbol "{name}"')
    block = extract_balanced(lib_text, idx)
    # qualify only the top-level symbol name (first occurrence at start of block)
    qualified = block.replace(f'(symbol "{name}"', f'(symbol "Connector_Generic:{name}"', 1)
    return qualified

conn3 = get_symbol_block("Conn_01x03")
conn4 = get_symbol_block("Conn_01x04")

def new_uuid():
    return str(uuid.uuid4())

ROOT_UUID = new_uuid()

# --- Component/net plan --------------------------------------------------
# J1-J4: half-bridge sensor terminals (3 pins: E+, E-, SIG)
# Diagonal corner pairing: J1(FL)+J3(BR) -> SIG_POS ; J2(FR)+J4(BL) -> SIG_NEG
# J5: HX711 header, load-cell side  -> pin1=E+ pin2=E- pin3=A+ pin4=A-
# J6: HX711 header, digital/power side -> pin1=GND pin2=DT pin3=SCK pin4=VCC
#     (verify against the specific module's silkscreen; order varies by vendor)
# J7: RJ11 jack -> pin1=GND(Black) pin2=VCC(Red) pin3=SCK(Green) pin4=DT(Yellow)
#     (must match the in-keezer hub's RJ11 pin convention for a straight cable)

PIN_DX = -5.08  # pin connection point x-offset from symbol origin (angle 0)
STUB = 2.54     # extra wire length from pin to label anchor
GRID = 1.27     # KiCad's default schematic connection grid (50 mil)

def snap(v):
    return round(round(v / GRID) * GRID, 2)

components = []  # each: dict(ref, lib, at, pins: [(num, net, label_side)])

def sensor(ref, x, y, corner):
    return dict(ref=ref, lib="Conn_01x03", at=(x, y), value=f"Sensor_{corner}",
                pins=[("1", "EXC_POS"), ("2", "EXC_NEG"), ("3", "SIG_POS" if corner in ("FL", "BR") else "SIG_NEG")],
                footprint="TerminalBlock:TerminalBlock_bornier-3_P5.08mm")

components.append(sensor("J1", 60, 30, "FL"))
components.append(sensor("J2", 60, 60, "FR"))
components.append(sensor("J3", 60, 90, "BR"))
components.append(sensor("J4", 60, 120, "BL"))

components.append(dict(ref="J5", lib="Conn_01x04", at=(150, 45), value="HX711_LoadCell_Side",
                        pins=[("1", "EXC_POS"), ("2", "EXC_NEG"), ("3", "SIG_POS"), ("4", "SIG_NEG")],
                        footprint="Connector_PinSocket_2.54mm:PinSocket_1x04_P2.54mm_Vertical"))

components.append(dict(ref="J6", lib="Conn_01x04", at=(150, 105), value="HX711_Digital_Side",
                        pins=[("1", "GND"), ("2", "DT"), ("3", "SCK"), ("4", "VCC_3V3")],
                        footprint="Connector_PinSocket_2.54mm:PinSocket_1x04_P2.54mm_Vertical"))

components.append(dict(ref="J7", lib="Conn_01x04", at=(240, 75), value="RJ11_to_Hub",
                        pins=[("1", "GND"), ("2", "VCC_3V3"), ("3", "SCK"), ("4", "DT")],
                        footprint=""))

# --- Build symbol instances + wires + labels ------------------------------

def indent(s, n):
    pad = "\t" * n
    return "\n".join(pad + line if line.strip() else line for line in s.split("\n"))

def prop(name, val, x, y, angle, hide=False, size=1.27):
    hide_s = "\n\t\t\t\t(hide yes)" if hide else ""
    return f'''\t\t(property "{name}" "{val}"
\t\t\t(at {x} {y} {angle})
\t\t\t(effects
\t\t\t\t(font
\t\t\t\t\t(size {size} {size})
\t\t\t\t){hide_s}
\t\t\t)
\t\t)'''

def sym_instance(ref, lib, x, y, value, footprint):
    u = new_uuid()
    pins_block = ""
    npins = 3 if lib == "Conn_01x03" else 4
    pin_uuids = []
    for i in range(1, npins + 1):
        pu = new_uuid()
        pin_uuids.append(pu)
        pins_block += f'\t\t(pin "{i}"\n\t\t\t(uuid "{pu}")\n\t\t)\n'
    ref_prop = prop("Reference", ref, x, y - 10, 0)
    val_prop = prop("Value", value, x, y + (10 if lib == "Conn_01x03" else 13), 0)
    fp_prop = prop("Footprint", footprint, x, y, 0, hide=True)
    ds_prop = prop("Datasheet", "~", x, y, 0, hide=True)
    block = f'''\t(symbol
\t\t(lib_id "Connector_Generic:{lib}")
\t\t(at {x} {y} 0)
\t\t(unit 1)
\t\t(exclude_from_sim no)
\t\t(in_bom yes)
\t\t(on_board yes)
\t\t(dnp no)
\t\t(uuid "{u}")
{ref_prop}
{val_prop}
{fp_prop}
{ds_prop}
{pins_block}\t\t(instances
\t\t\t(project "{PROJECT_NAME}"
\t\t\t\t(path "/{ROOT_UUID}"
\t\t\t\t\t(reference "{ref}")
\t\t\t\t\t(unit 1)
\t\t\t\t)
\t\t\t)
\t\t)
\t)'''
    return block

def wire_and_label(px, py, net, pin_dx_sign=-1):
    # stub extends further in -X from the pin connection point
    ex = px + pin_dx_sign * STUB
    ey = py
    wu = new_uuid()
    lu = new_uuid()
    wire = f'''\t(wire
\t\t(pts
\t\t\t(xy {px} {py}) (xy {ex} {ey})
\t\t)
\t\t(stroke
\t\t\t(width 0)
\t\t\t(type default)
\t\t)
\t\t(uuid "{wu}")
\t)'''
    label = f'''\t(label "{net}"
\t\t(at {ex} {ey} 0)
\t\t(effects
\t\t\t(font
\t\t\t\t(size 1.27 1.27)
\t\t\t)
\t\t\t(justify right)
\t\t)
\t\t(uuid "{lu}")
\t)'''
    return wire, label

symbol_blocks = []
wire_blocks = []
label_blocks = []
text_blocks = []

def add_text(msg, x, y, size=1.5):
    tu = new_uuid()
    text_blocks.append(f'''\t(text "{msg}"
\t\t(at {x} {y} 0)
\t\t(effects
\t\t\t(font
\t\t\t\t(size {size} {size})
\t\t\t)
\t\t)
\t\t(uuid "{tu}")
\t)''')

for c in components:
    x, y = snap(c["at"][0]), snap(c["at"][1])
    symbol_blocks.append(sym_instance(c["ref"], c["lib"], x, y, c["value"], c["footprint"]))
    pin_dy_start = 2.54  # pin 1 offset from symbol origin, per library def
    for num, net in c["pins"]:
        dy = pin_dy_start - (int(num) - 1) * 2.54
        px = x + PIN_DX
        # KiCad negates the symbol-local Y axis when placing at rotation 0
        # (lib editor is Y-up, schematic sheet is Y-down) - confirmed via ERC.
        py = y - dy
        w, l = wire_and_label(px, py, net)
        wire_blocks.append(w)
        label_blocks.append(l)
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

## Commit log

2026-08-09 Add hub wiring doc, keg sensor module schematic/PCB, and 3D-printable case
    Checkpoint before fixing a known bug: the case's RJ11 cutout doesn't
    actually align with J7's position on the board (J7 sits ~14-27mm from
    the nearest case wall, not reachable from outside as designed).
    [case.scad, case_base.stl, case_lid.stl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]
2026-08-09 Fix J7 (RJ11 jack) reachability: move to board edge, rewire, fix case cutout
    J7 was placed mid-board with no path to any wall (13.7mm from the right
    wall, 27mm from the top wall) - the case's cutout, built assuming it was
    near the top edge, didn't align with it at all. Root cause was a stale
    board outline value (145mm instead of 155mm) left over from before the
    mounting holes were added, which also caused knock-on edge-clearance
    DRC errors once J7 moved.
    Fix: rotate J7 -90deg and move it flush with the board's right edge (the
    correct placement for any edge connector, independent of the case),
    rewrite the J6<->J7 routing for the new pad positions, fix the stale
    outline, and move the case's c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
    [case.scad, case_base.stl, case_lid.stl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]
2026-08-09 Brand project as Sallaup Electronics / KegSensor (Sallaup KegSense system)
    Schematic title block, docs, and case.scad header updated. Regenerated
    schematic + PDF, re-ran ERC to confirm still clean.
    [case.scad, keg_sensor_module.kicad_sch]
2026-08-09 Add KegSensor / Sallaup Electronics branding to the PCB silkscreen
    First placement (30,58) overlapped J2/J4's reference-label silkscreen -
    DRC caught it (silk_overlap warnings), repositioned into the clear gap
    between J2 and J4 and re-verified DRC comes back clean (down to the same
    2 pre-existing cosmetic warnings as before: J7's silkscreen slightly
    clipped by the board edge, and a footprint-metadata diff, neither
    electrical).
    [keg_sensor_module.kicad_pcb]
2026-08-09 Add Rev A / 2026 to the PCB silkscreen
    Placed in the open area right of J5/below the J6<->J7 routing (that
    routing stays y<=52; nothing else occupies x=60-155, y=52-90). DRC still
    clean (same 2 pre-existing cosmetic warnings, no new overlaps).
    [keg_sensor_module.kicad_pcb]
2026-08-09 Add KegSensor / Sallaup Electronics branding to the right side too
    Now appears on both the left (with J1-J4) and right (with Rev A / 2026)
    open areas. DRC still clean.
    [keg_sensor_module.kicad_pcb]
2026-08-09 Remove left-side KegSensor / Sallaup Electronics silkscreen text, keep right-side copy only
    [keg_sensor_module.kicad_pcb]
2026-08-09 Add fabrication deliverables: Gerbers + drill files for the PCB manufacturer
    Generated via kicad-cli pcb export gerbers/drill (standard 2-layer set:
    copper, mask, silk, paste, edge cuts, PTH+NPTH drill). Zipped as
    KegSensor_RevA_gerbers.zip - that's the single file to hand to a fab
    house; individual files also kept in fab/ for fabs that want them
    uploaded one at a time. README documents what's in the package and how
    to regenerate it.
    [keg_sensor_module-B_Cu.gbl, keg_sensor_module-B_Mask.gbs, keg_sensor_module-B_Paste.gbp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]
2026-08-09 Emboss KegSensor / Sallaup Electronics on the case lid
    Raised 0.6mm text via OpenSCAD's text() primitive (generated directly
    from the branding strings, not hand-drawn), centered on the lid's outer
    top face, clear of the 4 corner screw posts. case_lid.stl still validates
    as Simple: yes after the emboss union; verified placement with a shaded
    close-up render.
    [case.scad, case_base.stl, case_lid.stl]
2026-08-09 Move case branding from lid (raised) to base walls (engraved)
    Sallaup Electronics on the front wall, KegSensor on the back - the two
    walls without a connector cutout already. Lid is now plain.
    Getting the engraving oriented correctly took two real iterations, not
    one lucky guess: a first attempt read upside-down on a 3D perspective
    render, which I "fixed" with a 180deg rotation - that turned out to
    correct the vertical flip but introduce a horizontal mirror instead,
    only caught by switching to true 2D orthographic projections of each
    wall from its own outside-viewer angle. The front and back walls needed
    different fixes for a real reason (not just two wrong guesses): a viewer
    standing behin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
    [case.scad, case_base.stl, case_lid.stl]
2026-08-09 Consolidate case branding to front wall only, smaller, subtitle italic
    Both lines now engraved on the front wall instead of split front/back:
    KegSensor (bold, size 5) above Sallaup Electronics (italic, size 2.6, as
    a smaller subtitle line). Back wall is plain again. wall_text_back()
    kept in case.scad unused, in case a wall carries text again later.
    Verified with the same true-2D-orthographic-projection check as before -
    case_base.stl still Simple: yes, both lines read correctly right-side up.
    [case.scad, case_base.stl, case_lid.stl]
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2026-08-09 Design the tare/weight calibration workflow (CLI-first)
    kegcal companion tool: 'tare <keg>' and 'setfull <keg> <grams>', reading
    live raw ADC values from the daemon's readings file and writing them to
    a separate calibration config the daemon re-reads on its normal cycle -
    no IPC needed. Chosen over a dashboard UI since the dashboard doesn't
    exist yet; it can shell out to the same commands later.
    Explicitly holding off on writing the daemon/kegcal code until a real Pi
    + HX711 setup is available to test against, per user preference -
    noted in Still Open rather than writing untestable GPIO code now.
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2026-08-09 Add load_cell_holder.scad: derived from a Printables snap-fit design
    Same-dimension recreation as editable OpenSCAD instead of an opaque
    third-party STL, matching how the rest of this project's parts are
    built. Dimensions measured directly from the downloaded reference STL
    (2D cross-section slices + point-cloud analysis), not guessed.
    Caught a real bug during validation: a first render made the ear tabs
    look disconnected from the collar. Rather than trust that perspective
    render, checked the actual 2D outline (confirmed single closed contour)
    and a top-down height-colored projection - both showed the geometry was
    actually fine and the gap was a rendering artifact, not a real defect.
    Widened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
    [load_cell_holder.scad, load_cell_holder.stl]
2026-08-09 Add cable exit notch to the derived load cell holder
    The original design has no cable exit - verified directly (2D
    cross-section + top-down height projection at multiple heights showed
    the pocket fully enclosed on all sides, and the flex-seam slit doesn't
    reach the pocket opening), not assumed. Without a notch, a cable coming
    off the load cell would have to share the same pocket opening as the
    load cell body itself.
    Added a 6mm-wide, full-height notch through the pocket wall on the -Y
    side (opposite the seam slit, keeping the two features separated).
    Still validates as Simple: yes; verified the notch is a clean
    full-height through-cut via the same top-down projection method.
    [load_cell_holder.scad, load_cell_holder.stl]
2026-08-09 Make the cable notch half-height, at the bottom, not full-height
    z=0-4mm of the 8mm total, leaving solid material as a roof over the
    cable exit instead of opening the full side. Verified with a Y-Z
    cross-section at x=0: the notch side shows material only from z=4-8
    (bottom half open), the seam side stays untouched at full height.
    Still Simple: yes.
    [load_cell_holder.scad, load_cell_holder.stl]
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2026-08-09 Reorganize hardware/ into kegsensor, keghub, kegstation
    hardware/ now contains exactly three subdirectories matching the three
    physical units: kegsensor/ (per-keg carrier board, case, load cell
    platform, sensor wiring), keghub/ (in-keezer passive panel), and
    kegstation/ (moved from repo root). Split hub-wiring.md into
    kegsensor/wiring.md (sensor-side) and keghub/README.md (hub-side) along
    the same boundary. Updated hardcoded output paths in generate_schematic.py
    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
    [case.scad, case_base.stl, case_lid.stl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]
2026-08-09 Split hub-wiring.md and fix cross-references after the reorg
    Split the old combined hub-wiring.md into hardware/kegsensor/wiring.md
    (per-keg sensor wiring) and hardware/keghub/README.md (passive panel
    wiring), along the KegSensor/KegHub boundary. Fixed hardcoded output
    paths in generate_schematic.py/generate_pcb.py, the embedded doc
    reference in the schematic's J7 annotation text, and all remaining
    markdown/gitignore references to the old directory names.
    [keg_sensor_module.kicad_sch, load_cell_holder.scad]
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2026-08-09 Move KegSensor's J1-J4 sensor terminals to a horizontal row near the top edge
    Previously a vertical column near the left edge. Rotated each terminal
    block -90deg so its 3 pins stack in Y instead of spreading in X - without
    that, all 4 parts' pins would land on identical y-values and the
    EXC_POS/EXC_NEG/SIG_POS/SIG_NEG buses couldn't cross the row without
    shorting. Rerouted the J1-J4<->J5 bus accordingly; went through a couple
    of DRC-guided rounds after straight diagonals cut through unrelated pads
    (J2's own pad, then J5's adjacent pad) and an existing J6<->J7 GND trace
    that now ran too close to J4's new position.
    Also fixed a latent bug the multi-instance footprint copies exposed:
    generate_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
    [case.scad, case_base.stl, keg_sensor_module.kicad_pcb]
2026-08-10 Un-rotate J1-J4, move J7 to the bottom edge, redesign all routing
    J1-J4 back to angle=0 (unrotated) per explicit request - loses the
    trivial per-pin bus that rotation gave, so the row now needs dedicated
    lanes with layer alternation (EXC_POS on F.Cu, EXC_NEG on B.Cu) and via
    hops (SIG_POS/SIG_NEG, which must cross both) to reach J5 without
    shorting.
    J7 moved from the right edge to the bottom edge (angle=180, verified via
    actual DRC-reported pad/courtyard coordinates rather than assumed). Its
    GND/SCK/VCC/DT approaches from J6 are redesigned around the same tight
    ~1mm pad spacing as before, just transposed to the new geometry -
    straight verticals into GND/SCK grazed the adjacent VCC pad, fixe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
    [case.scad, case_base.stl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]
2026-08-10 Route J6->J7 traces east first instead of west
    Each net's initial jog off J6 now heads toward J7 (east) before turning
    down to its lane, rather than doubling back west first. This flips
    which net needs the shallowest lane: since every lane still extends the
    rest of the way east to J7 regardless of where its own stub sits, the
    depth/stub-position pairing that avoids crossings is the mirror image
    of the west-jog version (shallowest lane <-> stub furthest from J6, not
    closest). DRC clean on the first attempt with the reordered pairing.
    Regenerated fab/ Gerbers, drill files, and PCB renders to match.
    [keg_sensor_module-B_Cu.gbl, keg_sensor_module-B_Mask.gbs, keg_sensor_module-B_Paste.gbp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]
2026-08-10 Simplify J6-J7 routing: single layer per net where possible
    Each of GND/VCC/SCK/DT previously had a short F.Cu stub off J6 before
    via-ing to B.Cu for the rest, on every net - vestigial for two of them.
    GND and SCK are now a single unbroken line on one layer each (B.Cu and
    F.Cu respectively), no vias - J6's pads are through-hole, so a track
    can start on whichever layer it needs directly at the pad.
    VCC_3V3 and DT keep one via each - not a missed simplification but real
    geometry, checked exhaustively rather than just patched around the
    first conflict DRC caught: VCC's own source row at J6 sits inside DT's
    drop's depth range, and DT's row sits inside VCC's, so whichever one is
    in the way at th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
    [keg_sensor_module-B_Cu.gbl, keg_sensor_module-B_Mask.gbs, keg_sensor_module-B_Paste.gbp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]
2026-08-10 Silkscreen R/B/W wire-color labels above J1-J4's pins
    Prints "R B W" above each of J1-J4's 3 pins (pin1=R, pin2=B, pin3=W,
    fixed order on every connector), matching the documented sensor lead
    convention (wiring.md: Red=E+, Black=E-, White=Signal) - so wiring a
    sensor by color doesn't need the README open next to the board.
    Positioned above each connector, between the board edge and the
    connector body, clear of both the edge and each connector's own
    reference designator - verified via DRC (silk_overlap), not just
    eyeballed. DRC clean (1 pre-existing accepted warning).
    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
    [keg_sensor_module-B_Cu.gbl, keg_sensor_module-B_Mask.gbs, keg_sensor_module-B_Paste.gbp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]
2026-08-10 Silkscreen pin labels for J5/J6 (HX711 header)
    E+/E-/A+/A- next to J5's pins, GND/DT/SCK/VCC next to J6's, matching the
    Connectors table. Both are single-column vertical headers (4 pins
    stacked at one X, 2.54mm pitch), so labels sit beside each pin rather
    than above/below like J1-J4's row got. J6's needed extra clearance from
    its own footprint outline - the 3-character labels clipped it at the
    first attempt (DRC: silk_overlap), fixed by pushing them out further.
    DRC clean (1 pre-existing accepted warning). Regenerated fab/ Gerbers,
    drill files, and PCB renders to match.
    [keg_sensor_module-B_Cu.gbl, keg_sensor_module-B_Mask.gbs, keg_sensor_module-B_Paste.gbp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]
2026-08-10 Move J5's HX711 pin labels to the left side
    E+/E-/A+/A- now sit left of J5's pins instead of right, per explicit
    request - opposite side from J6's GND/DT/SCK/VCC labels. DRC clean
    (1 pre-existing accepted warning).
    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
    [keg_sensor_module-B_Cu.gbl, keg_sensor_module-B_Mask.gbs, keg_sensor_module-B_Paste.gbp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]
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2026-08-10 Decide: one OLED per keg at its own tap, not a shared display
    Per explicit request. Updated the root README's system description and
    KegStation's planning doc accordingly, and flagged the two real
    consequences this creates rather than leaving them implicit:
    - I2C addressing: cheap OLEDs (SSD1306 etc.) mostly share a fixed
    address, so 5 on one bus needs a multiplexer (e.g. TCA9548A) or SPI
    instead - not decided yet, added to Still Open.
    - A new physical wiring run from KegStation (outside the keezer) out to
    each tap, which didn't need to exist under the old single-display
    plan - also not yet scoped.
    Also flagged that this weakens (but doesn't rule out) the keypad+OLED
    calibration fr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
2026-08-10 Design KegDisplay: per-tap Nano+OLED board, daisy-chained over RS-485
    Captures the design worked out in conversation for the per-keg display
    decision: instead of bare I2C OLEDs (blocked by their fixed I2C
    address once you have more than ~2 on a bus) or an I2C multiplexer or
    per-display SPI chip-selects, each tap gets a combined Arduino Nano +
    OLED board ("KegDisplay") with two RS-485 connectors so they daisy-chain
    tap to tap on one cable instead of five home-runs back to KegStation.
    Covers why this solves both the addressing problem (a microcontroller's
    node address is firmware-assigned, unlike a fixed OLED driver address)
    and the long-cable problem (RS-485 is built for long multi-drop runs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
2026-08-11 Choose chain-position auto-addressing for KegDisplay, with EEPROM refinement
    Records the addressing decision worked out in conversation: hardware
    switches would be the simpler, more robust choice at this scale (5
    hand-built units), but chain-position auto-addressing was picked
    anyway as the more interesting build, with its trade-off understood
    going in rather than overlooked.
    Key refinement that makes it viable: persisting each board's address
    in EEPROM after first assignment means a board skips the discovery
    handshake entirely on future boots and starts responding immediately -
    confining the "dead board blocks everything downstream" fragility to
    initial commissioning only, not normal opera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
2026-08-11 Add a wiring diagram PNG for KegSensor
    Generated with matplotlib (generate_wiring_diagram.py), not hand-drawn,
    so it's easy to regenerate after edits and every pin label/wire color
    traces directly from the documented signal paths rather than being a
    separate, driftable source of truth: 4 load cell sensors -> KegSensor
    PCB (J1-J4, R/B/W = E+/E-/Signal) -> internal EXC_POS/EXC_NEG/SIG_POS/
    SIG_NEG bus -> HX711 (J5 analog, J6 digital) -> J7 RJ11 -> KegHub, with
    the J6->J7 pin crossing and the RJ11 cable's Black/Red/Green/Yellow
    convention shown explicitly.
    Went through a few layout passes - first draft had J6/J7/KegHub labels
    overlapping and a genuine bug (KegHub's box positioned before the
    ca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
2026-08-11 Fix broken SIG_POS/SIG_NEG wire paths in the diagram; style J6 logically
    Two real fixes, not just cosmetic:
    1. The SIG_POS (J1+J3 -> A+) and SIG_NEG (J2+J4 -> A-) bus lines had a
    genuine gap in them: the vertical bus segment only spanned between
    its two source sensors' own Y position, never actually reaching A+/
    A-'s Y on J5, so the final stub into J5 was a disconnected floating
    segment with no wire actually joining it to the rest of the path.
    Extended both vertical segments to reach their target pin's Y.
    2. A+ (SIG_POS) is now dotted, not solid, matching A- (SIG_NEG)'s
    dashed style - both signal paths now read clearly as distinct from
    the solid EXC_POS/EXC_NEG bus lin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
2026-08-11 Uniform wire thickness; fix EXC_POS/EXC_NEG bus overshoot past J1/J4
    Two fixes, both per explicit request:
    1. Every wire in the diagram is now the same thickness (1.8), matching
    what the J1-J4<->J5 bus already used. Previously ranged from 0.8
    (the HX711 fan-out lines) to 2.2 (the RJ11 cable to KegHub) with no
    consistent logic - now visually uniform throughout.
    2. The EXC_POS (red) and EXC_NEG (black) vertical bus lines spanned a
    hardcoded [15, 81], not the sensors' actual tap points - overshooting
    past J4's real corner at the bottom and J1's at the top, making the
    bus look like it kept going rather than terminating where it actually
    connects. Now computed from the real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
2026-08-11 KegDisplay: auto-detecting ENABLE, Modbus RTU, 12V supply, status LED
    Switch the ENABLE wiring from fixed ENABLE_IN/ENABLE_OUT pins to a
    per-jack auto-detecting scheme so a cable plugged into the "wrong" of
    the two identical RJ12 jacks doesn't break the chain past that board -
    see enable_wiring_options.png for the failure case this avoids.
    Also locks in Modbus RTU as the RS-485 protocol (KegStation as master),
    12V as the chain supply voltage, and adds a yellow/green status LED
    spec (solid green while polled, blinking green on a missed heartbeat).
    [generate_enable_wiring_diagram.py]
2026-08-11 KegDisplay: first KiCad schematic (ERC-clean)
    Full circuit per the README's decisions so far: RJ12 daisy-chain jacks
    with auto-detect ENABLE on separate GPIOs, the Q1/R1/D1 reverse-polarity
    protection, a socketed Arduino Nano, MAX485 with a DNP 120R termination
    resistor, OLED header + I2C pull-ups, and the yellow/green status LED.
    0 ERC errors; 2 expected warnings from embedding customized copies of
    library parts (AO3401A, MAX485) directly into the file, same technique
    kegsensor/generate_schematic.py uses.
    Layout is a first pass - the protection-circuit corner is visually
    cramped and will need a spacing pass, deferred for now.
    [keg_display_module.kicad_sch]
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2026-08-19 KegSensor: perfboard-first prototype plan, defer PCB to Phase 6
    Validate wiring assumptions and the 3.5mm terminal block swap on
    hand-wired perfboard before fabbing the custom PCB, instead of the
    old fab-1-validate-fab-4 split.
2026-08-19 KegStation: swap Pi 4 + Touch Display 2 for Zero 2 W + button/OLED
    Dropping the touchscreen for a cheaper 2.42" I2C OLED + physical
    navigation buttons also removes the only reason Zero 2 W was ruled
    out (the Touch Display 2's DSI requirement), unlocking a smaller and
    cheaper board. pigpio and the KegSensor-interfacing scheme carry over
    unchanged since Zero 2 W uses the same GPIO peripheral family as Pi
    3/4, not Pi 5's RP1.
2026-08-19 KegStation: swap OLED for 4.0" color TFT (ILI9488, no touch)
    Trades the 2.42" monochrome OLED for a 480x320 color IPS panel to
    leave room for a richer on-unit UI later (WiFi bars, brew name, level
    graphs) without another hardware swap. Still button-driven (No Touch
    variant), still fits comfortably within Zero 2 W's GPIO and RAM via a
    lightweight embedded graphics library rather than a browser stack.
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2026-08-19 KegStation: detect disconnected KegSensor cables, show red/green status
    RJ14 wiring has no spare conductor for a dedicated presence signal, so
    detection is inferred from HX711 protocol behavior: a per-keg DT
    timeout watchdog flags a keg as not-responding if its DT line produces
    no ready-pulse within 2-3x the expected interval. Surfaced on-unit as
    a red/green per-keg indicator next to each fill level, so a
    disconnected sensor doesn't silently read as an empty keg.
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2026-08-22 KegStation UI: replace keg-select list with Cornelius keg icons
    The startup screen now draws 5 Cornelius-keg icons in a row (rounded
    steel body, two gas-in/liquid-out posts, a vertical amber lv_bar inset
    into the body for fill level, red/green sensor-status dot) instead of
    a plain text list. Fill levels and sensor status are still faked --
    real data comes from the daemon's readings file once it exists.
    Verified building and running: 5 kegs at varied fake fill levels,
    click/keyboard navigation into the per-keg detail screen still works.
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2026-08-22 KegStation UI: drift keg levels over time in the simulator
    A 1s lv_timer randomly nudges each keg's level (+/-3, clamped 0-100)
    and reapplies it through the same update_keg_bar() the initial build
    uses, so color and the critical blink animation start/stop correctly
    as levels cross thresholds instead of just being set once at startup.
    Simulator-only -- real hardware has no equivalent, it reads actual
    levels from the daemon.
    Verified running for several timer ticks without crashing.
2026-08-22 KegStation UI: fix background crop, drop text wordmark for the sign
    LVGL's auto-crop (LV_IMAGE_ALIGN_COVER) didn't handle the portrait
    source well and cut off the "Sallaup" sign. Pre-cropped the image to
    480x320 with Python/Pillow instead (top-anchored crop, keeping the
    sign), sidestepping LVGL's crop logic entirely.
    Removed the "SALLAUP ELECTRONICS / KEGSTATION" text wordmark -- the
    sign in the photo is the branding now. Moved the keg row down
    (KEG_ROW_Y 20->100) so it sits below the sign instead of covering it.
    Verified building and running.
2026-08-22 KegStation UI: fix keg icon photo (full render, dark bg, no base gap)
    LV_IMAGE_ALIGN_STRETCH was silently truncating the tall 155x450 keg
    photo when scaling it down to icon size, showing only the cap/upper
    body -- switched to pre-resizing the photo to its exact on-screen size
    with Python/Pillow instead (same fix already used for the background
    photo), so LVGL just draws it 1:1.
    Also flood-filled the photo's white studio background to the app's
    dark theme color so the icon doesn't look like a floating white card,
    narrowed the fill bar, and extended BODY_TOP/BODY_BOTTOM by a few
    pixels so the bar reaches the black cap/base with no gap of bare steel
    showing.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
